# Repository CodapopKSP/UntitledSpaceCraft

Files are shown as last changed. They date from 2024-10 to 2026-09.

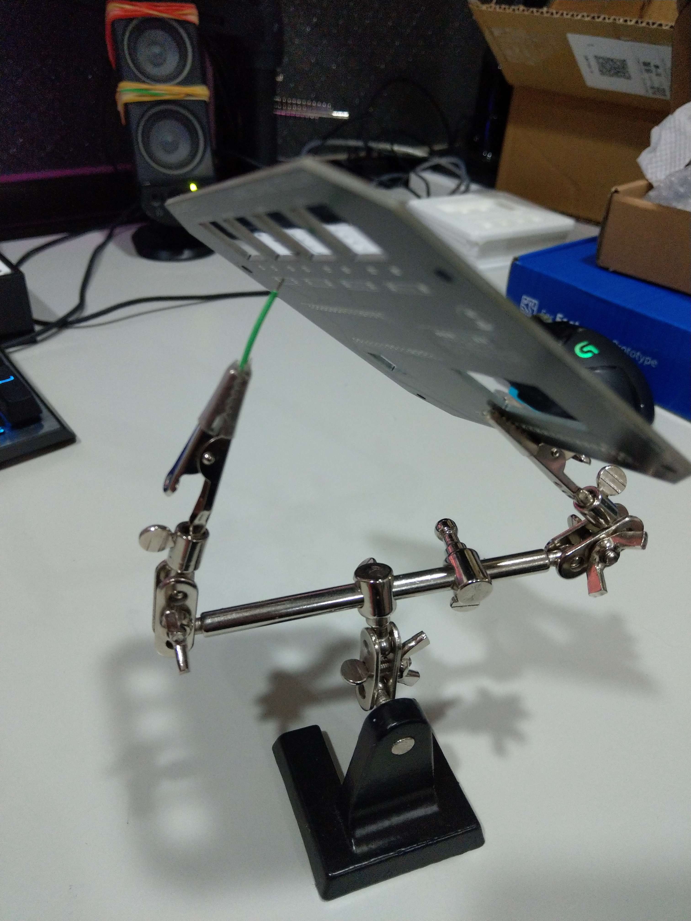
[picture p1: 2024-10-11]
Documents/Complete_Documentation_Source/Source Files/Images/solder_wire.jpg

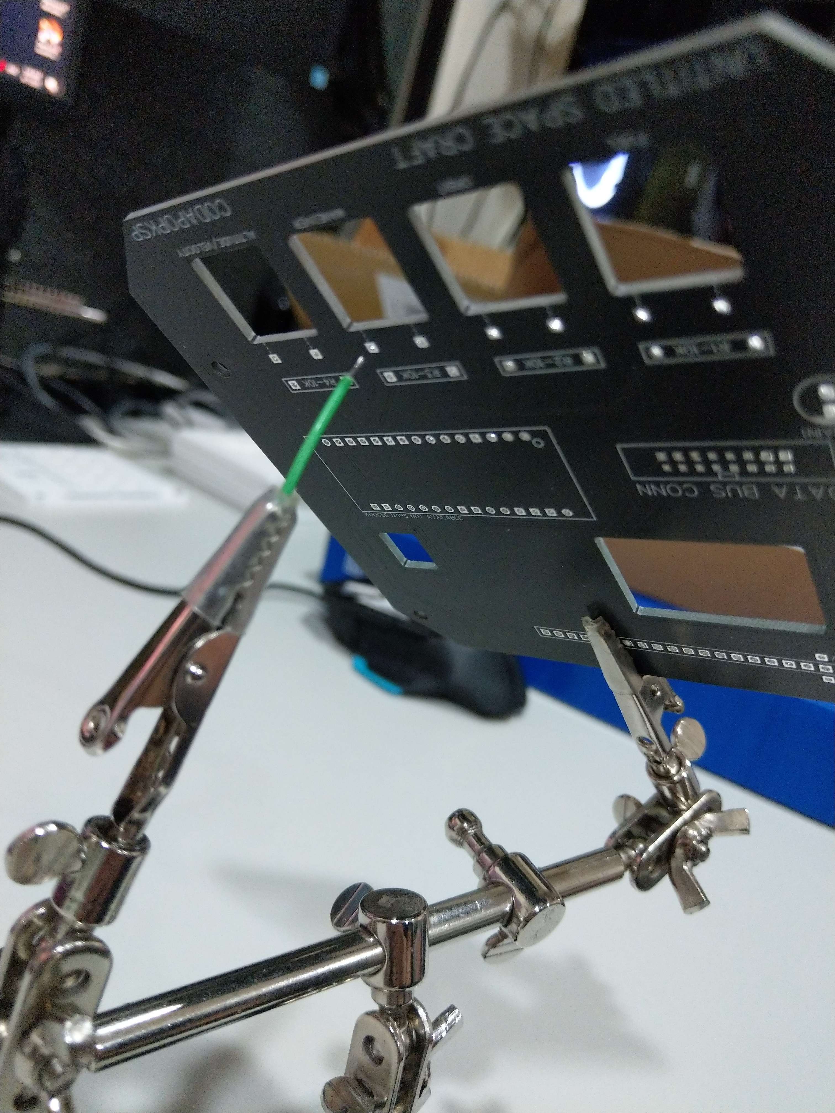
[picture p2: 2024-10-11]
Documents/Complete_Documentation_Source/Source Files/Images/solder_wire2.jpg

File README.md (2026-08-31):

# UntitledSpaceCraft

Animated Controller

Untitled Space Craft is a modular controller system originally developed by Codapop. For build instructions and information, check the releases for updated documentation.

## License

This project is licensed under the [GNU General Public License v3.0 (GPL-3.0)](https://www.gnu.org/licenses/gpl-3.0.html). 

### Important License Terms

While you are free to use, modify, and redistribute the files in this project under the terms of the GPL-3.0, please note the following restrictions regarding commercial use:

- **Commercial Use**: This project is open source for hobby builders and personal use. However, you **may not** sell the hardware or any products derived from this project without explicit permission from the original creator. 

- **Modification**: You are allowed to modify the files for personal or hobby projects.

- **Attribution**: If you use or adapt this project, please give appropriate credit by mentioning the original creator.

## Contributing

Contributions are welcome! If you'd like to contribute to this project, please fork the repository and submit a pull request.

## Contact

If you have any questions or need further clarification about the license or the project, feel free to contact me at untitledspacecraft.controllers@gmail.com.

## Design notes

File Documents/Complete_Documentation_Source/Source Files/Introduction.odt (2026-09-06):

Table of Contents | Page
Introduction | 1
Hardware | 2
System Diagram | 2
The Standard Module | 3
Containers | 4
Hubs | 5
Firmware | 6
Firmware Execution Flow | 6
Module Firmware | 7
CTRL | 7
DSPL | 7
Analog | 7
I²C Addresses | 8
Assembly | 9
Bill of Materials | 9
Required Tools | 13
Module Assembly | 14
Faceplate Fabrication | 14
Component Placement | 15
PCB Soldering | 17
Throttle Module | 19
Telemetry Module | 21
Joysticks | 22
EVA Module | 22
Adding the IC Chips | 22
Container Assembly | 23
Wiring | 23
Schematics | 24

Introduction

Untitled Space Craft is a brand of game controllers specialized for playing Kerbal Space Program and its derivatives, created by Codapop in 2021. This project is open source.

This document serves as a guide for those who choose to build their own USC controller.

The USC ecosystem is designed around a modular architecture. Individual control panels, referred to as modules, connect to a central Hub and communicate over a shared I²C bus. This allows builders to create anything from a small desktop controller with a single module to a full cockpit consisting of multiple containers and dozens of independent controls.

This manual covers the hardware, electronics, firmware, and assembly process required to build a USC controller. It includes mechanical drawings, schematics, bills of materials, firmware architecture, and assembly instructions. While basic soldering and electronics experience is recommended, every effort has been made to document the project thoroughly so that builders can understand not only how to assemble the controller, but also how it works and how to modify or extend it.

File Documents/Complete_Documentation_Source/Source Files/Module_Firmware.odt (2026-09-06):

Module Firmware

Each module has one or two microcontrollers with firmware that manages their module’s set of inputs and outputs. Typically, these are specialized based on Control (CTRL) or Display (DSPL), meaning buttons/switches or LED outputs respectively. The only alternative is the Telemetry module which runs an Arduino Nano that handles both as well as the screen drawing functionality.

Both types of firmware utilize the i2c protocol and use the TinyWire library.

CTRL

The CTRL firmware uses the ShiftIn library to collect inputs, as bits, which it stores in bytes. When requested by the master (Wire.requestFrom(ctrl_address, in_bytes);), it provides one or two bytes.

void onI2CRequest() {

TinyWire.send(bytes[0]);

TinyWire.send(bytes[1]); //Optional

}

DSPL

The DSPL firmware uses the ShiftRegister74HC595 library to drive LED arrays. When it receives data from the master in the form of bytes, it converts them into serial bits.

void onI2CReceive(int howMany){

bytes[0] = TinyWire.read();

bytes[1] = TinyWire.read(); //Optional

}

Analog

In the Analog firmware, digital inputs are collected and condensed into bytes in the same manner as CTRL firmware. Each joystick axis is read using the microcontroller's ADC, producing a 10-bit value. Because this value cannot fit into a single byte, each axis is transmitted as two bytes containing the high and low portions of the ADC value. It also sends a byte of other input data.

axis1 = analogRead(A1);

axis2 = analogRead(A2);

axis3 = analogRead(A3);

void onI2CRequest() {

TinyWire.send(bytes[0]); // Other inputs

TinyWire.send(highByte(axis1));

TinyWire.send(lowByte(axis1));

TinyWire.send(highByte(axis2));

TinyWire.send(lowByte(axis2));

TinyWire.send(highByte(axis3));

TinyWire.send(lowByte(axis3));

}

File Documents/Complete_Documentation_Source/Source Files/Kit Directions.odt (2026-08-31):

USC Kit Directions

Introduction

These directions will hopefully be all you need to build your own controller from the kit. As always, feel free to contact Codapop with any questions.

Materials

Some materials are necessary for all modules and others are specific to some modules. Specific modules will be noted.

• Soldering iron and all relevant materials (solder, flux, etc.)

• Wire (standard hobby gauge, ~22-24 AWG)

• Wire strippers/cutters

• Pliers

• Screwdriver, with different size tips

• Vise/vice or some reliable way to compress objects

• Tweezers (For SMT chips on all joystick modules)

• 8mm wrench (for all switches and 3mm LEDs)

• 9mm wrench (Analog Throttle and Rotation Throttle modules)

• 15mm wrench (Executive Actions, Stage, Abort modules)

• Ink (for lettering, black or your choice)

• A suitable way to clean the ink (I use acetone-based nail polish remover)

• Silicone caulk (clear or the color of your container)
• Multimeter

• A breadboard

• Arduino IDE software or similar

Pre-flight

Before you begin, it is recommended that you do a test fit of all the components by fitting them into the PCBs and acrylic. Keep in mind things such as the direction certain button pins might be facing relative to their corresponding holes in the PCB. If something doesn't fit, then it might not go there. When in doubt, just ask.

In general, the two most devastating failure modes are failing to properly solder the Data Bus Connection and putting a magnet in the wrong way, so it's a good idea to focus on these specifically. The magnets are also powerful enough to ruin the IC chips and arduino, so be careful.

Inking

With the kit should be a small piece of acrylic with different size font etched into it. You can use this for testing your ink and cleaning solution. I recommend using ink for a permanent marker, but you can use dry-erase markers for a very easy cleanup.

I personally just drip ink into the etchings with the paper still on. I dry the ink with a tissue and then peel off all the paper. I then clean up any extra ink using an acetone-based nail polish remover. Pure acetone will ruin the mirror finish.

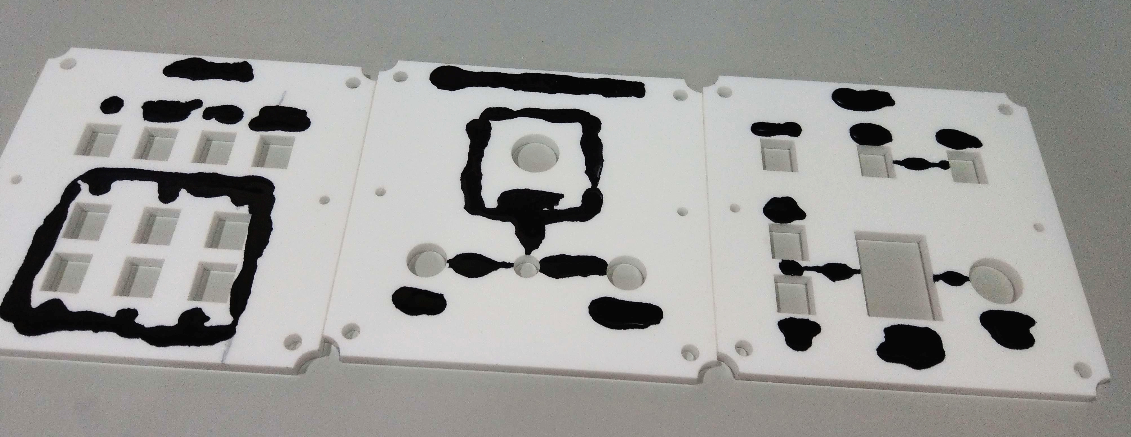
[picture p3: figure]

Container

The container houses the hub and wiring of the controller. It also needs to be fitted with magnets to hold the modules in place.

The placement of the hub should be pretty straightforward, but make sure the arduino's USB port and the 5V DC barrel jack are both pointing out of the holes in the back of the container. The arduino shouldn't be soldered directly to the board but instead should be inserted into two 15-pin sockets. The hub connects to the acrylic piece with one nut used as a spacer, so it is recommended to clip the bottoms of the wires for a clean fit.

The magnets should be pressed into place using a vise/vice. Ensure they are all going in the same way and that they are facing the correct orientation to accommodate the magnets in the modules. You should also try to keep the module side flush with the acrylic. Don't worry if the acrylic breaks around the magnet. As long as the magnet is in place, there is more than enough structural redundancy to maintain its integrity. If a larger piece snaps off, you may use super glue to reattach it, but be careful as the glue will ruin the finish. For the rest of the container, you may follow the container assembly guide.

Wiring

Constructing the wiring is a very crucial step with very little room for error. Your wiring should have a red line along it that you can use for orientation. First you should make sure that your ribbon cable is 16 wires rather than 20. If it's 20, then you will need to remove 4 from the non-red side.

After that you should cut the wire into segments to fit your container. This can be done by counting how many modules removed a particular module is away from the hub. The module that sits on top of the hub is 1. Every module that is adjacent to that module is 2. And every module that is adjacent to a 2 is a 3, and so on. Determining that, you should cut the wires as so:

1: 12cm

2: 24cm

3: 36cm

4: 48cm

If you hold the wire in front of you with the red line towards the left, then the connector should be facing away from you and with the notch facing up. Insert the cable into the connector and then press the connector together in the vise, causing it to combine with the cable. Every connector should be added in the same way, with the connectors always facing the same way in relation to the red line. This ensures that the wires can be used in either orientation and interchangeably. If any wires are crossed here, it can be disastrous for your ICs.

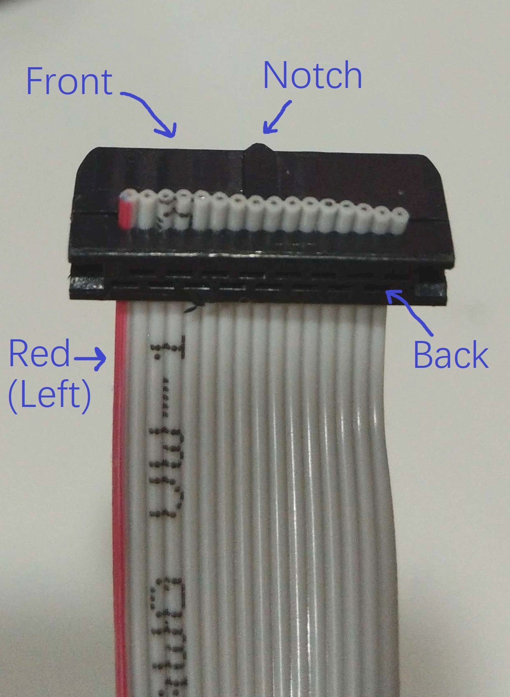
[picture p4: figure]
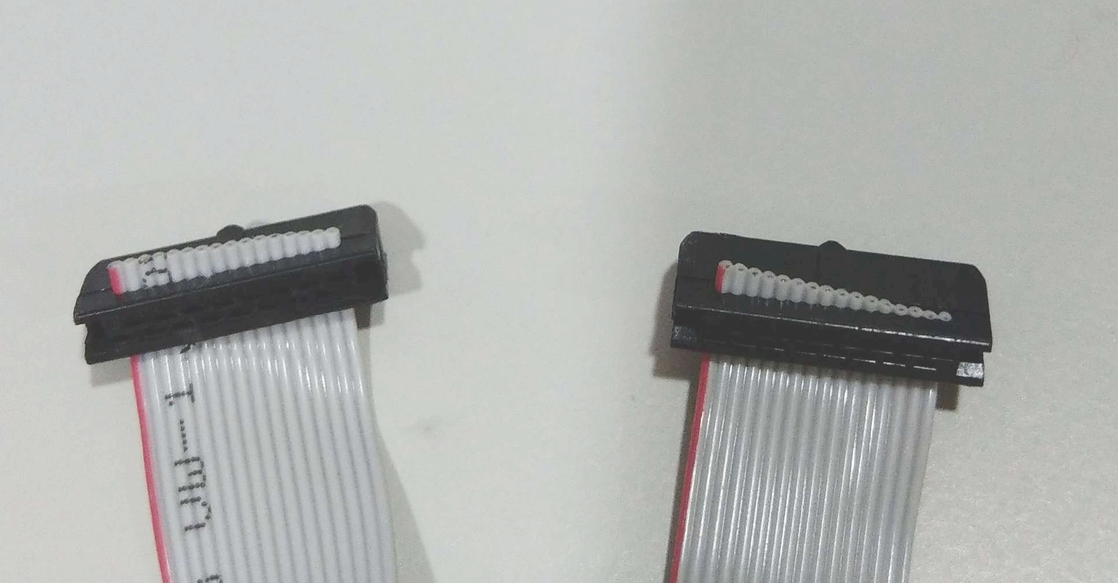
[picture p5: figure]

General PCB Standards

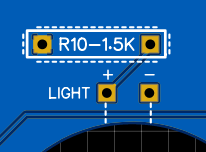
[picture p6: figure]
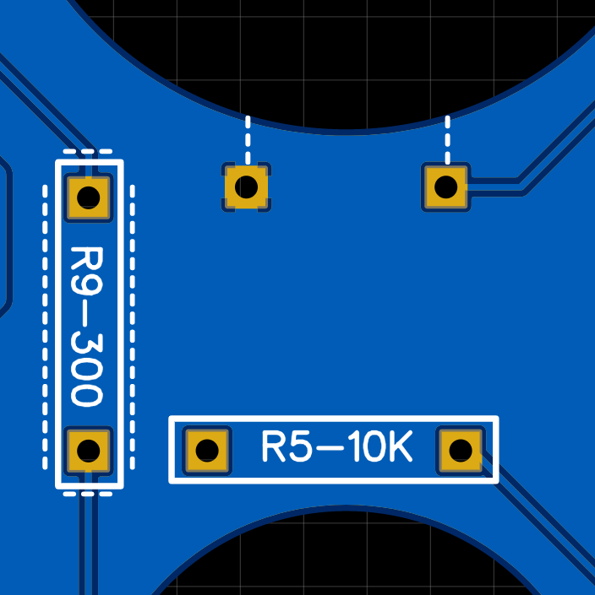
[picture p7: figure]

Most of the components are clearly marked on the silkscreen of the PCBs. Typically, resistors are considered 'special' if they aren't 10k Ohms. Resistors that are 10k Ohms are marked with a plain white rectangle (with 10k written in the middle). Special resistors, typically used for LEDs, are marked with a white rectangle with a dotted line outlining it. Parts that include an annode and cathode (LEDs, capacitors) are marked with a + for the annode and - for the cathode. The annode is sometimes marked on the component or sometimes indicated by a longer pin. Unmarked holes are usually for jumper wires, with their destination component indicated by dotted lines. You may need to refer to an online resistor color calculator to determine which resistors you have. All ICs should use sockets rather than being soldered to the board.

Building the Modules

This is the general workflow for most of the modules. This does not include the analog joystick modules, Throttle, Telemetry, or EVA.

After your fit check, it is recommended that you solder all of the PCB components first, all resistors, capacitors, chip sockets, Data Bus Conn, and diodes (but NOT the potentiometer for the Throttle module). They should be soldered to the side that has the writing. You can also attach all of the buttons, LEDs, and switches to the acrylic plates, leaving the joysticks for later. The switches with two pins should always have the two pins facing down (or away from the name of the module on the acrylic).

Please note: the square buttons have a tendency to prefer one side over the other. Now is a good time to look at them and pop them out and rotate them to make sure you are happy with everything.

At this point, you can cut/strip the jumper wires and solder them to the PCBs. They need to be soldered to the same side as all of the components. The result should be a PCB with many wires sticking out from the face with the writing. You will probably want to clip the ends on the bottom side and clean the excess flux with 99% isopropanol.

This is the point of no return for certain parts of the boards. You must ensure that the Data Bus Conn and ideally the chip sockets and electrolytic capacitors are all soldered correctly and securely, as they can be very difficult to fix later.

The PCBs attach to the acrylic using the screws, with one nut used as a spacer between the acrylic and the PCB. With everything secure, you can solder all of the jumper wires to their corresponding components.

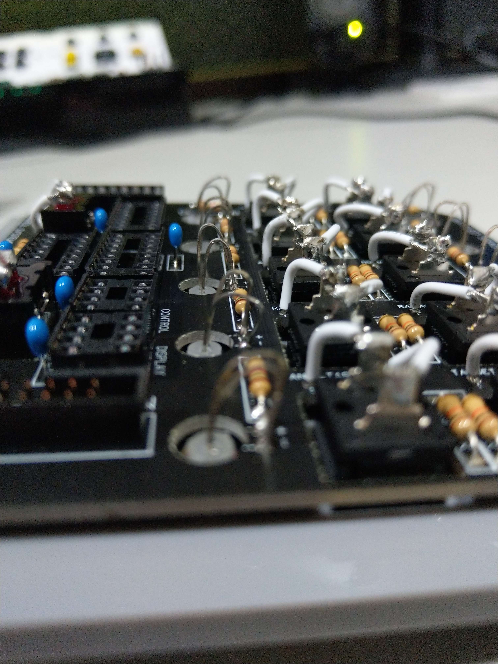
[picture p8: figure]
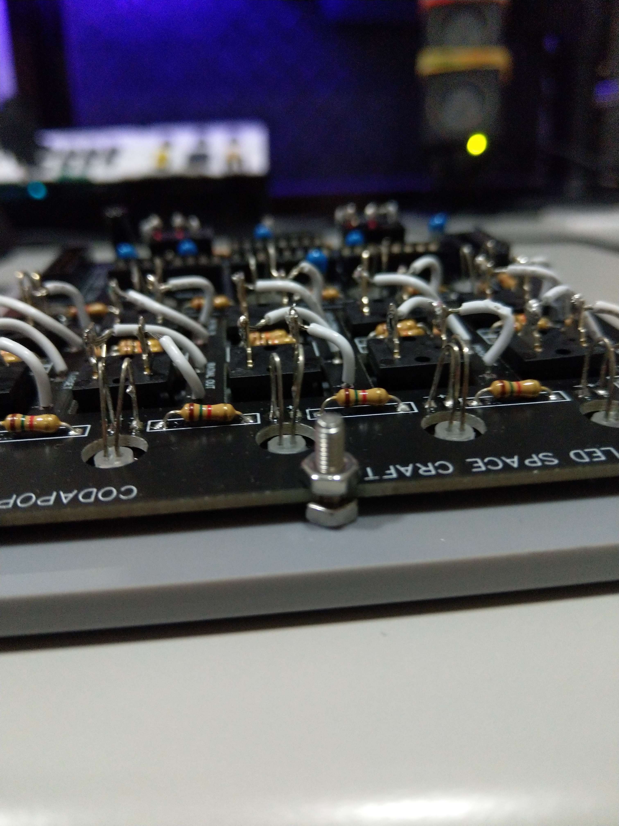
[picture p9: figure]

Of note: the 3mm LEDs with sockets (found on Control Systems, Action Groups, and Executive Actions) must be installed before securing the PCB to the acrylic, but the pins must remain straight until the PCB is secured. The pins can then be bent and inserted into the holes on the PCB that correspond with the annode and cathode and then soldered on the top side (opposite of the side that is typically soldered).

On the topic of these LEDs, there may be a few discrepancies in the resistor values, particularly with the blue LEDs which denote action groups. These might be labeled as 91k, but a recent change in the blue LED supplier has shifted these to requiring 62k resistors. Any and all 91k resistor markers on your PCBs should instead be 62k. The Executive Actions module that contains either 5 action groups or a mix of action groups with SAS/RCS controls might contain resistor markers that are labeled as both 91k and 10k. 91k (actually 62k) should be used if the LED it powers is a blue LED, and 10k should be used if the LED is orange.

Building the Analog Joystick Modules

The modules that contain joysticks are fairly similar to the standard modules, but the joysticks require special attention. Each joystick has 6 pins sticking out the sides (from the potentiometers) and should be fairly straightforward to wire up, as they just connect to the PCB with jumpers from Axis 1 and Axis 2. There are also 5 wires sticking out the side of the joystick: red, black, white, and two yellow. These go in the remaining empty holes next to the joystick labeled "Button" and "Axis 3". These holes are also labeled with letters that match the name of the color of the correct wire. R for red, B for black, and so on. I typically do this step after soldering the other wires to the PCB but before securing the PCB to the acrylic.

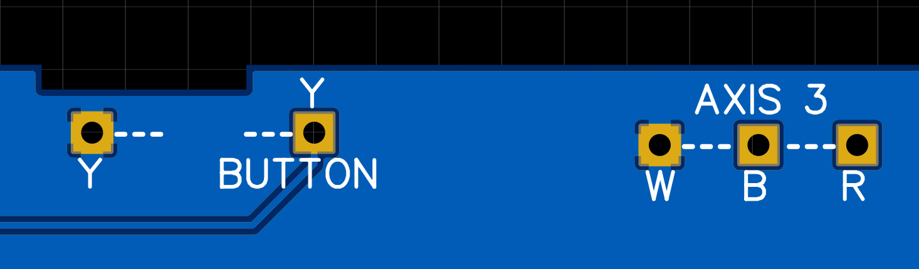
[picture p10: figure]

The rubber part of the joystick as well as the plastic ring cover must go on top of the acrylic, not underneath. These use screws that are easy to strip, so be careful. The two potentiometers on the sides of the joysticks can also be finetuned with a screwdriver and by checking that they are centered with a multimeter, but this shouldn't normally be necessary.

Building the Throttle Module

The Throttle module is perhaps the trickiest one and must be done with great care. Notably, this module requires a diode, which needs to be oriented with the dark line side of the diode on the same side as the white line printed on the PCB. Otherwise, you can solder all of the PCB components and wires like the standard modules, but skipping the potentiometer in particular.

The lever simply sticks onto the potentiometer, but this must be done after all other components are soldered and ready to be joined with the acrylic. Then you must stick the lever through both the acrylc and the PCB before attaching it to the potentiometer.

The lever must attach to the potentiometer with the lever in a particular orientation relative to the degree of rotation of the potentiometer dial. With the length of the lever providing an imaginary line, the cutout in the dial of the potentiometer must be perpendicular to this line, at least within a few degrees. The result should be, if the lever is oriented vertically, that the line in the potentiometer dial is horizontal. Be careful not to have it oriented upside down; the correct way should be obvious if you rotate the dial, with the bulk of the range of motion of the lever being on the side of the potentiometer with the pins. If you have already stuck the lever to the dial and aren't happy with the outcome, you can use pliers to wedge them apart and try again.

On production versions of this module, I like to add a piece of webbed material across the gap in the acrylic to prevent dust and debris from entering the hole as well as to break up the hole visually. It's not necessary, but it might be appealing to you; however, such material is not included with the kit.

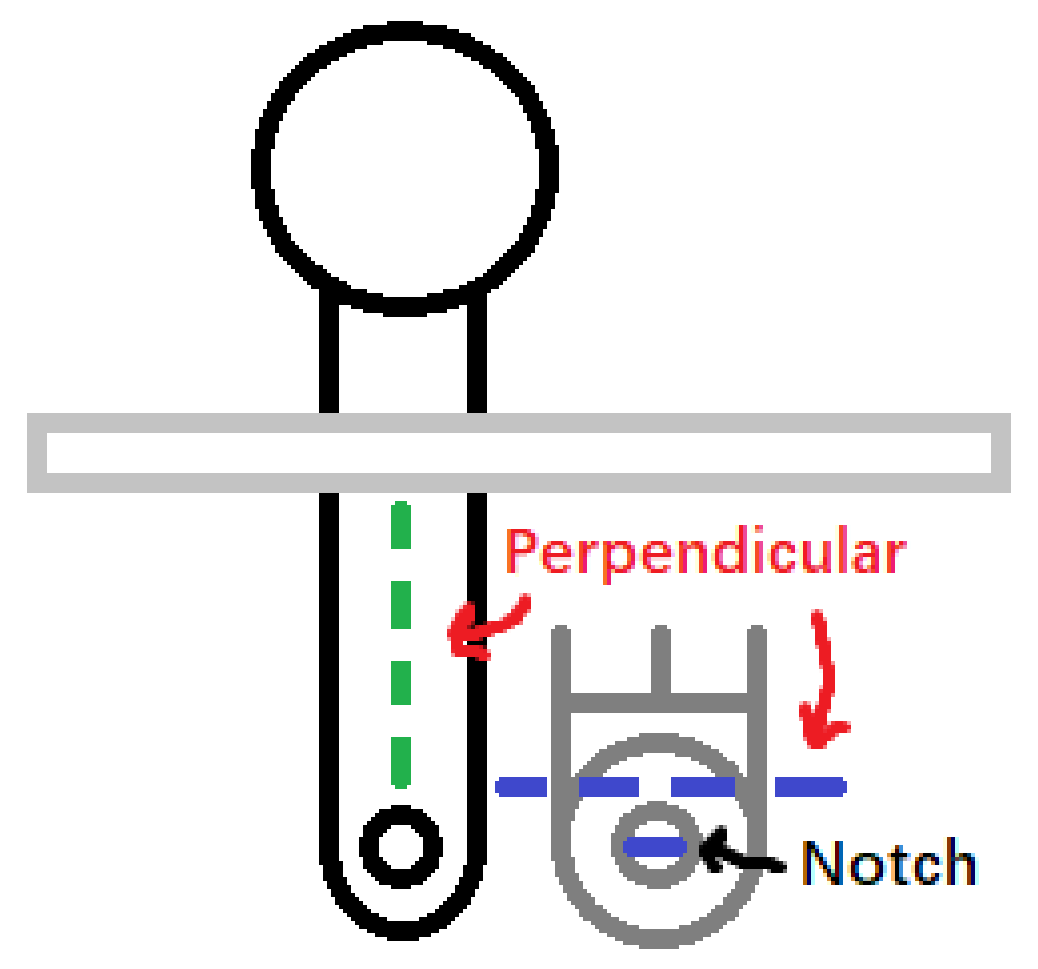
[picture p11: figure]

The Throttle module needs to be calibrated so that the game throttle reads full when the lever is all the way forward, and off when the lever is all the way back. This requires the arduino to be placed into the hub socket with the "Calibrate_Throttle" code loaded onto it.

Open the connection in the serial monitor. With the throttle switch in the 'enable' position, push the throttle all the way forward and note the value, then push it all the way back and note the value. Do the same with the switch in the 'precision' position.

These four values will need to be added to the main hub code in the definitions.h file. Open the file and locate the four variables named throttle_min, throttle_max, throttle_pmin, and throttle_pmax. Change the values corresponding to the values that you recorded. Add 5 to both of the min variables and subtract 5 from each of the max variables to ensure that the throttle can both successfully max out and reach zero.

Building the EVA Module

The EVA module is, for the most part, the same as the standard modules. The only difference is the 10 LED array for displaying EVA propellant. This array is organized with all of the annodes of the LEDs on one side (the side with the serial number sticker) and the cathodes on the other. The array should be soldered to the PCB after the PCB and acrylic have already been joined. Soldering it first might prevent it from fitting into the hole in the acrylic later. The resulting array should stick up out of the acrylic slightly. Notably, the resistors for this array might be shown as "??" rather than a value. That's because the LEDs from different suppliers display different brightness levels. If your kit contains 30k resistors, then those should be used here. If it contains several 1.2k resistors (more than a small number, as they're also used for a few other LEDs), then they should be used here.

Building the Telemetry Module

The Telemetry module includes a large LCD screen and requires an arduino nano to drive it. It is the only part of the controller that requires longer screws (M3 screws 25mm in length). After soldering the 20 pins to the back side of the screen, the screen can be secured to the acrylic, separated from the acrylic by two M3 washers and one M3 nut. Then the PCB must be separated from the screen by two more nuts. The final order should be: acrylic, washer, washer, nut, screen, nut, nut, PCB, nut. The arduino will need to be soldered directly to the board as it doesn't have enough clearance to use a socket. It is a good idea to test the arduino first before committing to soldering it. The USB port on the arduino should face away from center, towards the outside edge of the PCB.

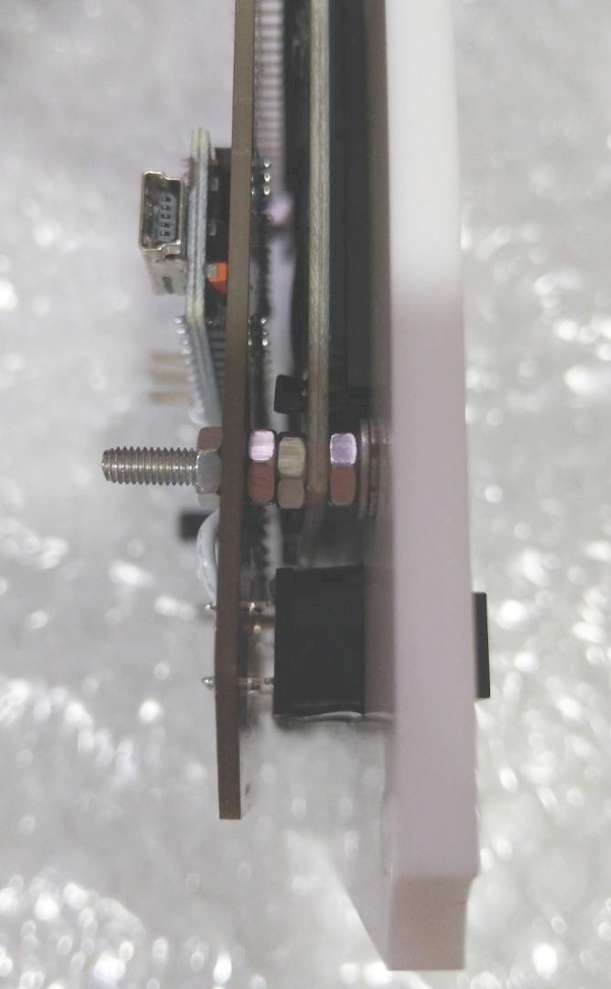
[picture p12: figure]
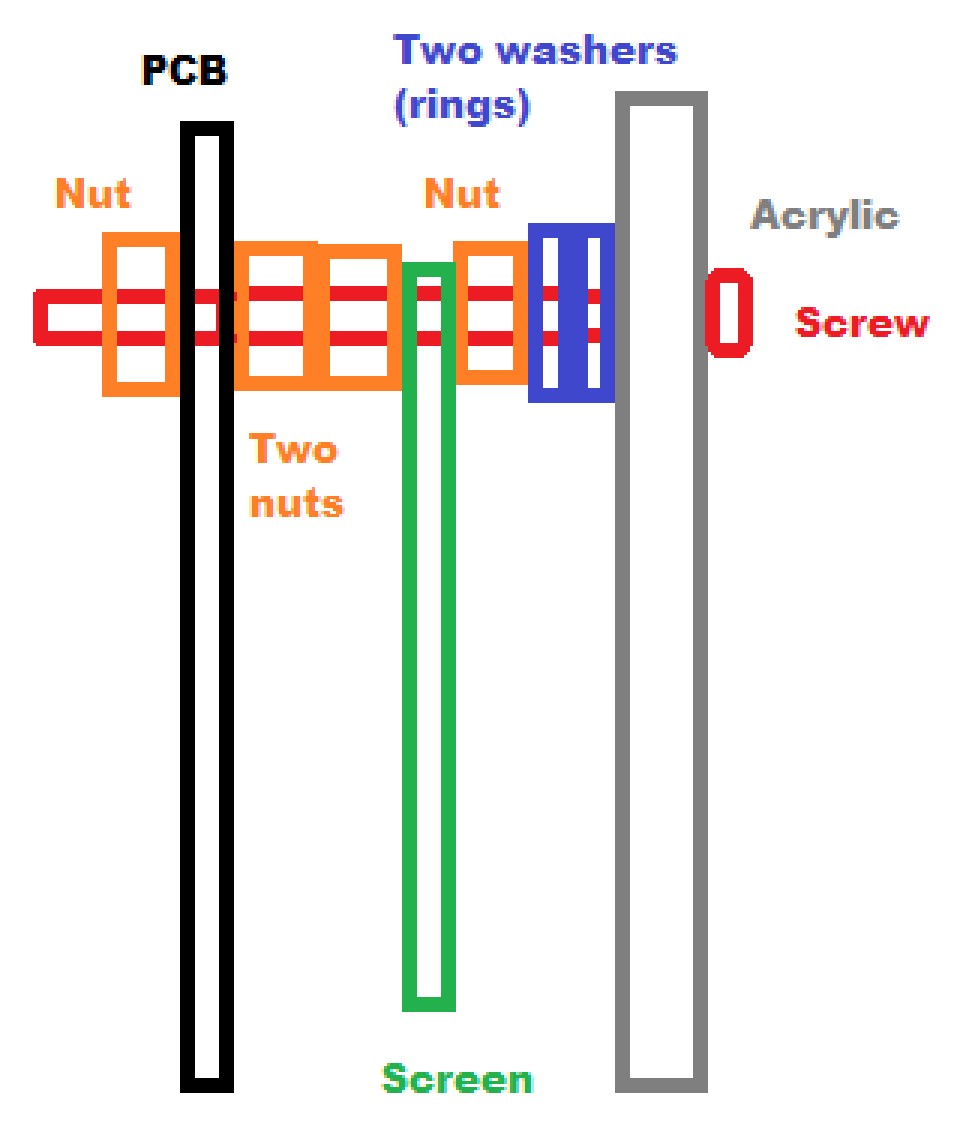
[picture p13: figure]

Adding the IC Chips

The ICs come in four different varieties. 74HC165, 74HC595, ATtinyX5, and ATtinyX4. The ATtiny chips might be listed on the PCB as, for instance, 'ATtiny25', but it is always fine to use a higher-number chip, in this case an ATtiny45. It is recommended to use sockets for all your ICs to greatly reduce the time cost of fixing a module in event of a failure, with the exception of the surface-mounted ATtinyX4.

The 74HC165 and 74HC595 chips require no preparation. Just bend the pins in slightly so they're nearly parallel and pop them into the sockets. Note the orientation of the chips: the half circle in the chip should match the half circle on the PCB. Mixing up the orientation could fry your chips. They also might make some unsatisfying clicks and pops while being pressed in, but in most cases this is normal.

The ATtinyX5 and ATtinyX4 chips are microcontrollers and need to be programmed. You can do this on a breadboard with directions for a simple ISP programmer circuit at the following link: https://www.circuits-diy.com/how-to-program-attiny85-with-arduino-uno/

The microcontroller (MC) chips are divided, if perhaps inefficiently, based on their function on each module. One ATtinyX5 controls the buttons (CTRL) while one drives the LED displays (DSPL). Analog joysticks are controlled with ATtinyX4. Open the included software in your arduino IDE and load it onto the ATtinyX5 chips, and then pop the chips into the sockets on the modules, being careful to note the orientation of the chips.

The ATtinyX4 chips on the Analog modules, being surface-mounted, typically need to be soldered onto the PCB before you can program them (unless you have an SMT chip socket of the right size). While soldering the chips to the PCBs, be sure to note the orientation; the small dot on the chip should match the small dot on the PCB. The programming holes on the PCB allow you to use the same circuit as you used for the ATtinyX5s, but you must plug the programming arduino into the Data Bus Conn to power the chip with a shared ground, or you can use alligator clips or similar to connect the 5V and GND. The connections on the arduino should go in the following order: Pin 10, 13, 12, 11, with pin 10 being the hole closest to the X.

Wrapping Up

After finishing a module, you may test it by loading the Hub code onto the arduino and connecting it to the module via the Data Bus Conn. To get it to connect in-game, you will need to make sure the 5V PSU is plugged in and that you have followed the Installation Guide to find the right COM port and update the .cgf file. It is a good idea to plug in the USB before plugging in the PSU and to unplug the PSU before unplugging the USB.

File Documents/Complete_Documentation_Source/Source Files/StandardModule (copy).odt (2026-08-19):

The Standard Module

The standard module is the form factor that governs the design of USC. Each module follows this same basic body plan.

It is 115mm square, with holes that are 4.875mm in diameter and 99mm apart from their centers, and 5mm thick. The hole diameter is a function of the diameter of the neodymium magnets, the flexibility of the medium (typically acrylic), and the thickness and settings of the laser. It is advised to do a test cut first to guarantee a proper friction fit.

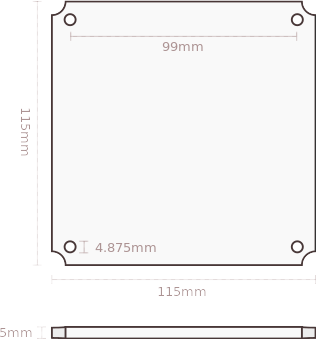
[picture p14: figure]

The module fits into the Module Slot. They have the same holes for magnets, 16mm apart where the modules touch. The slots are 105mm square, with a 5mm edge (or 10mm between them).

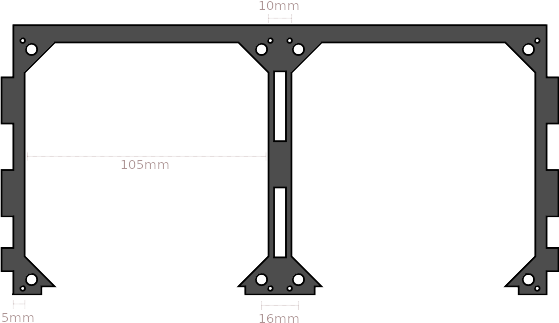
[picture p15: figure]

Containers

A container houses one or more standard modules and provides power and communication through the internal data bus.

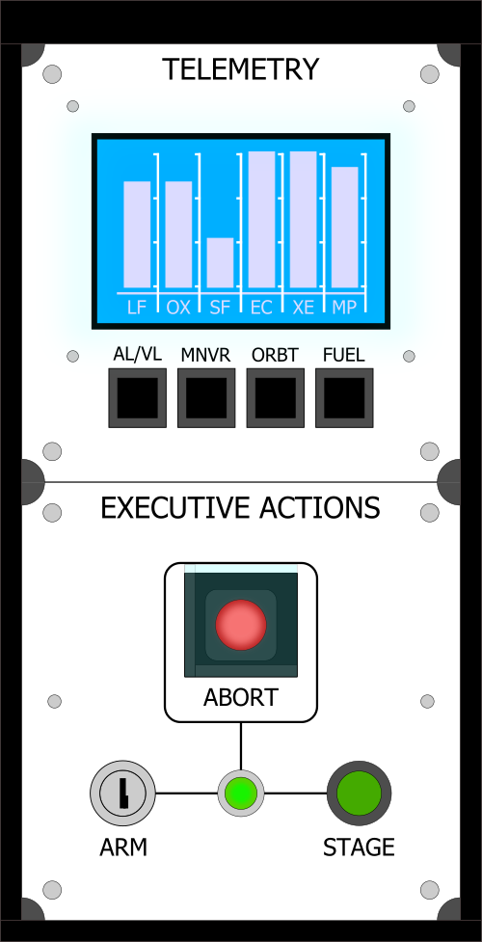
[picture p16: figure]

Containers have several measurements in common. Their pieces should all be 5mm thick. They are all 95.8mm tall on the back end. Containers that are two modules deep are 240mm long and 47.5mm tall on the short end. The measurements throughout the containers may not be exact; typically they are a few fractions of a millimeter shorter in order to account for the space needed for the caulk adhesive.

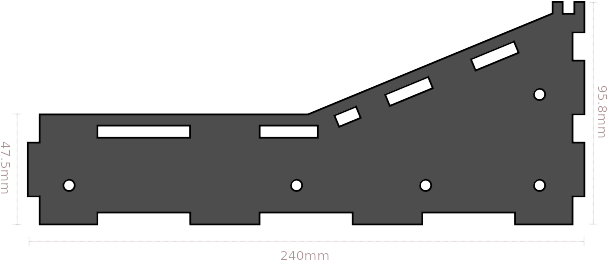
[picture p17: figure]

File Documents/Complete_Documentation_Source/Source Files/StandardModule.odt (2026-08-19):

The Standard Module

The standard module is the form factor that governs the design of USC. Each module follows this same basic body plan.

It is 115mm square, with holes that are 4.875mm in diameter and 99mm apart from their centers, and 5mm thick. The hole diameter is a function of the diameter of the neodymium magnets, the flexibility of the medium (typically acrylic), and the thickness and settings of the laser. It is advised to do a test cut first to guarantee a proper friction fit.

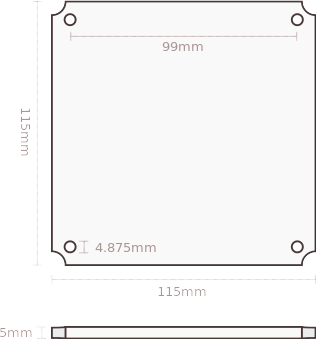
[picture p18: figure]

The module fits into the Module Slot. They have the same holes for magnets, 16mm apart where the modules touch. The slots are 105mm square, with a 5mm edge (or 10mm between them).

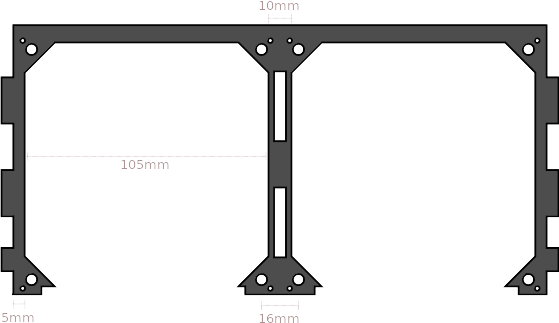
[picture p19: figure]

Containers

A container houses one or more standard modules and provides power and communication through the internal data bus.


Containers have several measurements in common. Their pieces should all be 5mm thick. They are all 95.8mm tall on the back end. Containers that are two modules deep are 240mm long and 47.5mm tall on the short end. The measurements throughout the containers may not be exact; typically they are a few fractions of a millimeter shorter in order to account for the space needed for the caulk adhesive.

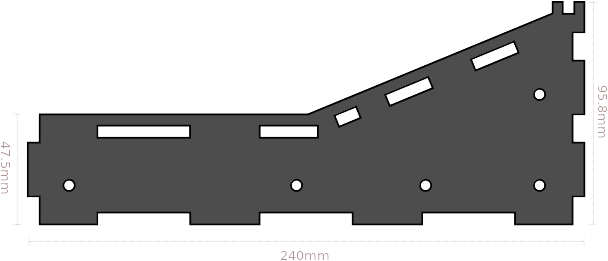
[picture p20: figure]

Hubs

Every container has exactly one Hub. A Hub is the core of the controller and supplies the serial connection to the computer and contains KSP-specific firmware.

A single hub consists of a consumer-grade microcontroller, typically Arduino Micro (or Arduino Nano on older USC models) as well as either four or eight connections to the i2c Data Bus to connect modules.

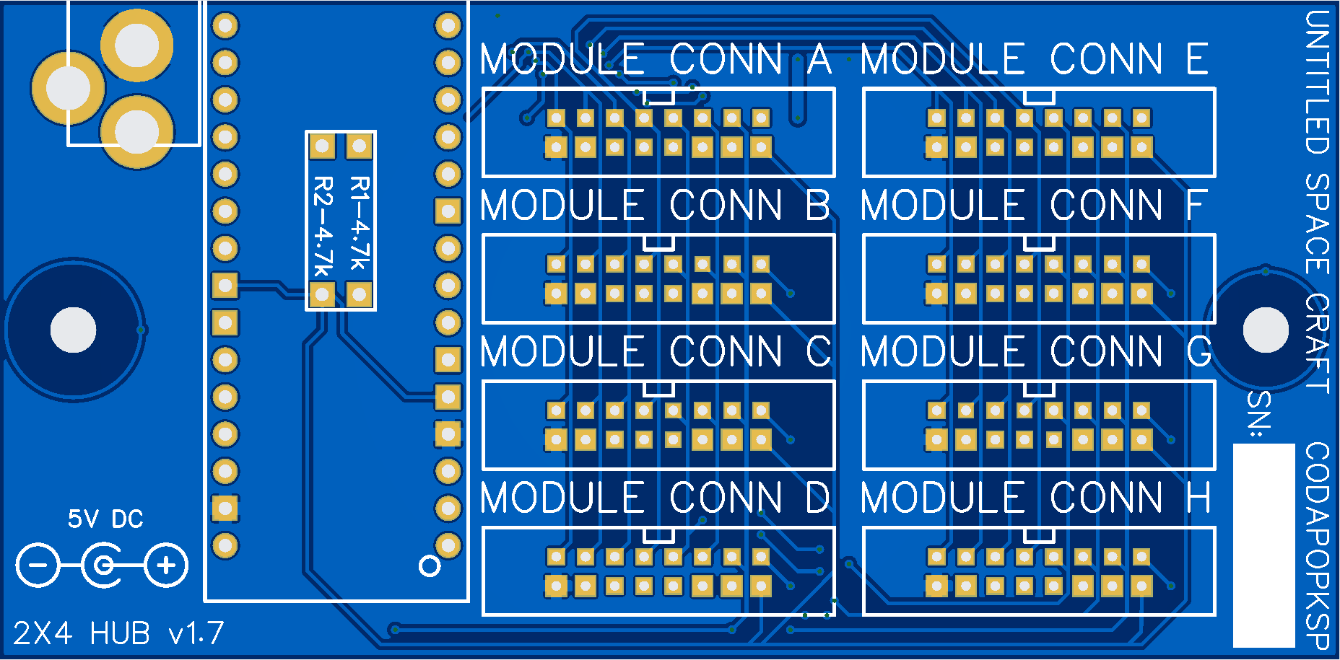
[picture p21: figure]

There are two sizes of hubs, Quad (aka: 1x4) and Octo (aka: 2x4). The two hub sizes are identical in every way other than the number of sockets that connect to the i2c bus. The 2.1mm barrel jack is center-positive polarity. The hub PCB is set up to support both Arduino Micro and Arduino Nano interchangeably, but the firmware expects Arduino Micro in order to make use of the HID capability for keyboard emulation (both in KSP Mode and in Emulation Mode).

The microcontroller is powered by the USB connection while the modules are powered by an external 5V PSU that connects via the 2.1mm barrel jack.

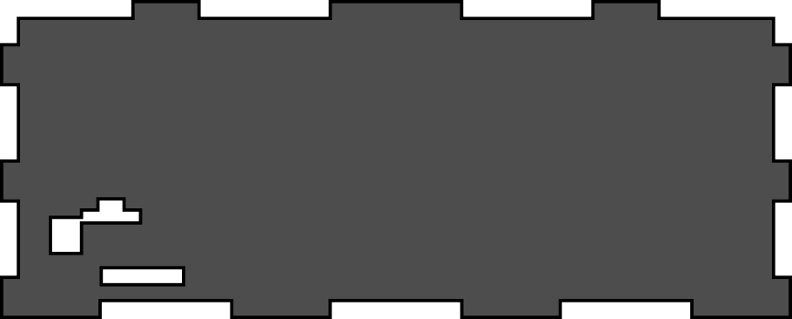
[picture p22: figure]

The microcontroller should not be soldered directly to the PCB; it should be socketed with two 1x15 pin header sockets, increasing the height by approximately 8.5mm in order to match the holes in the back of the container.

The PCB itself should have a gap of one standard 3M nut between it and the acrylic below it.

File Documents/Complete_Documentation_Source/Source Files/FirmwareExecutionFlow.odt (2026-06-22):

Firmware Execution Flow

Untitled Space Craft firmware is written in C/C++ and targets the Arduino platform. On power-up, the Hub initializes the hardware, discovers connected modules, and attempts to establish communication with Kerbal Simpit.

Once it is ready, it will repeatedly attempt to connect to Simpit for either KSP1 or KSP2. During this time, if 3 repeated inputs are detected, it will enter Keyboard Emulation mode. If the connection to Simpit is successful, it will enter KSP mode.

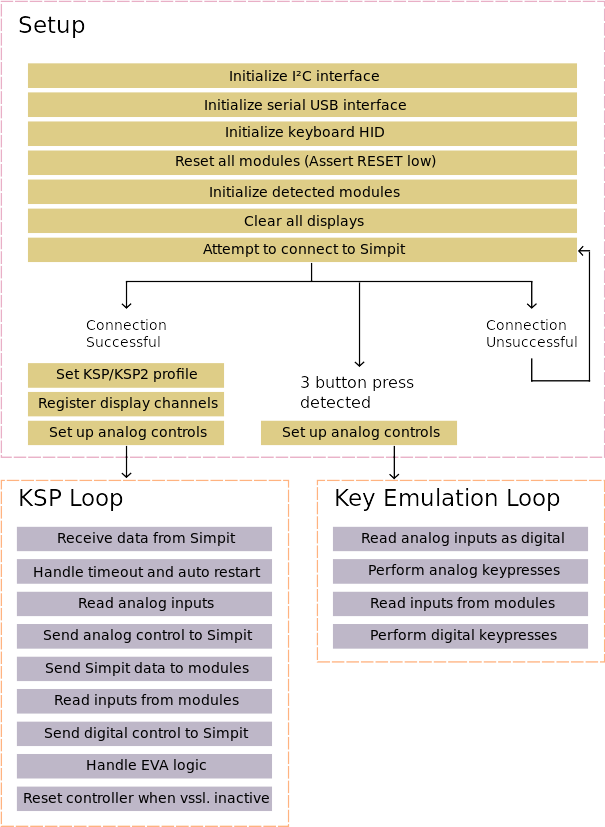
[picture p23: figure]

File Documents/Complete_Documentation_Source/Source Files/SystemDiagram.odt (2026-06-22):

System Diagram

Untitled Space Craft utilizes the Kerbal Simpit Revamped (https://github.com/Simpit-team/KerbalSimpitRevamped) mod for KSP in order to communicate with the game. The mod talks to controllers over the serial bus. Multiple containers can be connected to Simpit by editing the settings.cfg file in the GameData/KerbalSimpit folder.

Each container has a Hub, powered by Arduino Micro, with up to 8 modules driven by ATtiny microcontrollers. They communicate via the i2C protocol. Each module has one (for just control) or two (for control and display) addresses, designated with CTRL and DSPL.

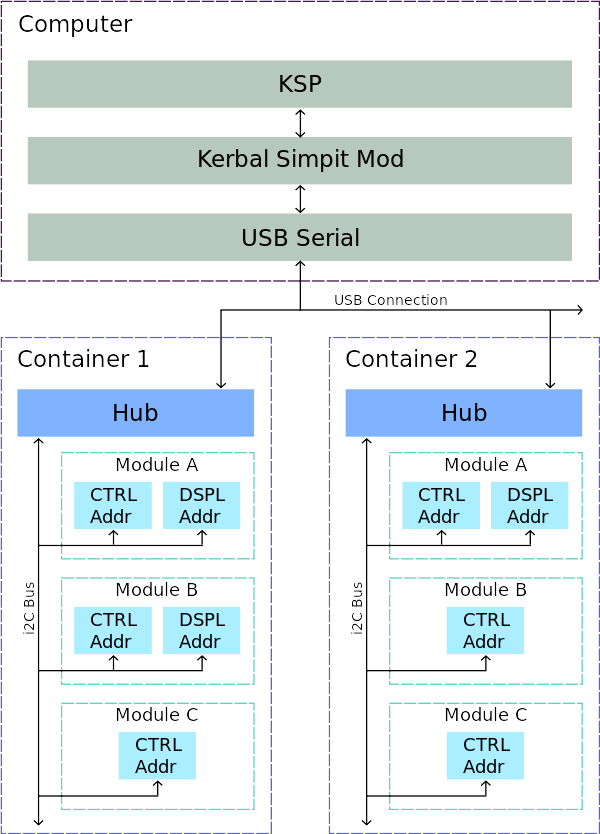
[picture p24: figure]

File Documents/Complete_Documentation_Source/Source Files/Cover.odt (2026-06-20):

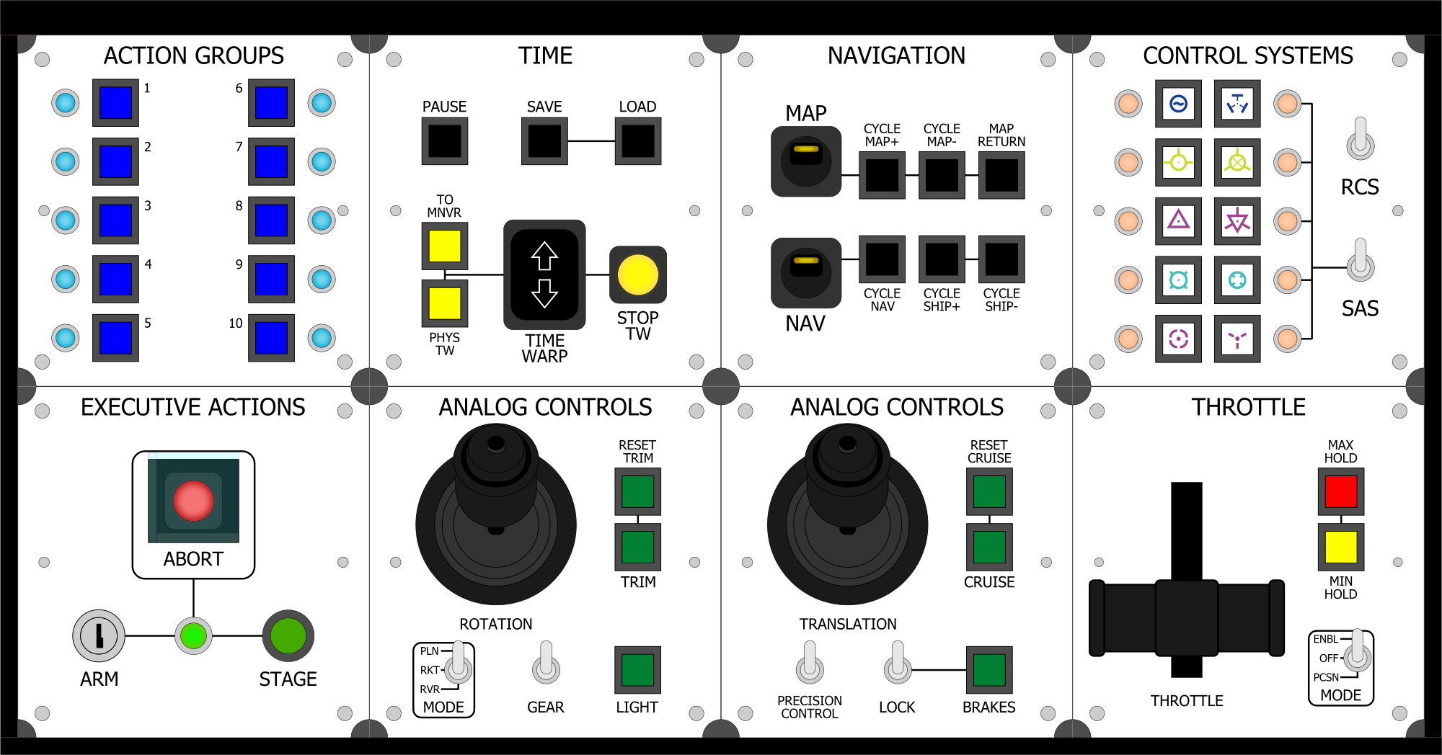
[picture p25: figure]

Untitled Space Craft

Complete Documentation

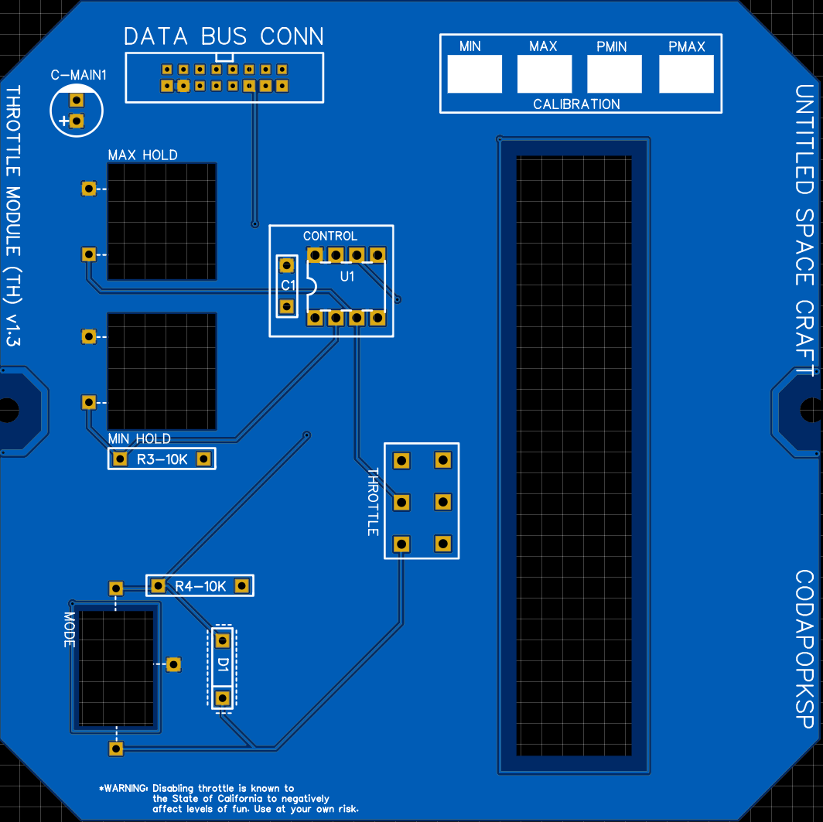
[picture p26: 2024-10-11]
Documents/Complete_Documentation_Source/Source Files/Images/throttle_pcb.png

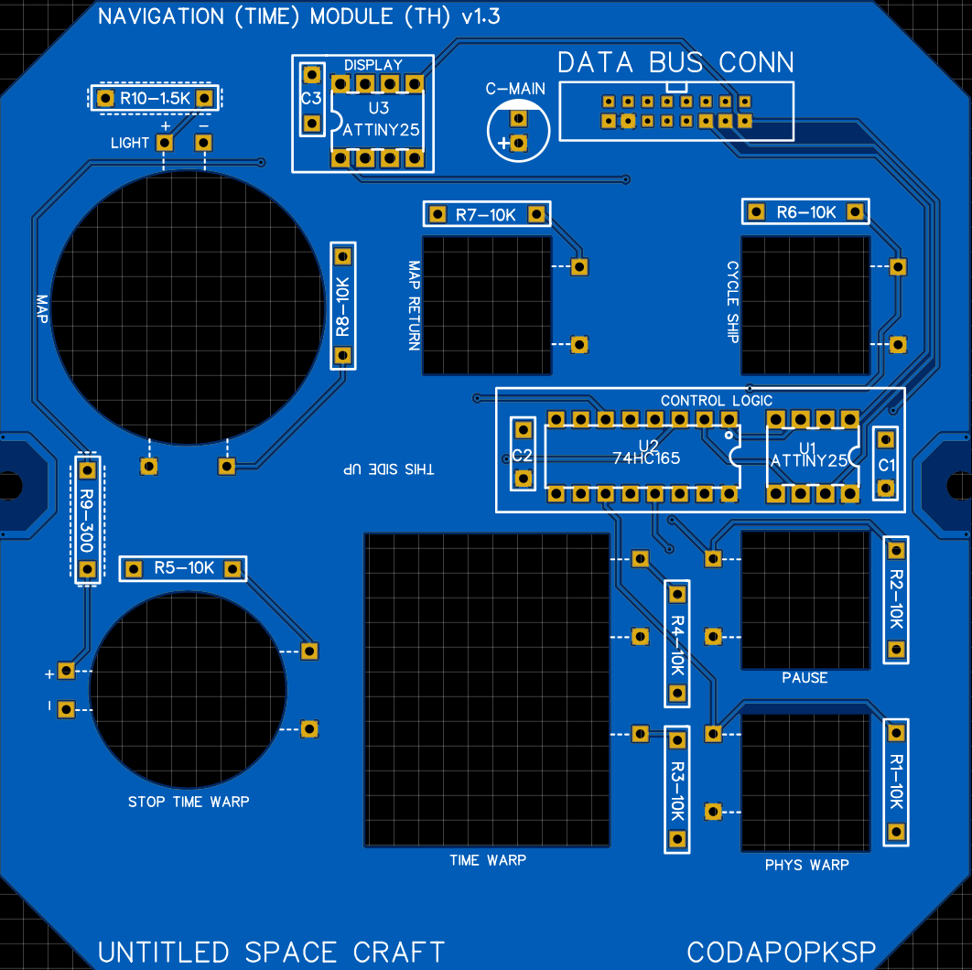
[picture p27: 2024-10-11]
Documents/Complete_Documentation_Source/Source Files/Images/pcb_full.png

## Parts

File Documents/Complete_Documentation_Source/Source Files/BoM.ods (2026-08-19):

Bill of Materials
All parts are through-hole, 2.54mm pitch unless otherwise stated.
Links are provided for convenience and may not correspond exactly to the recommended part. Always verify dimensions and specifications against the datasheet before ordering.
Module | Part | Qty | Value | Note
All Modules | 2.0mm Pitch 16pin Connector (https://www.ribbon-cable.com/product/16-pin-idc-flat-ribbon-cable-2mm-pitch/) | 1 | Socket | Standard module connector
 | Electrolytic Cap (https://en.wikipedia.org/wiki/Electrolytic_capacitor) | 1 | 10uf 16v | Main power decoupling
 | Round Neodymium Magnets | 4 | 5mm/5mm | Requires high precision
 | PCB | 1
 | Acrylic Face Plate | 1
 | Screw | 2 | 3M, 15mm | Telemetry needs 4
 | Nut | 4 | 3M | Telemetry needs 16
Abort | Circle Button (https://www.canal.com.tw/product/switches/push-switches/pbs-series-push-switch-up-to-1a-125vac) | 1 | Red, 12mm | OFF-(ON)
 | Safety Switch (https://business.walmart.com/ip/Safety-Toggle-Switch-SPDT-20-Amp-Transparent-Green/821345913) | 1 | Red
 | LED (https://protosupplies.com/wp-content/uploads/2019/10/LED-10mm-Green-5-Pack.jpg) | 1 | Red, 10mm
 | Chip Socket | 1 | 8 Pin
 | Resistor | 1 | 1.2K, 1/4W
 | Resistor | 1 | 10k, 1/4W
 | Ceramic Capacitor (https://i.sstatic.net/04Nrr.jpg) | 1 | 100nf | Type 104
 | Attiny25 | 1
Action Groups | Square Button (https://www.canal.com.tw/product/switches/push-switches/ps17-6-push-switch-3a-125vac) | 10 | Blue
 | LED (https://www.make-it.ca/wp-content/uploads/2021/09/3mm-leds-featured.jpg) | 10 | Blue, 3mm
 | LED Socket (https://www.aliexpress.com/item/1005007392371820.html?curPageLogUid=CcsVxI7aI7BB) | 10 | 3mm
 | Chip Socket | 2 | 8 Pin
 | Chip Socket | 4 | 16 Pin
 | Resistor | 10 | 10k, 1/4W
 | Resistor | 10 | 62k, 1/4W
 | Ceramic Capacitor | 6 | 100nf | Type 104
 | Attiny45 | 2
 | 74HC165 | 2
 | 74HC595 | 2
Analog | Square Button | 2 | Blue
 | Switch (https://media.cablematic.com/__sized__/images_1000/tg12700-03-thumbnail-1080x1080-70.jpg) | 2 | SPST
 | Switch | 1 | SPDT 3-Pos | ON-OFF-ON
 | JH-D400X Joystick (https://shop.pimoroni.com/products/3-axis-joystick-with-button?variant=40408724570195) | 1
 | Chip Socket | 1 | 14 Pin
 | Chip Socket | 1 | 16 Pin
 | Resistor | 7 | 10k, 1/4W
 | Ceramic Capacitor | 2 | 100nf | Type 104
 | Attiny24 | 1
 | 74HC165 | 1
Analog Throttle | Square Button | 2 | Blue
 | Switch | 1 | SPST
 | Switch | 1 | SPDT 3-Pos | ON-OFF-ON
 | JH-D400X Joystick | 1
 | Chip Socket | 1 | 14 Pin
 | Chip Socket | 1 | 16 Pin
 | Resistor | 6 | 10k, 1/4W
 | Ceramic Capacitor | 2 | 100nf | Type 104
 | Attiny24 | 1
 | 74HC165 | 1
 | Potentiometer | 1 | B20K
 | Potentiometer Cover Dial | 1
Camera | Square Button | 4 | Black
 | Square Button | 6 | White
 | Chip Socket | 1 | 8 Pin
 | Chip Socket | 2 | 16 Pin
 | Resistor | 10 | 10k, 1/4W
 | Ceramic Capacitor | 3 | 100nf | Type 104
 | Attiny45 | 1
 | 74HC165 | 2
Module | Part | Qty | Value | Note
Control Systems | Square Button | 10 | White
 | Switch | 2 | SPST
 | LED | 10 | Orange, 3mm
 | LED Socket | 10 | 3mm
 | Chip Socket | 2 | 8 Pin
 | Chip Socket | 4 | 16 Pin
 | Resistor | 22 | 10k, 1/4W
 | Ceramic Capacitor | 6 | 100nf | Type 104
 | Attiny45 | 2
 | 74HC165 | 2
 | 74HC165 | 2
Executive Actions (Control) | Square Button | 1 | White
 | Square Button | 2 | Blue
 | Circle Button | 1 | Green, 12mm | OFF-(ON)
 | LED Button (https://www.adafruit.com/product/1439) | 1 | Red, 16mm
 | Button Safety Cover (https://i.ebayimg.com/images/g/6vMAAOSwi8NlVT3R/s-l400.jpg) | 1 | 22x24mm
 | Switch | 2 | SPST
 | Key Switch (https://www.canal.com.tw/product/switches/keylock-switches/s1091b-Ø12) | 1 | 12mm
 | LED | 3 | Orange, 3mm
 | LED | 2 | Blue, 3mm
 | LED Socket | 5 | 3mm
 | Chip Socket | 2 | 8 Pin
 | Chip Socket | 2 | 16 Pin
 | Resistor | 1 | 1.2K, 1/4W
 | Resistor | 10 | 10k, 1/4W
 | Resistor | 2 | 62k, 1/4W
 | Ceramic Capacitor | 4 | 100nf | Type 104
 | Attiny45 | 2
 | 74HC595 | 1
 | 74HC165 | 1
Executive Actions (Groups) | Square Button | 5 | Blue
 | Circle Button | 1 | Green, 12mm | OFF-(ON)
 | LED Button | 1 | Red, 16mm
 | Button Safety Cover | 1 | 22x24mm
 | Key Switch | 1 | 12mm
 | LED | 5 | Blue, 3mm
 | LED Socket | 5 | 3mm
 | Chip Socket | 2 | 8 Pin
 | Chip Socket | 2 | 16 Pin
 | Resistor | 1 | 1.2K, 1/4W
 | Resistor | 7 | 10k, 1/4W
 | Resistor | 5 | 62k, 1/4W
 | Ceramic Capacitor | 4 | 100nf | Type 104
 | Attiny45 | 2
 | 74HC595 | 1
 | 74HC165 | 1
Executive Actions | Circle Button | 1 | Green, 12mm | OFF-(ON)
 | LED Button | 1 | Red, 16mm
 | Button Safety Cover | 1 | 24x26mm
 | Key Switch | 1 | 12mm
 | LED (https://www.pcboard.ca/image/cache/catalog/products/leds/5mm-led-assortment-02-800x800.jpg) | 1 | Green, 5mm
 | LED Socket | 1 | 5mm
 | Chip Socket | 1 | 8 Pin
 | Resistor | 1 | 300, 1/4W
 | Resistor | 1 | 1.2K, 1/4W
 | Resistor | 2 | 10k, 1/4W
 | Ceramic Capacitor | 1 | 100nf | Type 104
 | Attiny25 | 1
Module | Part | Qty | Value | Note
EVA | Square Button | 6 | White
 | Square Button | 5 | Green
 | LED Array (https://cdn.shpy.in/224437/1663567579971_SKU-4824_0.jpg?width=1200) | 1 | Green, 10 LED
 | Chip Socket | 2 | 8 Pin
 | Chip Socket | 4 | 16 Pin
 | Resistor | 10 | 1.2K, 1/4W
 | Resistor | 11 | 10k, 1/4W
 | Ceramic Capacitor | 6 | 100nf | Type 104
 | Attiny45 | 2
 | 74HC595 | 2
 | 74HC165 | 2
Navigation | Square Button | 6 | Black
 | LED Switch (https://cdn.shopify.com/s/files/1/0080/6617/0943/products/TB-SK0964_1000x1000.jpg?v=1571712072) | 2 | Yellow
 | Chip Socket | 1 | 8 Pin
 | Chip Socket | 1 | 16 Pin
 | Resistor | 2 | 1.5k, 1/4W
 | Resistor | 8 | 10k, 1/4W
 | Ceramic Capacitor | 2 | 100nf | Type 104
 | Attiny45 | 1
 | 74HC165 | 1
Natigation (Time) | Square Button | 2 | Black
 | Square Button | 2 | Yellow
 | LED Button | 1 | Yellow, 16mm
 | D36 LED Switch | 1 | Yellow
 | 6P Rocker Switch (https://twcn.rs-online.com/web/p/rocker-switches/0119704) | 1
 | Chip Socket | 2 | 8 Pin
 | Chip Socket | 1 | 16 Pin
 | Resistor | 1 | 300, 1/4W
 | Resistor | 1 | 1.5k, 1/4W
 | Resistor | 8 | 10k, 1/4W
 | Ceramic Capacitor | 3 | 100nf | Type 104
 | Attiny45 | 2
 | 74HC165 | 1
Rotation | Square Button | 3 | Green,
 | Switch | 1 | SPST
 | Switch | 1 | SPDT 3-Pos | ON-OFF-ON
 | JH-D400X Joystick | 1
 | Chip Socket | 1 | 14 Pin
 | Chip Socket | 1 | 16 Pin
 | Resistor | 6 | 10k, 1/4W
 | Ceramic Capacitor | 2 | 100nf | Type 104
 | Attiny24 | 1
 | 74HC165 | 1
Rotation (Throttle) | Square Button | 2 | Green,
 | Switch | 1 | SPST
 | Switch | 1 | SPDT 3-Pos | ON-OFF-ON
 | JH-D400X Joystick | 1
 | Chip Socket | 1 | 14 Pin
 | Chip Socket | 1 | 16 Pin
 | Resistor | 4 | 10k, 1/4W
 | Ceramic Capacitor | 2 | 100nf | Type 104
 | Attiny24 | 1
 | Potentiometer (https://cdn1.botland.store/98376-pdt_540/rotary-potentiometer-20kohm-linear-1-5w-b20k-5szt.jpg) | 1 | B20K
 | Potentiometer Cover Dial | 1
Module | Part | Qty | Value | Note
Stage | Circle Button | 1 | Green, 12mm | OFF-(ON)
 | Safety Switch | 1 | Green,
 | LED | 1 | Green, 10mm
 | Chip Socket | 1 | 8 Pin
 | Resistor | 1 | 150, 1/4W
 | Resistor | 1 | 10k, 1/4W
 | Ceramic Capacitor | 1 | 100nf | Type 104
 | Attiny25 | 1
Telemetry | Square Button | 4 | Black
 | LCD Screen (https://infodatasheet.com/st7920-lcd-128x64-datasheet.html) | 1 | 128x64 | ST7920 driven
 | Header Pins | 1 | 1x20 Pin | Not socket
 | Resistor | 4 | 10k, 1/4W
 | Washer | 8 | 3M | Depends on thickness
 | Arduino Nano | 1
Throttle | Square Button | 1 | Yellow
 | Square Button | 1 | Red
 | Switch | 1 | SPDT 3-Pos | ON-OFF-ON
 | Potentiometer (https://c1.neweggimages.com/ProductImageCompressAll1280/A27C_1_201711291304733131.jpg) | 1 | B20k, 6 Pin | Two parallel channels
 | Throttle Lever | 1 |  | 3D printed
 | Throttle Friction Mechanism | 1 |  | 3D printed
 | Chip Socket | 1 | 8 Pin
 | Resistor | 2 | 10k, 1/4W
 | Diode (https://images.tcdn.com.br/img/img_prod/557243/diodo_retificador_1n4148_1379_2_84405ccb67faa74bc7f9ee7afd4bd90a.png) | 1 | 1N4148
 | Ceramic Capacitor | 1 | 100nf | Type 104
 | Attiny25 | 1
Time | Square Button | 3 | Black
 | Square Button | 2 | Yellow
 | LED Button | 1 | Yellow, 16mm
 | 6P Rocker Switch | 1
 | Chip Socket | 2 | 8 Pin
 | Chip Socket | 1 | 16 Pin
 | Resistor | 1 | 300, 1/4W
 | Resistor | 8 | 10k, 1/4W
 | Ceramic Capacitor | 3 | 100nf | Type 104
 | Attiny45 | 2
 | 74HC165 | 1
Translation | Square Button | 3 | Green,
 | Switch | 2 | SPST
 | JH-D400X Joystick | 1
 | Chip Socket | 1 | 14 Pin
 | Resistor | 5 | 10k, 1/4W
 | Ceramic Capacitor | 1 | 100nf | Type 104
 | Attiny24 | 1
Utility (Navigation) | Square Button | 2 | Black
 | Square Button | 5 | Green
 | D36 LED Switch | 1 | Yellow
 | LED Array | 1 | Green, 10 LED
 | Chip Socket | 2 | 8 Pin
 | Chip Socket | 3 | 16 Pin
 | Resistor | 10 | 1.2K, 1/4W
 | Resistor | 1 | 1.5k, 1/4W
 | Resistor | 8 | 10k, 1/4W
 | Ceramic Capacitor | 5 | 100nf | Type 104
 | Attiny45 | 2
 | 74HC595 | 2
 | 74HC165 | 1
Module | Part | Qty | Value | Note
Utility (Time) | Square Button | 3 | Black
 | Square Button | 5 | Green
 | LED Array | 1 | Green, 10 LED
 | Chip Socket | 2 | 8 Pin
 | Chip Socket | 3 | 16 Pin
 | Resistor | 10 | 1.2K, 1/4W
 | Resistor | 8 | 10k, 1/4W
 | Ceramic Capacitor | 5 | 100nf | Type 104
 | Attiny45 | 2
 | 74HC595 | 2
 | 74HC165 | 1
Quad Hub | 2.0mm Pitch 16pin Connector | 4 | Socket | Standard module connector
 | Resistor | 2 | 4.7k, 1/4W
 | Nut | 6 | 3M
 | Arduino Micro | 1 |  | Can be substituted with a Nano
 | Header Sockets | 2 | 15 Pin, Socket | For the arduino to slot into
 | Barrel Jack | 1 | 2.1mm
Octo Hub | 2.0mm Pitch 16pin Connector | 8 | Socket | Standard module connector
 | Resistor | 2 | 4.7k, 1/4W
 | Nut | 6 | 3M
 | Arduino Micro | 1 |  | Can be substituted with a Nano
 | Header Sockets | 2 | 15 Pin, Socket | For the arduino to slot into
 | Barrel Jack | 1 | 2.1mm
Miscellaneous | Power Supply | 1 | 5V | Center 5V, Sleeve ground
 | Micro USB cable | 1
 | Neodymium Magnets | 10 | 5mm/5mm
 | Ribbon Cable | 2-3m | 16 wire, 1mm | Depending on size
 | Ink | 1 | Black | Alcohol or acetone based
 | Acrylic Container | 1 |  | Depending on size
 | 2.0mm Pitch 16pin Connector (https://www.ribbon-cable.com/product/16-pin-idc-flat-ribbon-cable-2mm-pitch/) | 2-16 | Pin | Two per module
Required Tools
• Soldering iron and all relevant materials (solder, flux, etc.)
• Wire (standard hobby gauge, ~22-24 AWG)
• Wire strippers/cutters
• Pliers
• Screwdriver, with different size tips
• Vise/vice or some reliable way to compress objects
• 8mm wrench (for all switches and 3mm LEDs)
• 9mm wrench (Analog Throttle and Rotation Throttle modules)
• 15mm wrench (Executive Actions, Stage, Abort modules)
• Ink (for lettering, black or your choice)
• A suitable way to clean the ink (such as acetone-based nail polish remover)
• Silicone caulk (clear or the color of your container)
• A breadboard
• Arduino IDE software or similar
• Multimeter

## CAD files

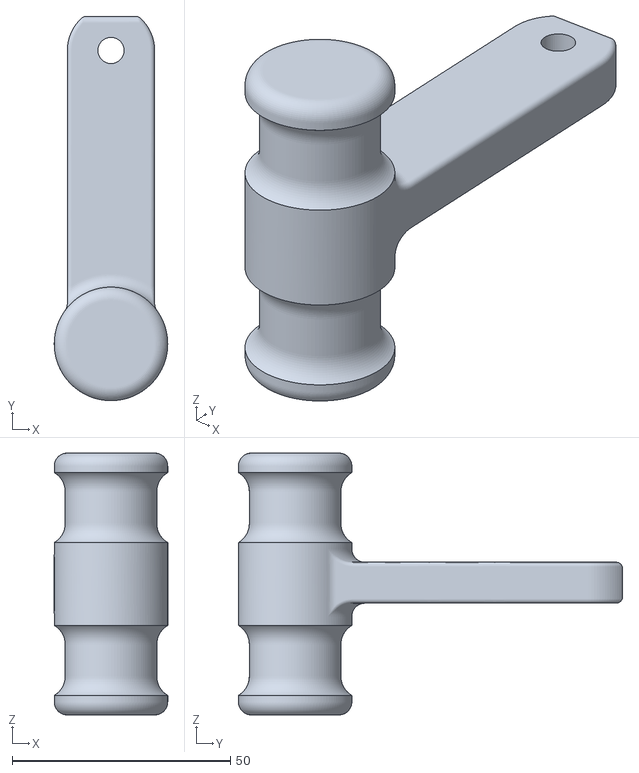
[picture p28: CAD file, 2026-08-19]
STLs/Throttle Lever.stl
26.0 x 88.0 x 60.0

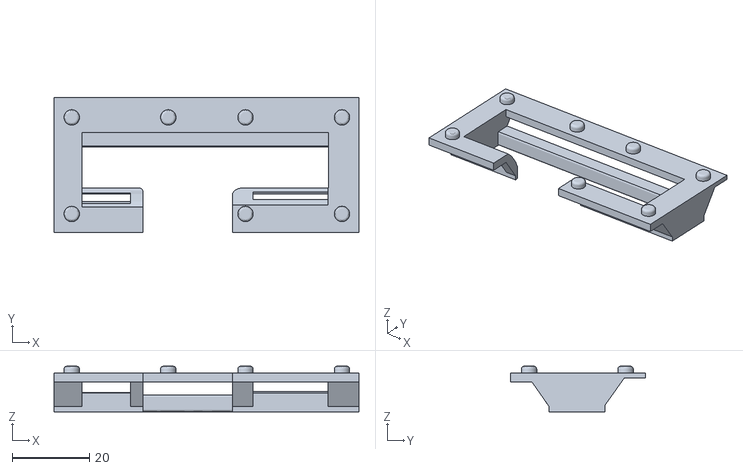
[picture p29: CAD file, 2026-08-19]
STLs/Throttle Guard.stl
79.0 x 35.0 x 11.8

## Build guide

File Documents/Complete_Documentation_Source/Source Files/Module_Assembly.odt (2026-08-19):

Module Assembly

Untitled Space Craft modules follow a consistent manufacturing design language, the process of which can be separated into three parts: Faceplate fabrication, component placement, and PCB soldering.

Faceplate Fabrication

These instructions are for if you are using acrylic for the faceplates. If you are using another material, then you will have to modify these instructions to fit your use case.

Faceplates should be laser cut from 5mm acrylic. A suitably powerful laser should be used to prevent the resulting cuts from becoming a pyramid shape. The faster the cut the less the surrounding material gets burned by an unfocused laser.

Inking the faceplates involves liberally applying ink to the etched lines so that the ink fills all the gaps. It is recommended to clean the burnt acrylic dust out of the gaps first.

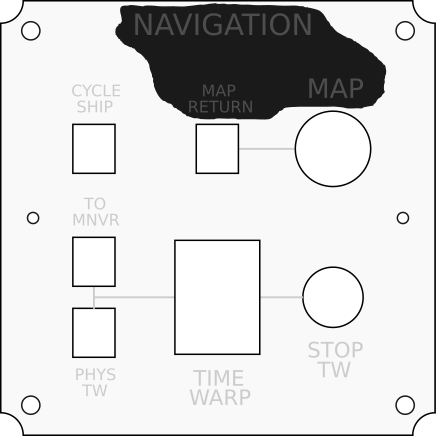
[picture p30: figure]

Any solvent-based ink can be used, such as alcohol-based or acetone-based, typically used in dry-erase markers or permanent markers. Inking can be performed with or without the paper covering. After applying the ink, wipe the excess off with a tissue and wait for the rest to dry. Once it has dried, you can remove any remaining excess using the same solvent as your ink.


Magnets can be added to the acrylic by pressing them in with a vise or similar compression tool. Magnets should be inserted with the NORTH side UP and pushed in from the top side to ensure the side that contacts the container is flush. Each magnet is 5mm in diameter and 5mm thick.

Component Placement

Most modules use just a handful of components, with a few specialty parts that are module- or function-specific.

Common buttons include the Square Button (https://www.canal.com.tw/product/switches/push-switches/ps17-6-push-switch-3a-125vac), Circle Button (https://www.canal.com.tw/product/switches/push-switches/pbs-series-push-switch-up-to-1a-125vac), LED Button (https://www.adafruit.com/product/1439), and the JH-D400X Joystick (https://shop.pimoroni.com/products/3-axis-joystick-with-button?variant=40408724570195). In general, components have an orientation in which they should be inserted into the acrylic, which depends both on the function of the component as well as its pin/wire placement. These orientations are best determined by checking the PCBs which have dotted lines indicating where wires should connect, which should be matched by the location of the pins on the component.

Square Buttons are about 14mm square on the surface, but underneath they are 11.85mm by 11mm. They fit into a hole 13mm x 11.2mm, with the extra space being taken up by the wings on either side. These wings compress to provide a stronger friction fit. However, they will typically only compress on one side, so it is worth making sure that compression happens on the same side uniform across your controller. The bottom side is preferred so the hole is better covered towards the user.

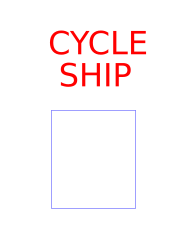
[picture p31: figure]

Circle Buttons are 15mm in diameter on the top and 11.5mm in diamater on the bottom. They fit into a hole 12mm in diameter.

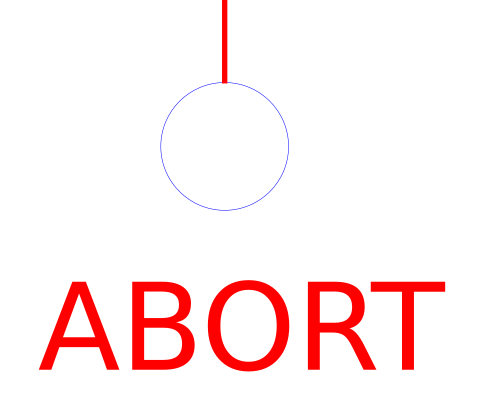
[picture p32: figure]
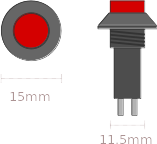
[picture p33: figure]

LED Buttons are 18mm in diameter on top and 15mm in diameter on the bottom. They have two sets of pins, one for the button and one for the LED. The pins for the LED are designated with + and – which should line up with the + and – on the PCB.

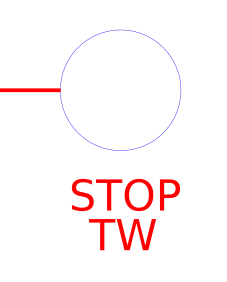
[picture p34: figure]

LED Switches are harder to source, but the ones used in production builds fit into a hole 20mm in diameter and have a similar 4-pin layout as the LED Buttons.

Switches come in a few varieties but they all share the same basic body plan, 13.2mm by 8mm at the base, with a threaded spire that is 5.9mm in diameter. They fit into a hole that is 6mm in diameter.

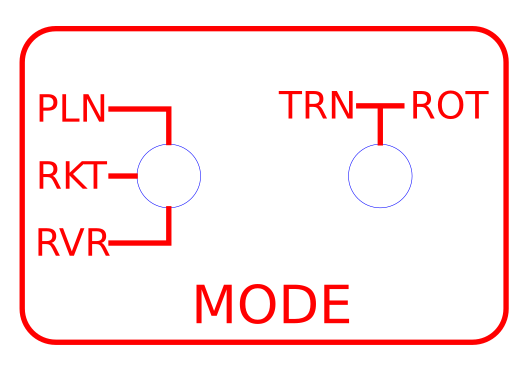
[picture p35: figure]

The JH-D400X Joystick is a complex part with 3 potentiometers and a pushbutton. Its dimensions are well-documented.

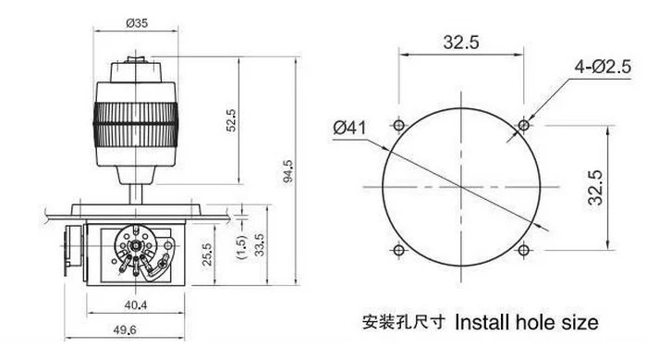
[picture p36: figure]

It has a rubber gasket that should go on top of the acrylic, with a ring to secure it. It’s orientation can be determined by the shape of the hole in the PCBs. These joysticks often arrive from the manufacturer with poor calibration, so it is recommended to test the resistance of the stick at rest and its min/max in each axis before soldering.

The Throttle Lever is an STL file included in the USC repository. It includes a friction mechanism that snaps onto the bottom of the PCB. Both parts require more consideration than other components and will be covered in a later section. Their assembly occurs during or after soldering.

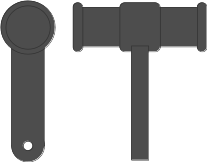
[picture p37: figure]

PCB Soldering

The PCBs for each module are filled with documentation which should be carefully read and considered before working. Every PCB in the project is single-sided, with the components and wires both being mounted on the side with documentation.


There are many resistors on each board, and over half of them are 10k Ohms. Resistors that aren’t 10k Ohms are denoted with a dotted border. Some holes, particularly those near buttons or switches, have dotted lines pointing toward a component. These are to indicate the component they are a part of as well as where the component’s pins should be for it to be in the proper orientation. The wire should go from its hole to the pin nearest to the dotted line.


Some holes are marked with a + or – symbol. These are used for LEDs or electrolytic capacitors that have a strict polarity. Some components also have + and – symbols on them. These should match the symbols on the PCB (+ to +). LEDs and electrolytic capacitors. have longer or shorter legs to indicate + or – respectively.

Typically all PCB components such as resistors, capacitors, and chip sockets should be soldered and cleaned first, with the user interface components like buttons, switches, and LEDs added later.

The wires need to be cut and added to the PCB before they are connected to the user interface components. One way is to use a helping hands device to hold both the PCB and a wire and to solder it in through the bottom.


For LEDs to connect to the PCB, they often need to be bent in a U shape so their legs curve into the holes. Be sure not to let the legs touch each other. Below is an example.


This is the typical flow for most modules. Special cases will be discussed below.

Throttle Module

Soldering the Throttle Module is more complex than most other modules and requires a very careful review of the sequence. At each point, think about how you are going to do the next several steps to ensure your plan makes sense.

Since the throttle lever needs to stick onto the end of the potentiometer, and the lever needs to fit through the holes of both the PCB and the acrylic, then this potentiometer cannot be soldered until later. Typically the sequence goes:

1. Solder all regular PCB components.

2. Solder all wires onto the PCB.

3. Stick all the buttons and switch onto the acrylic.

4. Feed the lever through the acrylic and PCB.

5. Fasten the lever onto the potentiometer.

6. Solder the potentiometer to the PCB.

7. Secure the PCB to the acrylic and solder the remaining wires to the components.

Extra care must also be taken to ensure the notch in the potentiometer is perpendicular to the shaft of the lever. This should be matched as closely as possible, though minor errors will be handled via calibration.

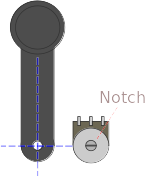
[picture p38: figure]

If printing with the unmodified STL files in the repository, the side facing the print bed should be the side that faces the potentiometer. This is because the opposite side is recessed a bit in order to fit the Throttle Guard.

The Throttle Guard is the name of the friction device that keeps the lever stationary when not actively being moved by the user. It fits into holes in the PCB and touches the lever underneath the module.

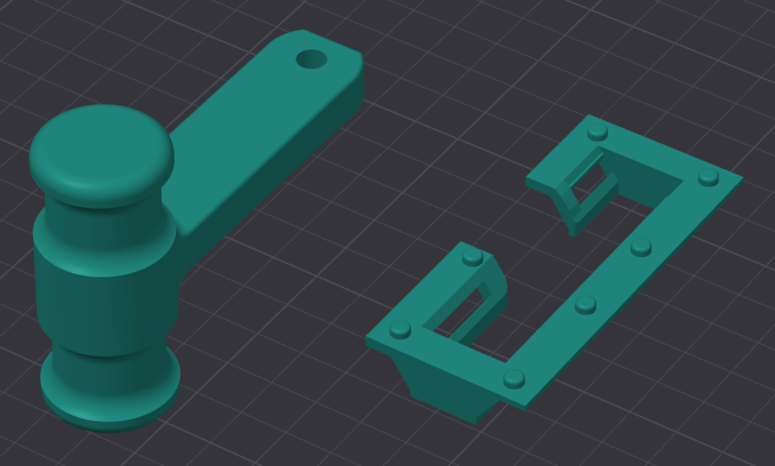
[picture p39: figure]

It is recommended to print several Throttle Guards and to treat each of them with different thickness of some other material wound around the contact bar (such as a thick tape like gaff tape). The number of winds of tape will alter the friction and compression of the lever. Too little, and the lever may move under gravity or inertia; too much and the Throttle Guard may plastically deform over time.

Once the fit is determined, the Throttle Guard should fit firmly into the PCB, but super glue can be used for added strength.


Calibration involves running the Throttle test script and reading the values in the Arduino Serial Monitor. First check the values of the throttle lever all the way down and all the way up, with the Mode switch in the ENBL (Enable) position. These values are the MIN and MAX. Then do the same with the Mode switch in PCSN (Precision). These are PMIN and PMAX.

It is recommended to write these values on the PCB in the designated areas. Then these calues can be patched into the Settings.h file in the firmware prior to upload.

Telemetry Module

The Telemetry Module is the only module that uses an Arduino Nano rather than an ATTiny chip. This Arduino should be soldered directly to the PCB with the USB port aiming away from the center towards the edge.

The screen itself needs to be carefully added, with washers and nuts used for spacing. The sequence goes:

1. Solder all regular PCB components.

2. Solder all wires onto the PCB.

3. Stick all the buttons onto the acrylic.

4. Feed the 4 long 3M screws through the PCB.

5. Add two thin 3M washers and a 3M nut to each screw for spacing.

6. Add the screen onto the screws.

7. Use two more 3M nuts onto each screw.

8. Push the PCB onto the screws and all the way down onto the pins for the screen.

9. Add the final nut to each screw and secure it tightly.

8. Solder the screen pins and button wires.

The final sequence should go:

[Nut] [PCB] [Nut] [Nut] [Screen PCB] [Nut] [Washer] [Washer] [Acrylic] [Screw Head]

If your washers are thicker, then you may only need one.


Joysticks

Each joystick has 6 pins sticking out the sides (from the potentiometers) and should be fairly straightforward to wire up, as they just connect to the PCB with jumpers from Axis 1 and Axis 2.

There are also 5 wires sticking out the side of the joystick: red, black, white, and two yellow. These go in the remaining empty holes next to the joystick labeled "Button" and "Axis 3". These holes are also labeled with letters that match the name of the color of the correct wire. R for red, B for black, and so on. I typically do this step after soldering the other wires to the PCB but before securing the PCB to the acrylic.


EVA Module

The EVA module is, for the most part, the same as the standard modules. The only difference is the 10 LED array for displaying EVA propellant. This array is organized with all of the anodes of the LEDs on one side (the side with the serial number sticker) and the cathodes on the other.

The array should be soldered to the PCB after the PCB and acrylic have already been joined, and it is nearly the final step of building the module. Soldering it first might prevent it from fitting into the hole in the acrylic later. The resulting array should stick up out of the acrylic slightly.

Adding the IC Chips

The ICs come in four different varieties. 74HC165, 74HC595, ATtinyX5, and ATtinyX4. It is recommended to use sockets for all your ICs to greatly reduce the time cost of fixing a module in event of a failure

The ATtinyX5 and ATtinyX4 chips are microcontrollers and need to be programmed. You can do this on a breadboard with directions for a simple ISP programmer circuit with this guide (https://www.circuits-diy.com/how-to-program-attiny85-with-arduino-uno/).

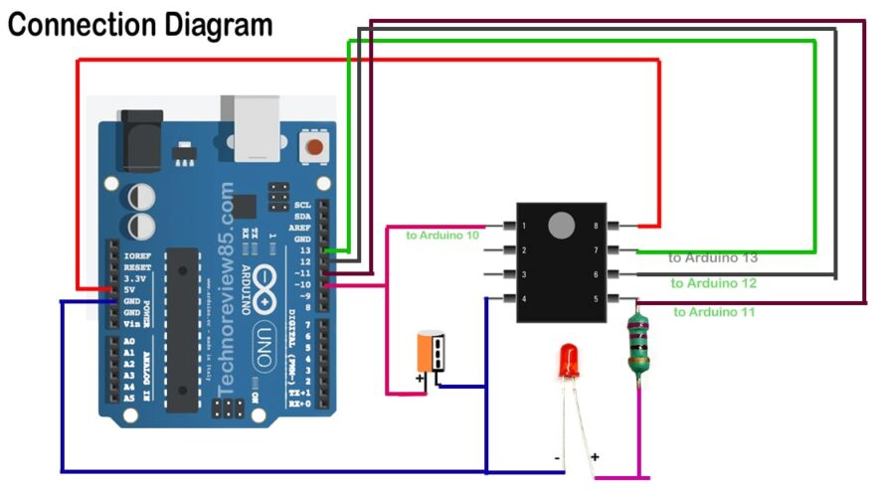
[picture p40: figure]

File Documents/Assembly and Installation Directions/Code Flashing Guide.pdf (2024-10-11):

# Untitled Space Craft

## Code Flashing Guide

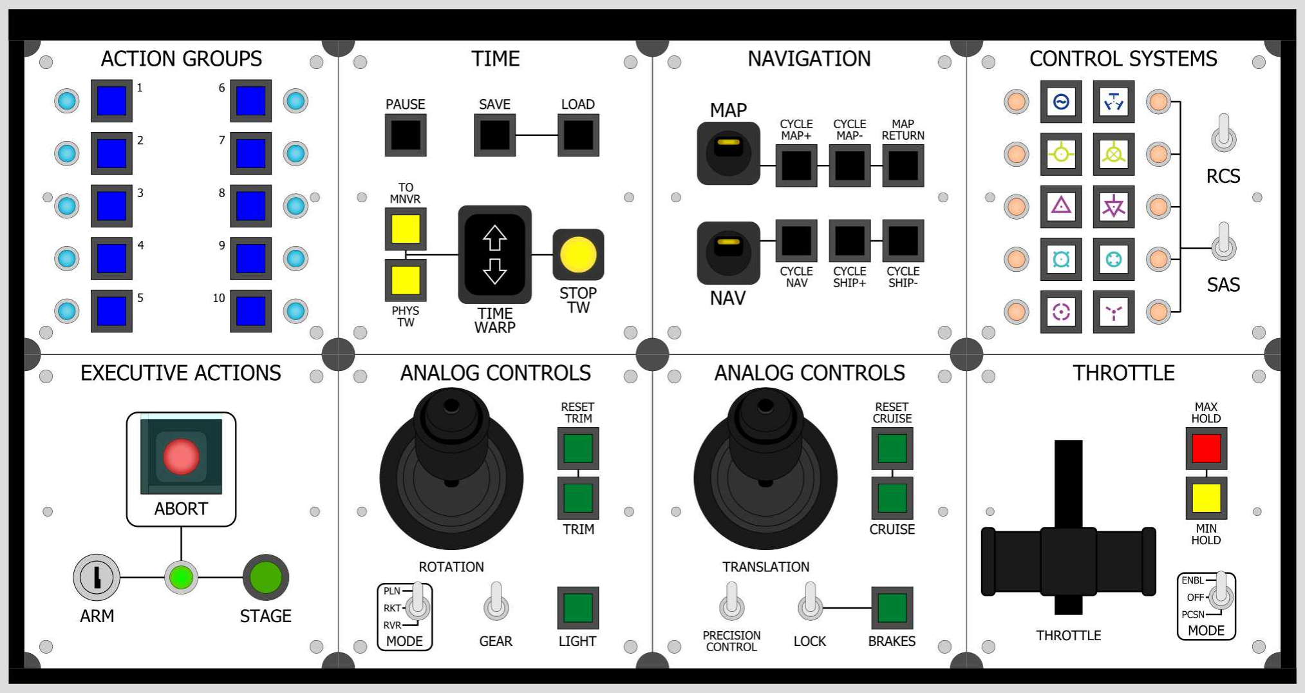
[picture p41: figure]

1. Download and install the Arduino IDE. https://www.arduino.cc/en/software

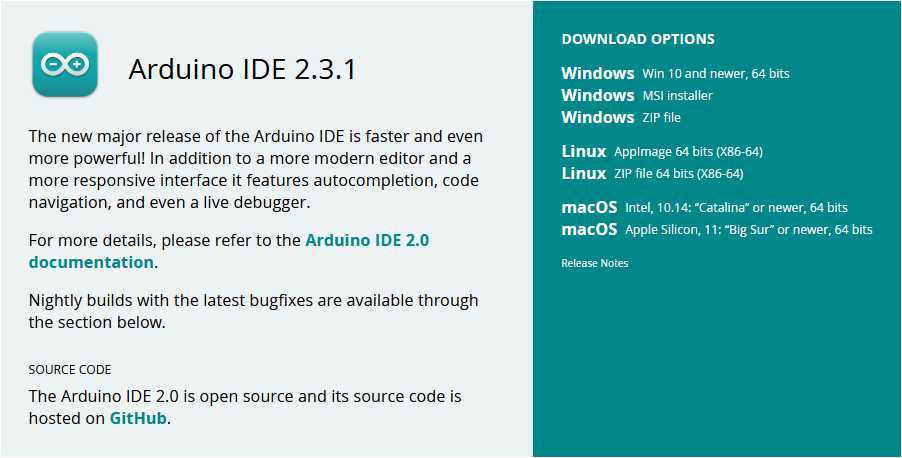
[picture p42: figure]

2. Download the latest version of the USC hub software. https://drive.google.com/drive/folders/1We1jZiN67R4KNCPk3y_iGojDVWFFW5ga?usp=sharing (https://drive.google.com/drive/folders/1We1jZiN67R4KNCPk3y_iGojDVWFFW5ga?usp=sharing)
3. Extract the folder and then open the file inside that has the same name as the folder. It should open into the Arduino IDE. Yours may look slightly different due to theme or version differences.

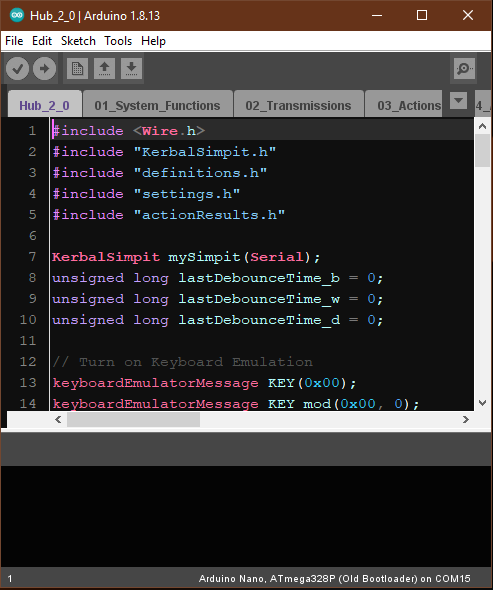
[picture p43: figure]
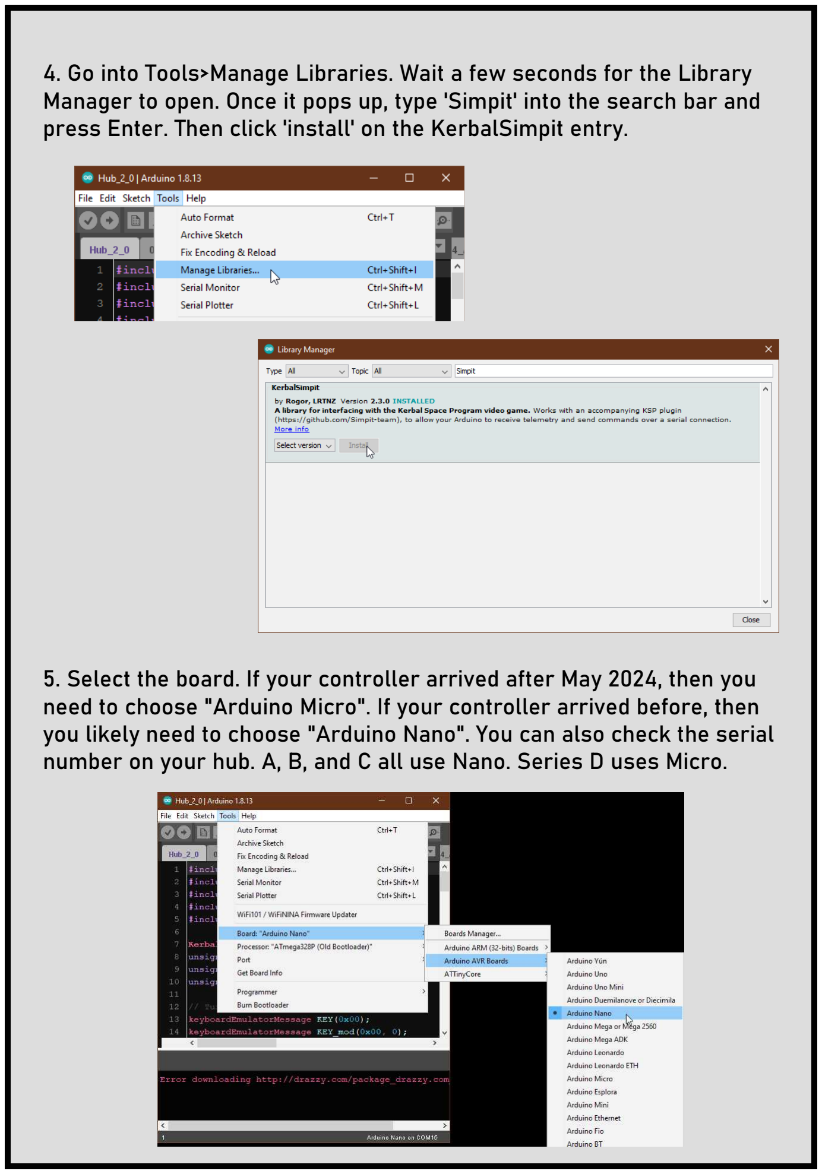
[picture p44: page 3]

4. Go into Tools>Manage Libraries. Wait a few seconds for the Library Manager to open. Once it pops up, type 'Simpit' into the search bar and press Enter. Then click 'install' on the KerbalSimpit entry.
5. Select the board. If your controller arrived after May 2024, then you need to choose "Arduino Micro". If your controller arrived before, then you likely need to choose "Arduino Nano". You can also check the serial number on your hub. A, B, and C all use Nano. Series D uses Micro.

6. Select the Port. This should be the same COM port that you chose for the installation guide, though please keep in mind that it may have changed.

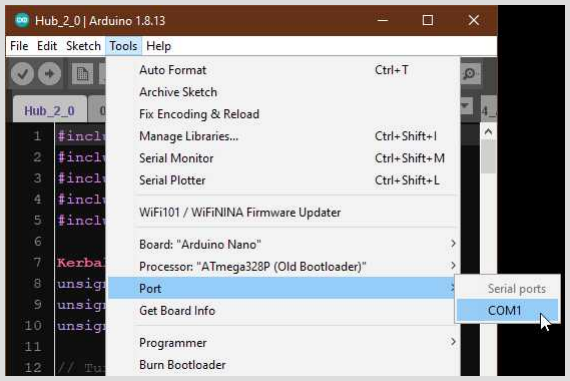
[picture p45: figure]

7. Plug the controller in to USB (power is unnecessary). Click the 'Upload' arrow to flash the code. Make sure you click the arrow and not the check mark.

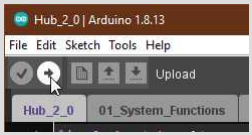
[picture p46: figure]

8. On some nanos, Step 7 will fail due to the bootloader. You can change the bootloader to the other option. The only two options you should use are "ATmega328P" and "ATmega328P (Old Bootloader)". Then click the arrow again.

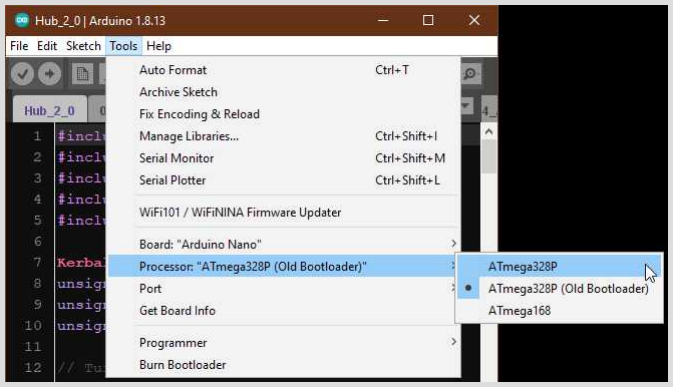
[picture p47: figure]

9. If the IDE says "Done" near the bottom or otherwise confirms that the code has loaded, then you should be all set!

There are some further settings options that you can change to suit your needs by editing the settings.h file. This is especially useful if your controller has a Throttle module.

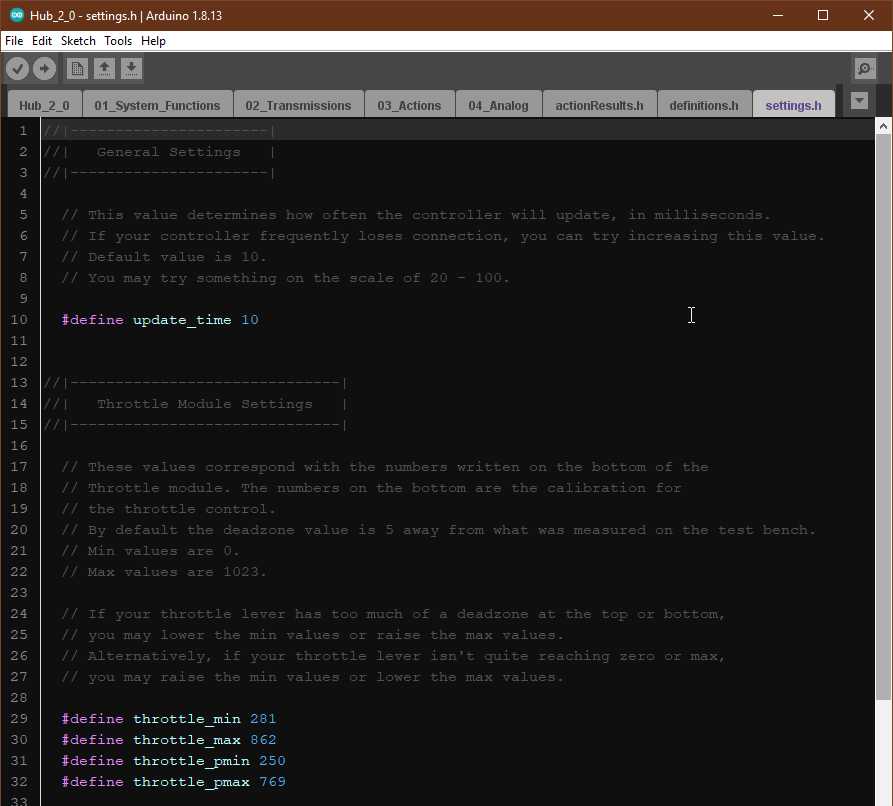
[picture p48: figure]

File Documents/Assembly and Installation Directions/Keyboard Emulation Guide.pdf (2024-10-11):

# Untitled Space Craft

## Keyboard Emulation Guide


Keyboard Emulation Mode is a new Beta feature of USC controllers. It allows for the use of the controllers in other games via keyboard emulation. Using this mode means that the LEDs and displays in your controller will not work. It merely turns the controller into a mappable keyboard.

By contrast, KSP Mode interfaces directly with the game. You may return to KSP mode at any time to return functionality of the displays. Tip: in KSP mode, you can unmap the keybinds for many of the keys in KSP to prevent accidentally hitting them on your keyboard.

Keyboard Emulation Mode is only available for controllers that contain an Arduino Micro. If your controller arrived after May 2024, then your controller is likely powered with a Micro. You can check the serial number on your container hub to confirm. Series A and B cannot use Arduino Micro. Series C originally shipped with a Nano but can be upgraded with a Micro. Series D shipped with a Micro installed.

1. The bulk of this process involves flashing new firmware to the controller. You can find the Code Flashing Guide here: https://drive.google.com/file/d/15OfTt_4WFQkeoATV0mpcZLOvZM7TydNE/view?usp=sharing (https://drive.google.com/file/d/15OfTt_4WFQkeoATV0mpcZLOvZM7TydNE/view?usp=sharing)

The mode of your controller is dependent on which firmware is currently flashed to the board. Firmware titled "Hub_KSP_X_X" are for KSP Mode, while "Hub_Emulation_X_X" is for Emulation mode.

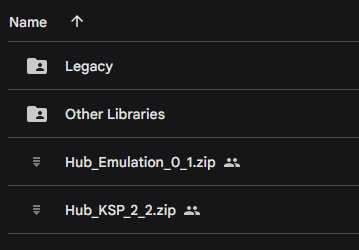
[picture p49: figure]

2. For KSP Mode, it should be ready to play after flashing. For Emulation Mode, you will need to map the buttons to your game or playstyle. This can be done in the file located in the Emulation code titled settings.h. Scroll down to find the section titled "Emulation Settings".

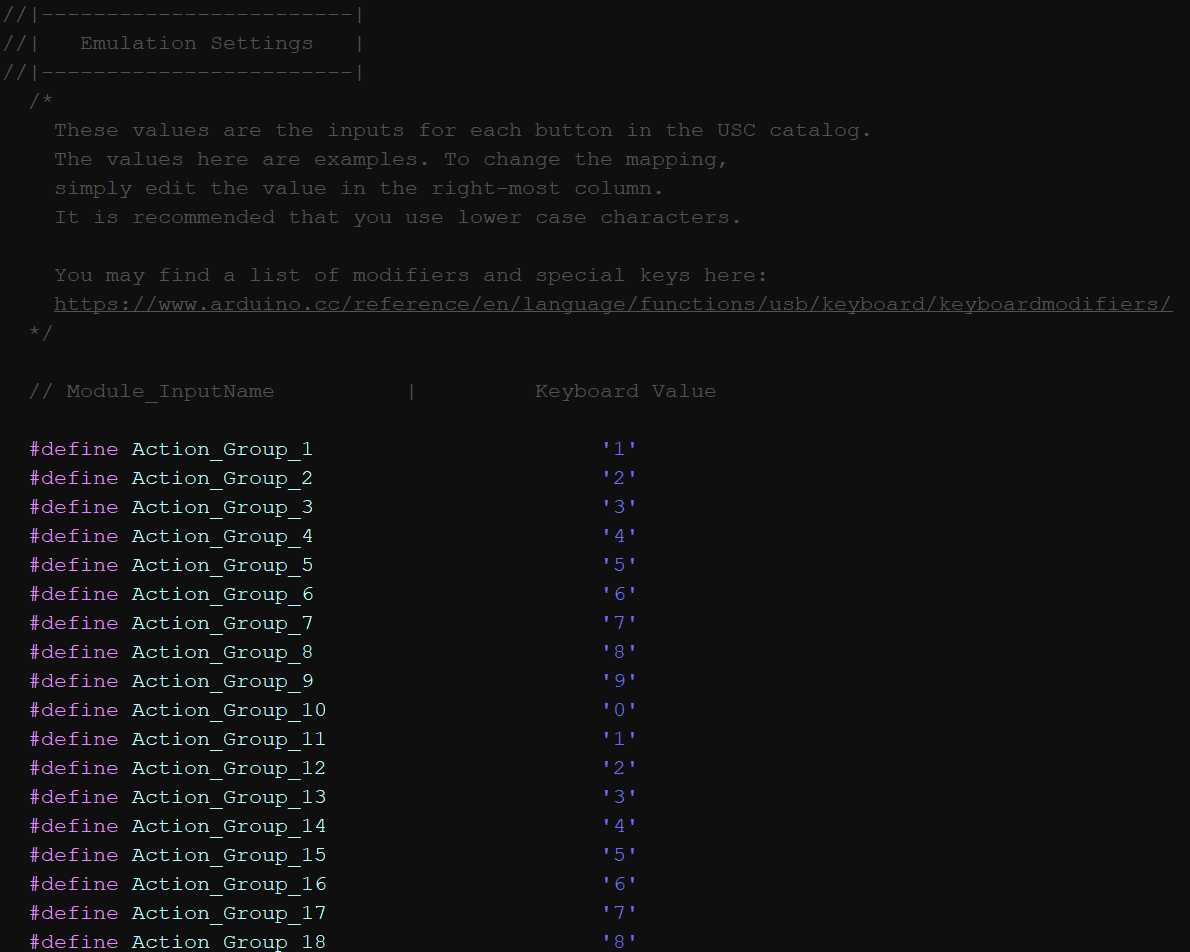
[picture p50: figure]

In this section, you can locate all of the inputs available on the controllers. This includes modules that you might not have, which can be ignored.

Locate the section of a module that you wish to edit, and change the Keyboard Value to the desired input. You can accomplish this by putting the value in single quotes. For example, if you want the 1 button on the Action Groups module to input the letter x, you can change the '1' next to "#define Action_Group_1" into a 'x'. It is recommended that you use lower case letters. Other keys, such as Shift and Ctrl can be found at https://www.arduino.cc/reference/en/language/functions/usb/keyboard/keyboardmodifiers/ (https://www.arduino.cc/reference/en/language/functions/usb/keyboard/keyboardmodifiers/)

When you are done you may upload the code!

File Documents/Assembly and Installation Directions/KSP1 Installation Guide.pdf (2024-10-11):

# Untitled Space Craft

## KSP1 Installation Guide


1. Download the latest version of Simpit. https://github.com/Simpit-team/KerbalSimpitRevamped/releases

Click the zip file and extract it. Add the contents to your KSP GameData folder.

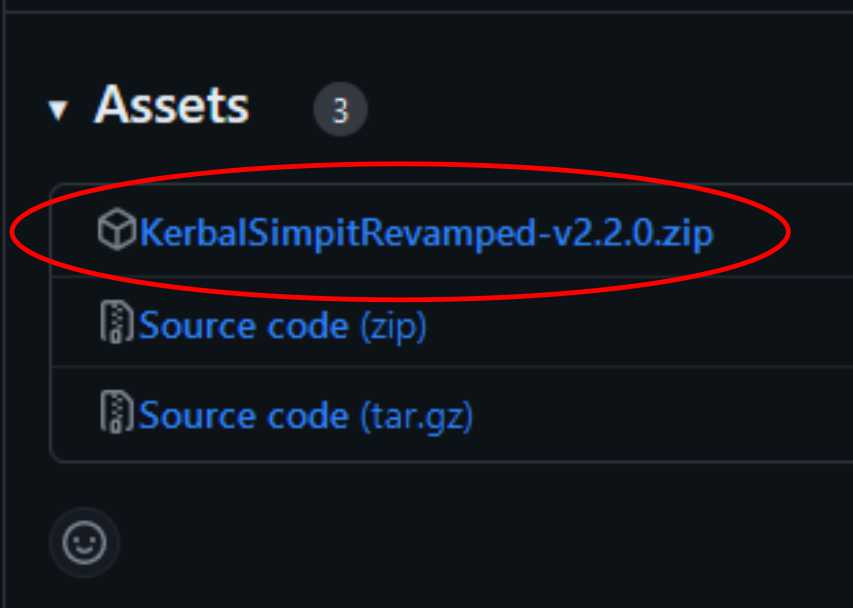
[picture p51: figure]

2. Locate the COM port that the controller connects to. For Windows 10 and 11, you may use the Start menu to search for "Device Manager". In the Device Manager, click "View" and select "Show Hidden Devices." Then locate "Ports (COM & LPT)" and make note of the listed ports. Plug in the controller to USB and note the new port that appears in the list.

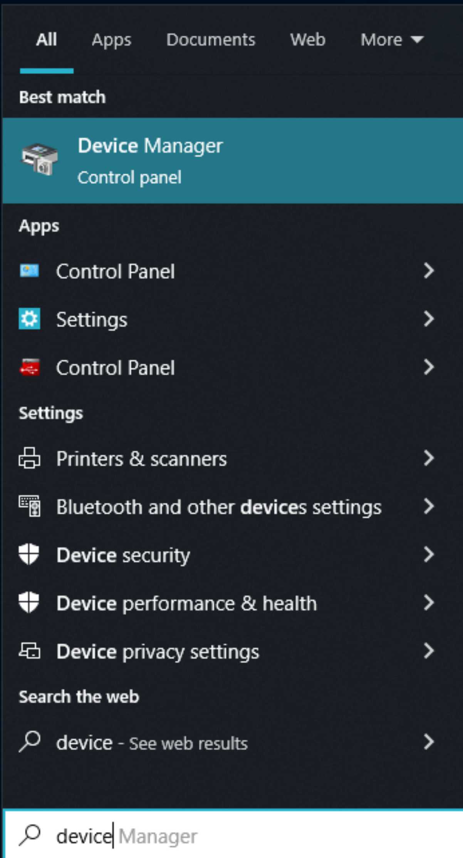
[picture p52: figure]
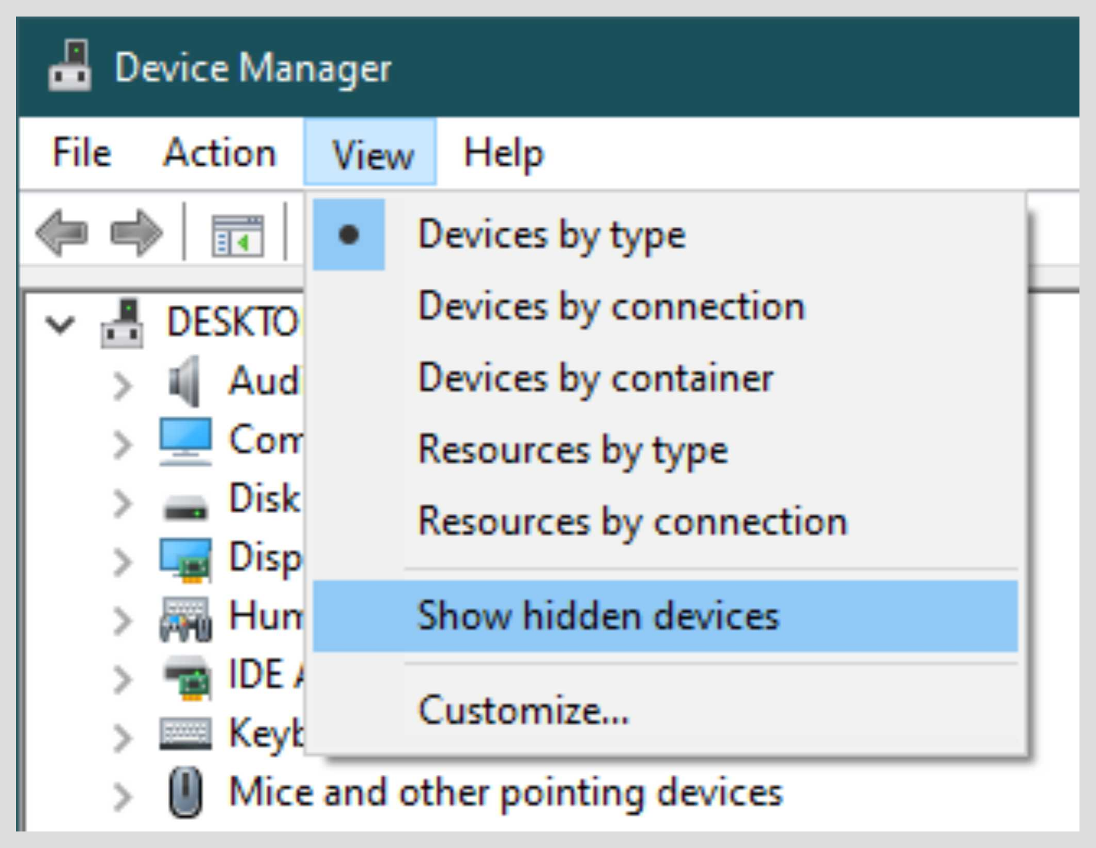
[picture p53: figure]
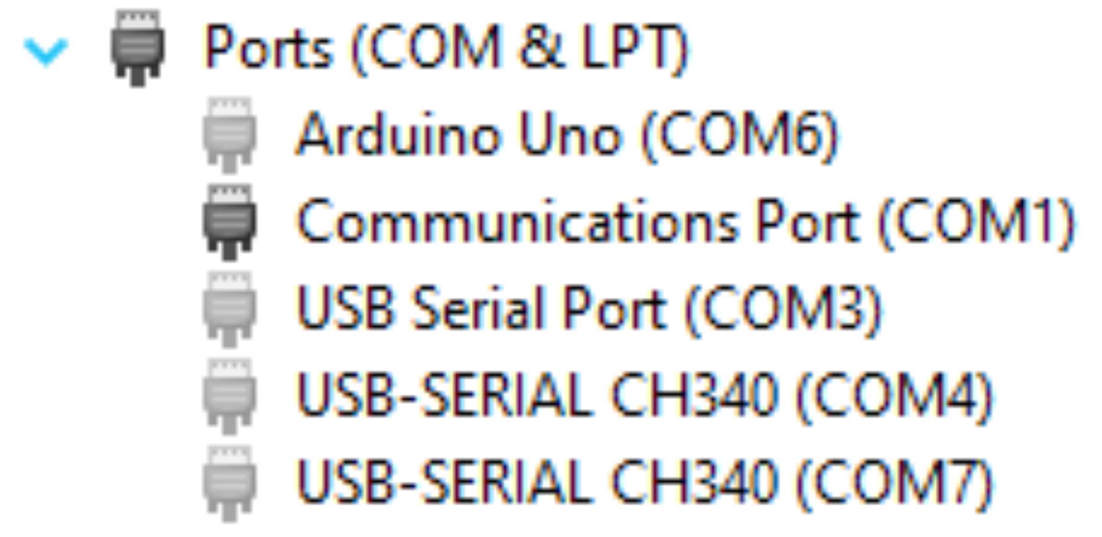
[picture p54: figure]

3. Add the COM port to the settings.cfg file in the Simpit mod folder. Make sure you are editing settings.cfg and not settings.cfg.sample. Add the controller's port name to "PortName = " as shown. You can leave the other settings as-is. Verbose is for logging and should be False for gameplay. Save the file and exit.

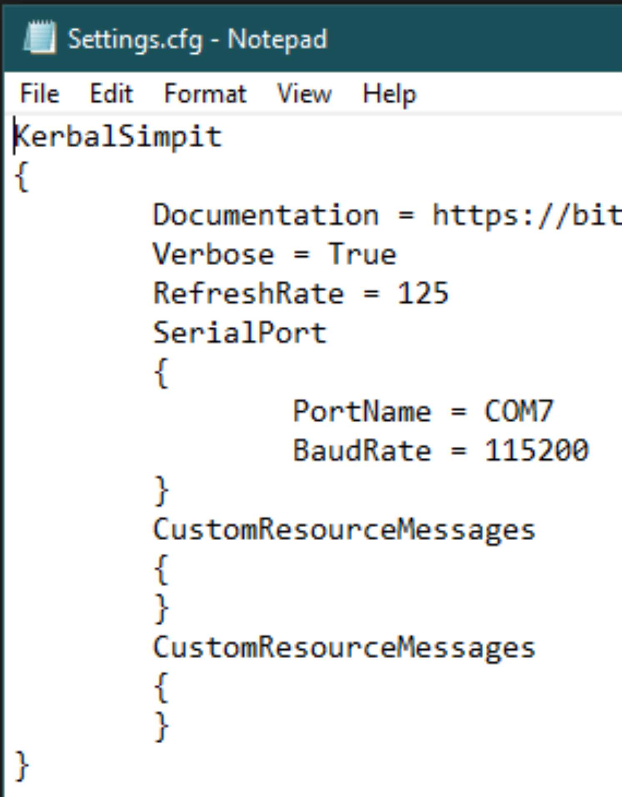
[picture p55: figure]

4. Boot up KSP and connect the controller. When you connect the controller, it is a good idea to always connect the USB first and the power second. Navigate to the mod sidebar and locate the Simpit icon, shown here in green. If yours is not green, then you may click "Close" and "Start". If everything was done properly it should be ready to play!

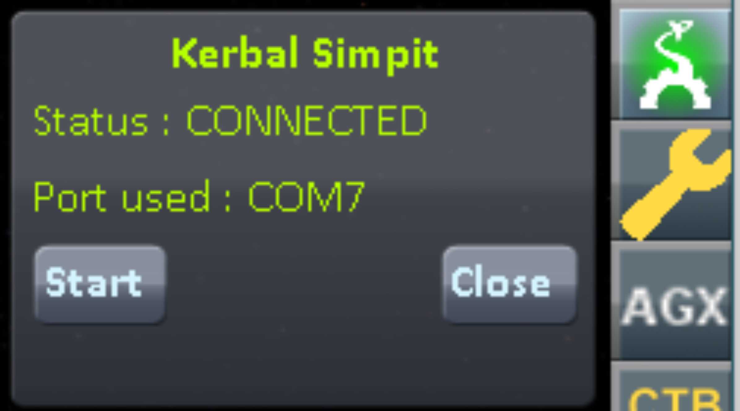
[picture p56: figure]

5. If you have multiple containers or hubs, you may add them into your settings.cfg by copying SerialPort and the following 4 lines, as shown in the image.

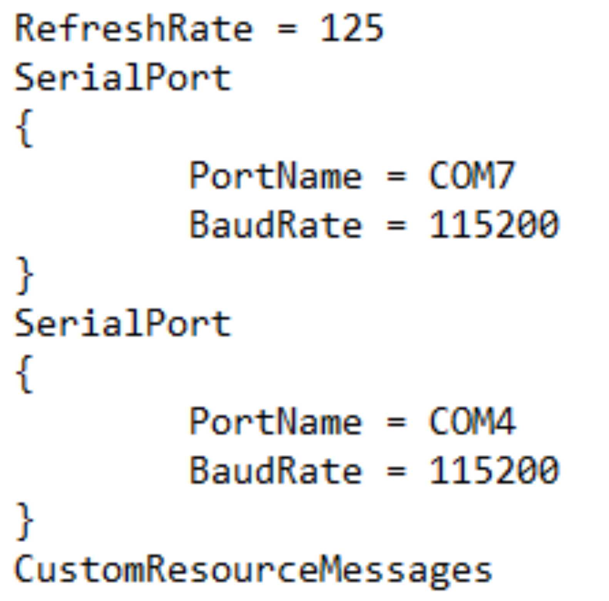
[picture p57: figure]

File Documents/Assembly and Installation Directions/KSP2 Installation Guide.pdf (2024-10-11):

# Untitled Space Craft

## KSP2 Installation Guide

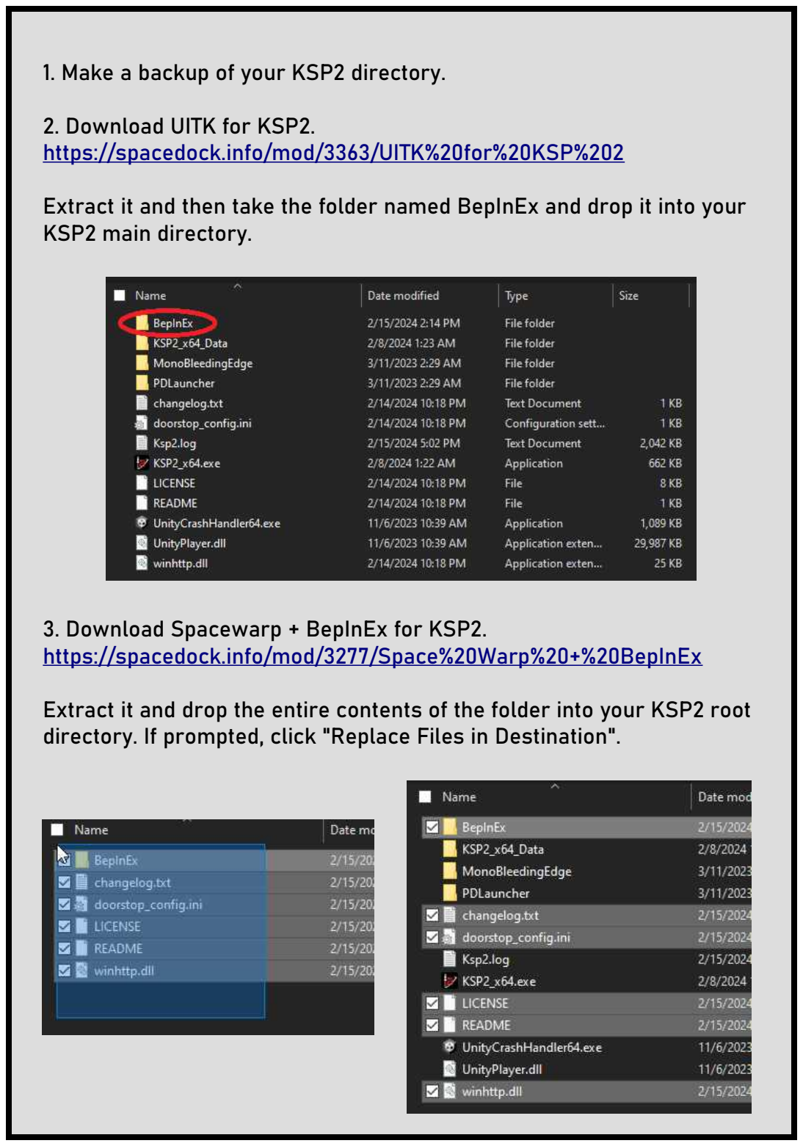
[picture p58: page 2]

1. Make a backup of your KSP2 directory.
2. Download UITK for KSP2. https://spacedock.info/mod/3363/UITK%20for%20KSP%202

Extract it and then take the folder named BepInEx and drop it into your KSP2 main directory.

3. Download Spacewarp + BepInEx for KSP2. https://spacedock.info/mod/3277/Space%20Warp%20+%20BepInEx

Extract it and drop the entire contents of the folder into your KSP2 root directory. If prompted, click "Replace Files in Destination".

4. Download the latest version of Kerbal Simpit for KSP2. https://github.com/Simpit-team/KerbalSimpit-KSP2/tree/develop/release Download the most recent .zip file and extract it. Take the Simpit folder from inside that extracted folder and drop it into ./BepInEx/plugins.

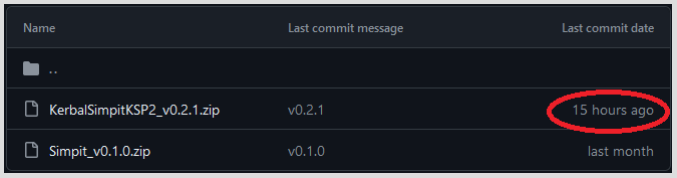
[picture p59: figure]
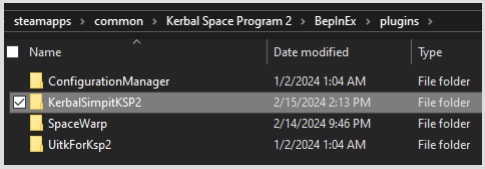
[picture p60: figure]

5. Locate the COM port that the controller connects to. For Windows 10 and 11, you may use the Start menu to search for "Device Manager". In the Device Manager, click "View" and select "Show Hidden Devices." Then locate "Ports (COM & LPT)" and make note of the listed ports. Plug in the controller to USB and note the new port that appears in the list.

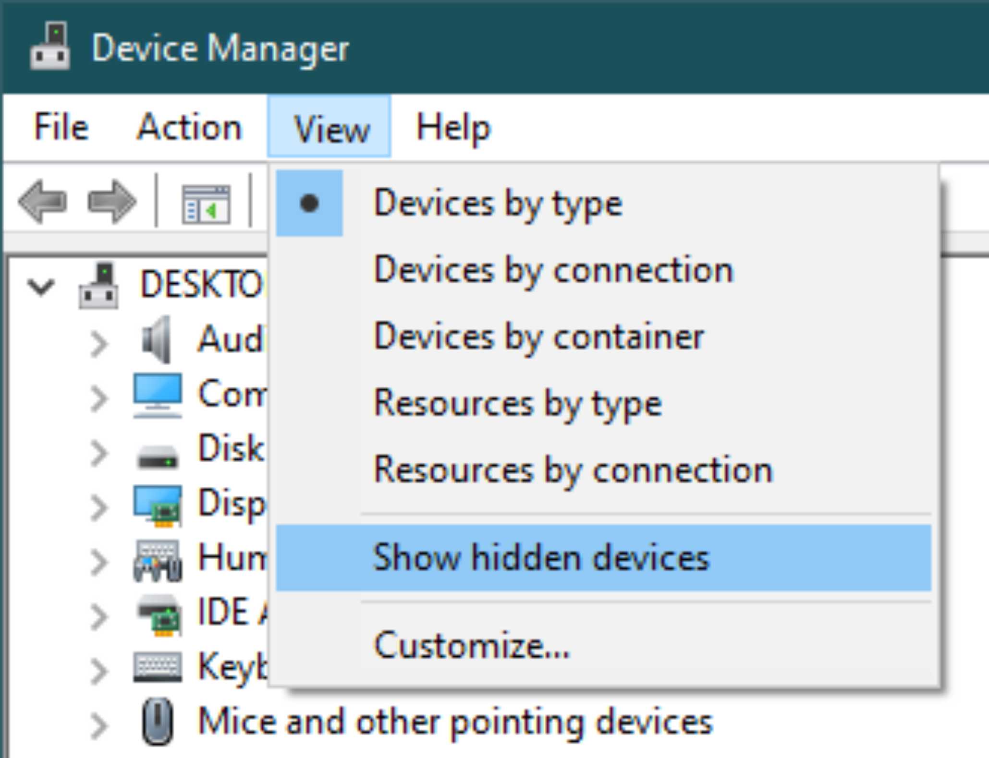
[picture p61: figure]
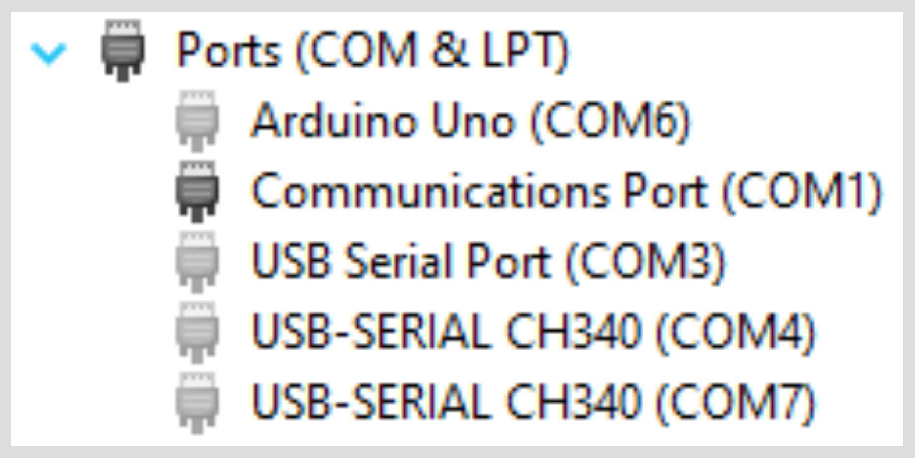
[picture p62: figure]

6. Boot up KSP2 and go into the settings menu. Click "Mods" on the left and scroll down to Simpit. In this menu you can input your COM port, such as COM15 in the image. You can also specify the number of serial ports here if you are running more than one container/hub.

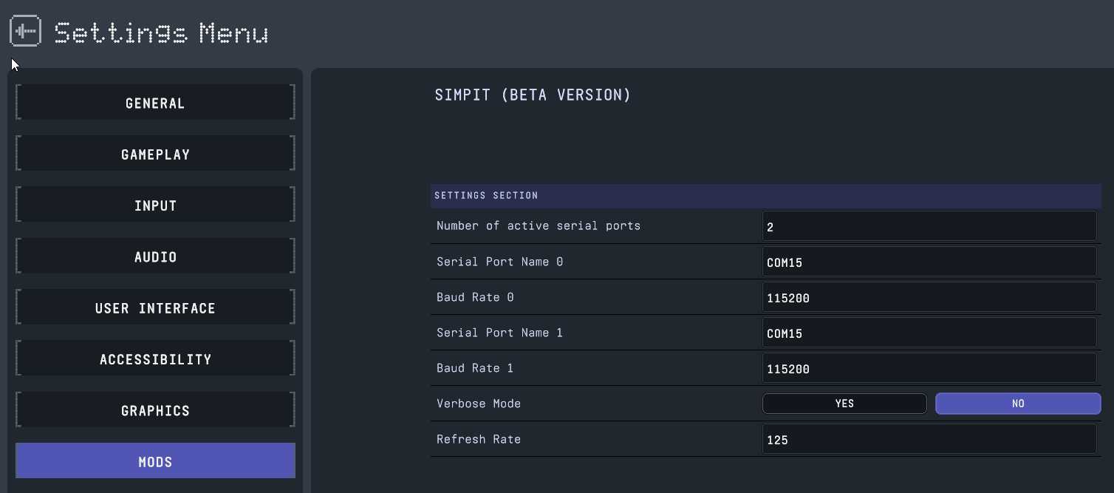
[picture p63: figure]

7. Plug in your controller (USB first, then power) and enter a saved game. Click the 3x3 dot grid button near the bottom right and select Simpit. After clicking "Open Ports" your controller should connect and you should be all set to play! If you have connection issues, you may just need to close it, unplug the power cable, plug it in again, and open the port once more.

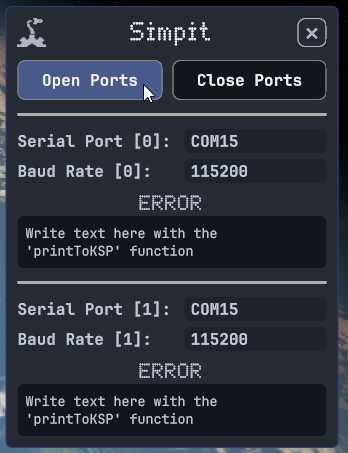
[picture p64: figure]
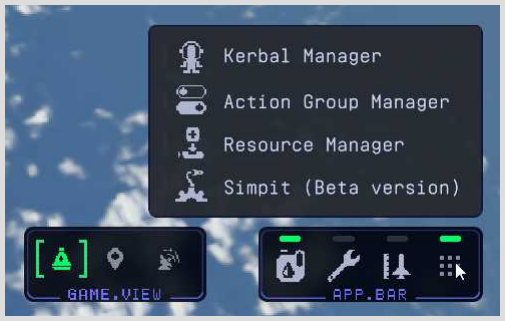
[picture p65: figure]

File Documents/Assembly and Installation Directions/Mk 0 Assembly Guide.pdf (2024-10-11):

# Untitled Space Craft

## Mk 0 Container Assembly Guide

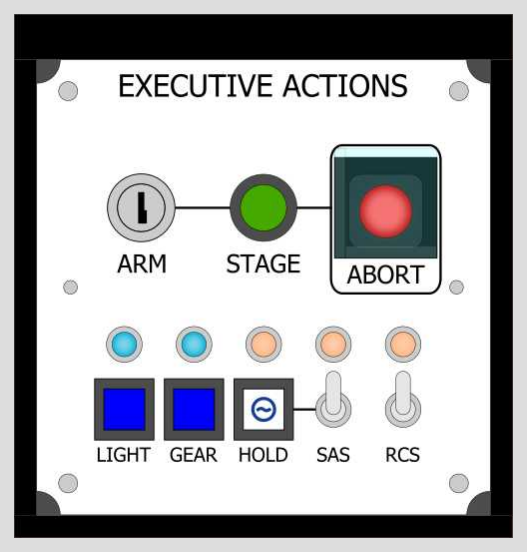
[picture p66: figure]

1. Make sure you have all the pieces. The hub piece may already have the hub PCB and arduino attached. Take extra care with the two module support pieces, as they are somewhat fragile. In most cases, broken pieces can be repaired with super glue without sacrificing any structural integrity. However, super glue will damage the mirror finish. For assembly, it is recommended that you use silicone caulk, like the kind for sealing cracks in walls, in clear or the same color of your container. It is also recommended that you first construct the container once without adhesive. With caulk, you have about 30 minutes before it starts to dry.

2. Place the biggest piece on the build surface. This is the base of the container. Make sure it is oriented in the correct direction so that the holes, circled in red, are towards the back.

3. Place the tiny hub support piece, yellow, into the slot in the base. Add the hub, blue, on top of it, with the PCB and arduino attached.

4. Add the left and right side pieces, blue.
5. Fit the U-shaped module support piece, yellow, into the holes. Make sure the magnets are oriented silver side up.

6. Add the back piece, blue, to the rear of the container. Take care to orient the holes as shown in the picture. Fit the hub piece, rear power connector, and USB port into these holes.
7. Fit the top bar, yellow, into the top of the back piece.
8. Fit the small module support piece, blue, into the front piece, yellow, and fit it to the front of the container.

9. Routinely compress everything together until dry. After a few hours, you may scrape off the excess adhesive.
10. Plug the module in using the standard Data Bus Connection cable. You may plug any module in to any port, including new modules purchased later.
11. To remove a module later, you may use a screw driver or, ideally, a plastic piece to wedge the module up from the corner. Then you can fit a finger underneath. Be careful not to scratch the surface or bend any wires underneath.

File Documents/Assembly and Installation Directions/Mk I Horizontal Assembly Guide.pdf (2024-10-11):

# Untitled Space Craft

## Mk I Horizontal Container Assembly Guide

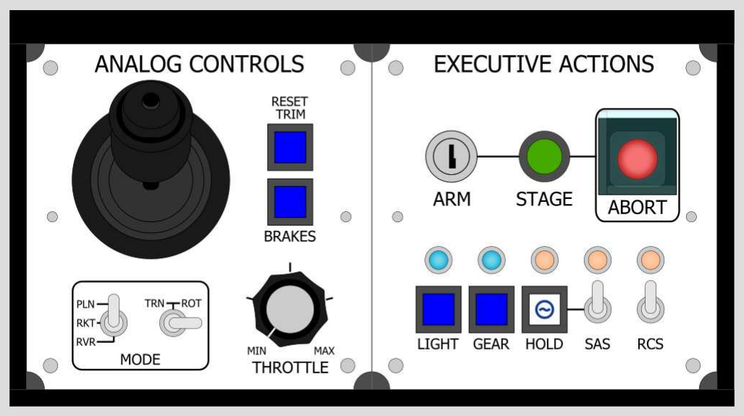
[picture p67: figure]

1. Make sure you have all the pieces. The hub piece may already have the hub PCB and arduino attached. Take extra care with the two module support pieces, as they are somewhat fragile. In most cases, broken pieces can be repaired with super glue without sacrificing any structural integrity. However, super glue will damage the mirror finish. For assembly, it is recommended that you use silicone caulk, like the kind for sealing cracks in walls, in clear or the same color of your container. It is also recommended that you first construct the container once without adhesive. With caulk, you have about 30 minutes before it starts to dry.

2. Place the biggest piece on the build surface. This is the base of the container. Make sure it is oriented in the correct direction so that the holes, circled in red, are towards the back left.
3. Insert the angled center support, pictured in blue, into the base, with the taller side near the back.

4. Place the tiny hub support piece, yellow, into the slot in the base.
5. Add the larger module support piece, blue, onto the center support. The magnets must be oriented with the silver side up.

6. Add the hub piece, yellow, to the hub support piece, with the PCB and arduino attached.
7. Add the left and right side pieces, blue, and take care to fit the module support pieces into the holes.
8. Fit the smaller module support piece, yellow, to the front piece. Add the front piece to the front of the container.

9. Add the back piece, blue, to the rear of the container. Take care to orient the holes towards the left. Fit the hub piece, rear power connector, and USB port into these holes.
10. Fit the top bar, yellow, into the top of the back piece.
11. Routinely compress everything together until dry. After a few hours, you may scrape off the excess adhesive.

12. Plug all of the modules in using the standard Data Bus Connection cables. You may plug any module in to any port, including new modules purchased later. The cables come in various lengths which should be used according to how far away the module is from the hub.
13. To remove a module later, you may use a screw driver or, ideally, a plastic piece to wedge the module up from the corner. Then you can fit a finger underneath. Be careful not to scratch the surface or bend any wires underneath.

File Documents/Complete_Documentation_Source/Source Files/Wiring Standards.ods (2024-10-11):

 |  |  |  | ATtiny85 |  |  |  | 74HC165
 |  |  |  | I/O 5/Reset | 1 | 8 | 5V | AT I/O 4 | 1 | 16 | 5V
 |  |  |  | I/O 3 | 2 | 7 | I/O 2 / SCL | AT I/O 1 | 2 | 15 | GND
 |  |  |  | I/O 4 | 3 | 6 | I/O 1 | Q 4 | 3 | 14 | Q 3
 |  |  |  | GND | 4 | 5 | I/O 0 / SDA | Q 5 | 4 | 13 | Q 2
 |  |  |  |  |  |  |  | Q 6 | 5 | 12 | Q 1
 |  |  |  |  |  |  |  | Q 7 | 6 | 11 | Q 0
 |  |  |  | ATtiny85 – 74HC165 |  |  |  |  | 7 | 10 | From IC2
 |  |  |  | Reset | 1 | 8 | 5V | GND | 8 | 9 | AT I/O 3
 |  |  |  | SR Pin 9 | 2 | 7 | SCL
 |  |  |  | SR Pin 1 | 3 | 6 | SR Pin 2
Hub Connector – Notch on Pin 4/5 |  |  |  | GND | 4 | 5 | SDA | 74HC595
Analog 5 | 1 | 16 | SDA | shift.begin(4, 5, 3, 1); (load, enable, data, clock) |  |  |  | Q 1 | 1 | 16 | 5V
Analog 4 | 2 | 15 | SCL |  |  |  |  | Q 2 | 2 | 15 | Q 0
Analog 3 | 3 | 14 | Reset |  |  |  |  | Q 3 | 3 | 14 | AT I/O 3
Analog 2 | 4 | 13 | Digital 4 | ATtiny85 – 74HC595 |  |  |  | Q 4 | 4 | 13 | GND
Analog 1 | 5 | 12 | Digital 3 | Reset | 1 | 8 | 5V | Q 5 | 5 | 12 | AT I/O 4
Analog 0 | 6 | 11 | Digital 2 | SR Pin 14 | 2 | 7 | SCL | Q 6 | 6 | 11 | AT I/O 1
Digital 1 | 7 | 10 | 5V | SR Pin 12 | 3 | 6 | SR Pin 11 | Q 7 | 7 | 10 | 5V
Digital 0 | 8 | 9 | GND | GND | 4 | 5 | SDA | GND | 8 | 9 | From IC2
 |  |  |  | ShiftRegister74HC595<2> sr(3, 1, 4); (data, clock, latch)
Programmer Connector
I/O 0 | 1 | 4 |  | ATtiny84
I/O 1 | 2 | 5 | Reset | 5V | 1 | 14 | GND
I/O 2 | 3 |  |  | I/O 10 | 2 | 13 | AREF
 |  |  |  | I/O 9 | 3 | 12 | A1
 |  |  |  | Reset | 4 | 11 | A2
 |  |  |  | I/O 8 | 5 | 10 | A3
 |  |  |  | I/O 7 – A7 | 6 | 9 | SCL
 |  |  |  | SDA | 7 | 8 | I/O 5
 | Arduino | Attiny24 | Attiny85
 | Pin 10 | Reset (4) | 1
 | Pin 11 | MOSI (7) | 5
 | Pin 12 | MISO (8) | 6
 | Pin 13 | SCK (9) | 7

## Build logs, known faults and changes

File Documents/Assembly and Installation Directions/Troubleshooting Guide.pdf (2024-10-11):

# Untitled Space Craft

## Troubleshooting Guide


Hopefully problems never happen, and when they do they can be frustrating. I'm happy to help fix any issues you may have with your USC controller. However, before contacting me, please make sure you've read this guide and have followed the steps where applicable. If you are still having issues after that, you may contact me directly.

A. The controller won't connect to KSP.

This is a common issue that could have many causes. Please check each of the following, no matter how obvious. Please note that the COM port might change throughout the tests.

- Check that the COM port is correct.
- Ensure that the power is plugged in.
- Make sure the controller is plugged directly into a USB port.
- Try a different USB port, perhaps swapping between USB3 or USB2.
- Make sure the LED is lighting up on the controller hub.
- Restart KSP.
- Unplug and replug both the power and USB on the controller.

If all those checks have passed and the controller still isn't connecting, then the next step is to try loading code onto it.

Please refer to the Code Flashing Guide and follow the instructions through the end.
https://drive.google.com/file/d/15OfTt_4WFQkeoATV0mpcZLOvZM7TydNE/view?usp=sharing (https://drive.google.com/file/d/15OfTt_4WFQkeoATV0mpcZLOvZM7TydNE/view?usp=sharing)

If that doesn't work, then please refer to part B.

B. Replacing the Arduino Nano/Micro
1. If the code failed to load, then it's a good bet that your arduino is fried. As a last resort you may try installing the CH341SER drivers and trying again.

https://drive.google.com/file/d/1L65JlEDR6Qxue4uuhsguE-bgvJnPHBzL/view?usp=sharing (https://drive.google.com/file/d/1L65JlEDR6Qxue4uuhsguE-bgvJnPHBzL/view?usp=sharing)

2. Failing that, you will most likely require a new Arduino. Fortunately this is neither difficult nor expensive. You can acquire one from several online retailers such as Amazon or Alibaba for as low as a few dollars.

You should have already determined if you have a Nano or Micro when flashing the code, but if you aren't sure then you should confirm. The Serial Number on your hub should have a letter in it, series A, B, C, or
D. Series B can only have Nano. Series C originally came with a Nano but can use Micro if you'd like to upgrade. Series D originally came with a Micro but can use Nano if you want to save some money. Arduino Micro is able to connect as a keyboard emulator. Sadly, this functionality isn't available on the Nano.

There are many different suppliers, but as long as you choose 'Arduino Nano' or 'Arduino Micro' then it should work. Just make sure that the USB port is the type that you want or are already using and that the board comes pre-soldered, like this picture.

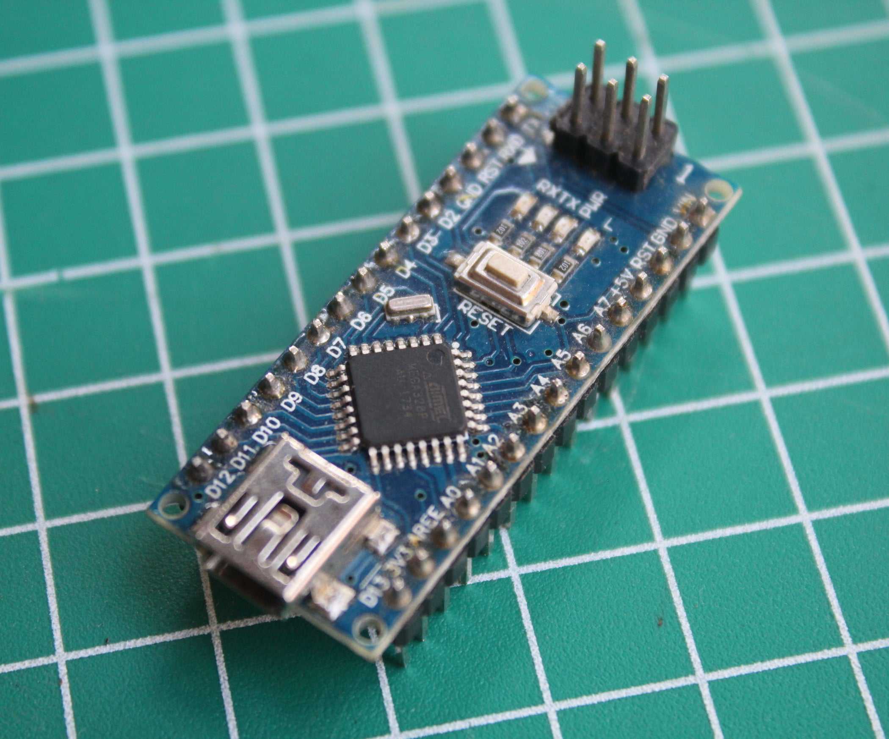
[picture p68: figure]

3. Once you have a fresh Arduino, you may follow the previous steps to load the hub code onto it. Once that is complete, you will need to extract your old Arduino from your hub.
4. If your hub is already glued into your container, you will need to remove it, which might require breaking the glue seal. You may also be able to unscrew it.
5. Once you have the hub in hand, very gently wedge the old Arduino up by sticking a pen under it. Wedge up one side a tiny bit and then move to the other side. Alternate sides and lift it up little by little until it is free.

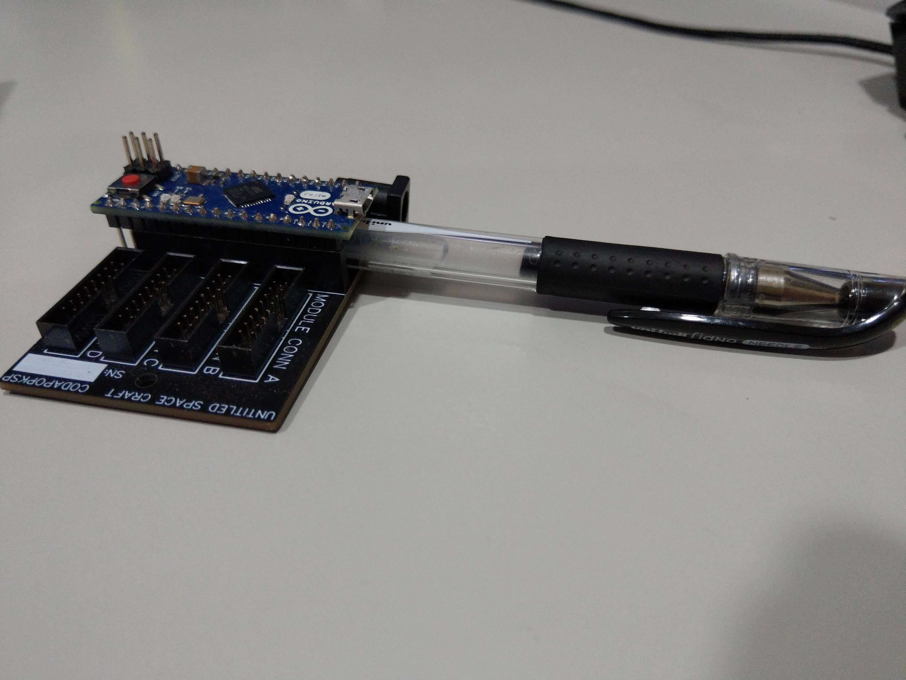
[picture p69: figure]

6. Once the old Arduino is out, you simply need to insert the new Arduino into the socket and press it down firmly. Make sure it is facing the right way! The USB port should be on the same side as the power jack.

At this point it is recommended that you try plugging in the modules and running the controller in the game to confirm it has been repaired before you glue it back together.

C. My analog sticks or throttle lever aren't working properly.

Analog sticks and the throttle lever are the only moving parts of the controller. They aren't descrete like computer code and thus need to be calibrated. This is typically already done for you, but sometimes they can shift over time or be pushed out of alignment during shipping.

Poorly-calibrated analog controls can manifest in a few different ways.

- The craft still has input in the direction of an analog stick even when you are not touching it, also called a center deadzone issue. (Be careful not to be fooled by SAS/Trim or other auto pilot mods.)
- The analog stick never reaches all the way in a given direction.
- The throttle still activates a little bit if even if the throttle is all the way down.
- The throttle never reaches 100% even when pushed all the way forward.

A lot of these problems can be solved by editing the deadzone calibration code in the settings.h file by following the Code Flashing Guide.
https://drive.google.com/file/d/15OfTt_4WFQkeoATV0mpcZLOvZM7TydNE/view?usp=sharing (https://drive.google.com/file/d/15OfTt_4WFQkeoATV0mpcZLOvZM7TydNE/view?usp=sharing)

The calibration values for the Throttle module are written on the PCB on the bottom of the module.

The analog sticks also have a physical calibration for two of the three axes which you can access underneath by loosening the screw next to the potentiometer and moving it around. It is not recommended that you try this without a multimeter and without at least a basic understanding of electronics.

If your analog stick or throttle is behaving erratically, then it's possible there is a deeper issue at play.

D. My controller connects but it disconnects frequently.

The controllers should be stable if set up properly, and I (Coda) can get many hours of play time out of mine without any issues. However, every system is different, and I can't claim to have tested them on every configuration. Currently, there are no known mods that conflict with the controllers, but it is something to keep in mind. It might be worth it to spin up a second build of KSP with only Simpit and its dependency mods to check for conflicts.

Controllers that consist of multiple containers (multiple USB cables) are known to have stability issues if connected using a USB hub. Thus, a solution here is to connect each container directly to a USB port.

An owner of a USC controller, Rettoph, has kindly created a more stable version of Simpit, which might allow for using USB hubs. At the moment it doesn't support Action Groups greater than 10. If you are having stability issues, then you can try downloading his build here: https://github.com/rettoph/KerbalSimpitRevamped/releases

However, you will need to use his Arduino library and reload the code to your hubs. You can find the arduino library packaged in the zip file, and you will need to install it manually. For Windows, typically it will need to be placed in Documents/Arduino/libraries. You will need to delete the KerbalSimpit folder there or else it may take priority. Then you will need to load the code by following the Code Flashing Guide: https://drive.google.com/file/d/15OfTt_4WFQkeoATV0mpcZLOvZM7TydNE/view?usp=sharing (https://drive.google.com/file/d/15OfTt_4WFQkeoATV0mpcZLOvZM7TydNE/view?usp=sharing)

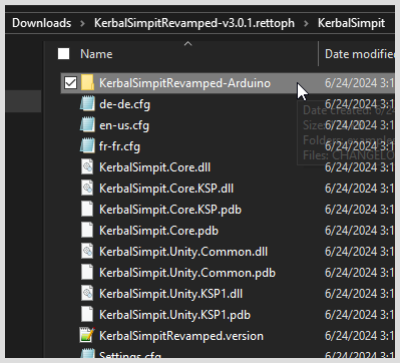
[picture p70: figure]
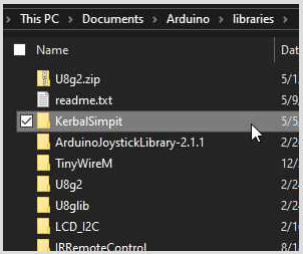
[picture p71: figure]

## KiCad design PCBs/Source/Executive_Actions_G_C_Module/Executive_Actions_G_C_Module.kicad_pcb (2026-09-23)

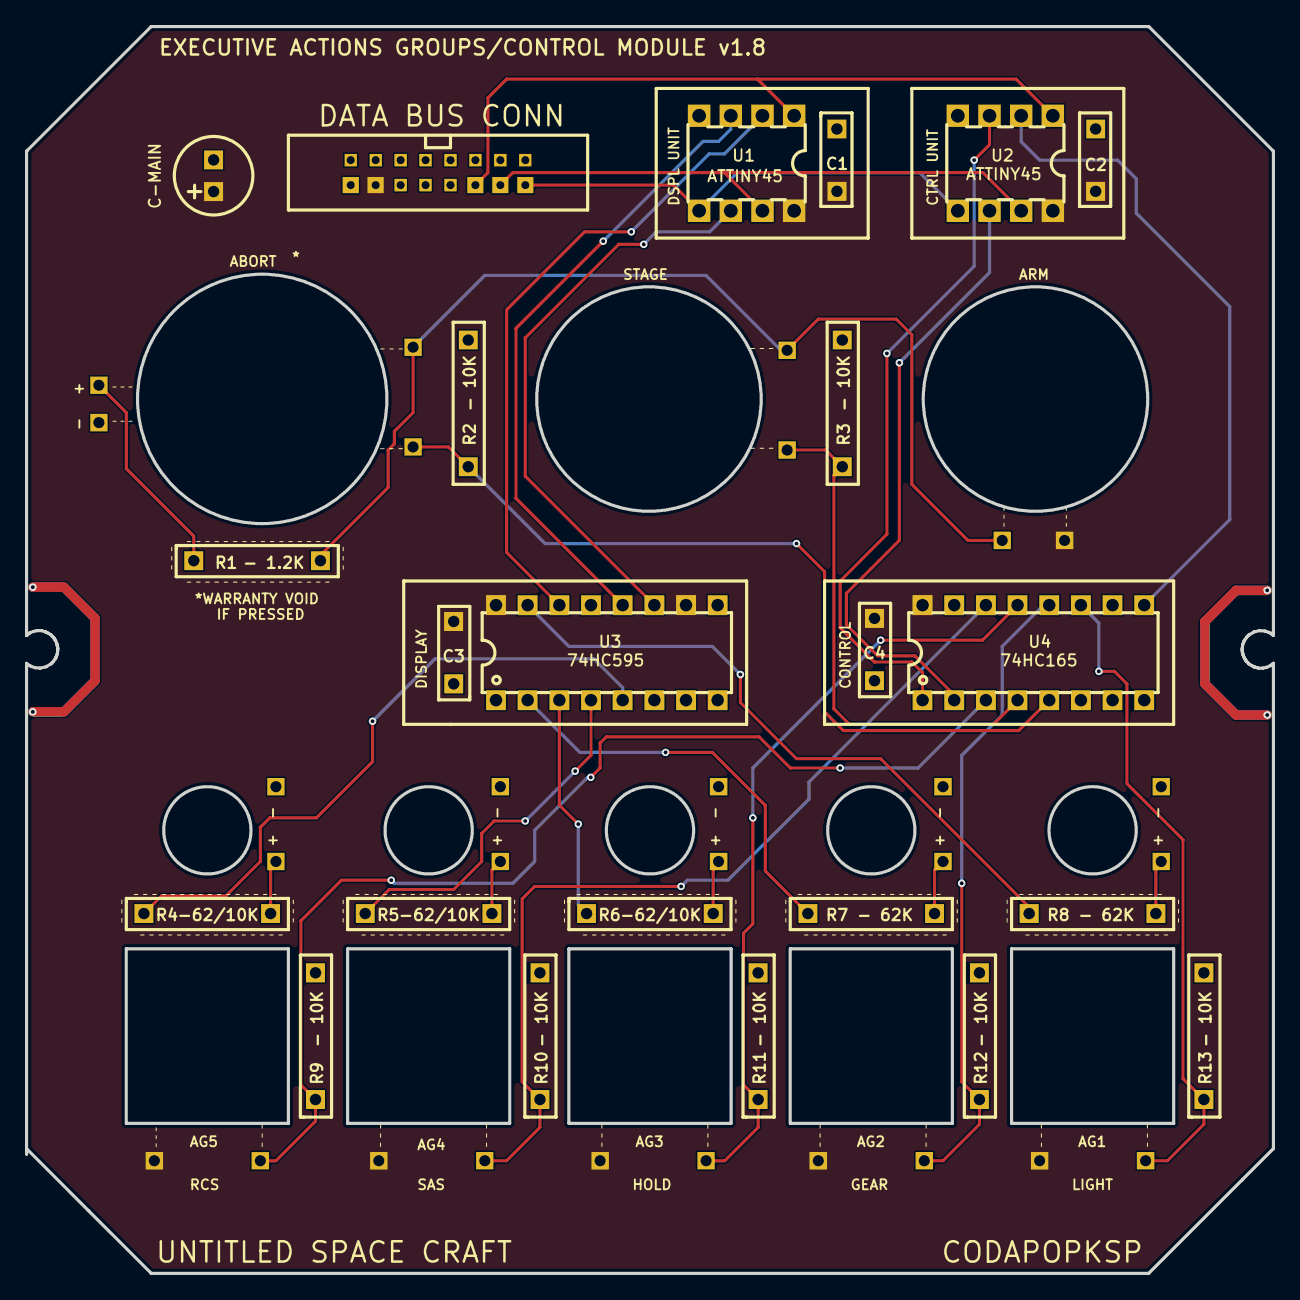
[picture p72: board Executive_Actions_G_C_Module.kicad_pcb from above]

Board: 2 copper layers, 100.0 x 100.0 mm, 66 parts (0 on the bottom side), 30 nets.

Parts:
C1, C2, C3, C4: C104; TH_CAP_5mm
C-MAIN: 10uf; CAP-D6.3×F2.5
R1: - 1.2K; TH_RES_10mm
R2, R3, R5, R9, R10, R11, R12, R13: - 10K; TH_RES_10mm
R4: -62/10K; TH_RES_10mm
R6: - 62/10K; TH_RES_10mm
R7, R8: - 62K; TH_RES_10mm
TP_+5V: WirePad
TP_ABORT: WirePad
TP_ABORTL: WirePad
TP_ARMED: WirePad
TP_GND: WirePad
TP_STAGE: WirePad
U1, U2: ATtiny45; PDIP-8_L9.3-W6.4-P2.54-LS7.6-BL
U3: 74HC595; DIP-16_L20.0-W6.4-P2.54-LS7.6-BL
U4: 74HC165; DIP-16_L20.0-W6.4-P2.54-LS7.6-BL
WP1, WP2, WP3, WP4, WP5, WP6, WP7, WP8, WP9, WP10, WP11, WP12, WP13, WP14, WP15, WP16, WP47, WP55, WP65, WP75, WP82, WP83, WP84, WP85, WP86, WP87, WP88, WP89, WP90, WP91, WP92, WP93, WP94, WP95, WP96, WP97, WP98, WP99: WPAD-1-30AWG; WPAD-1-PTH-30AWG

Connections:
+5V: C1.2, C2.2, C3.2, C4.2, C-MAIN.1, TP_+5V.1, U1.8, U2.8, U3.10, U3.16, U4.16, WP7.1, WP75.1, WP92.1, WP94.1, WP96.1, WP98.1
ABORT: R2.1, TP_ABORT.1, U4.5
ABORTL: R1.1, TP_ABORTL.1
ARMED: R1.2, TP_ARMED.1, WP82.1, WP83.1
BUTTON1: R13.1, U4.11, WP99.1
BUTTON2: R12.1, U4.12, WP97.1
BUTTON3: R11.1, U4.13, WP95.1
BUTTON4: R10.1, U4.14, WP93.1
BUTTON5: R9.1, U4.3, WP65.1
CLOCK(Y): U2.6, U4.2
CLOCK(Y)2: U1.6, U3.11
DATA(P): U2.2, U4.9
DATA(P)2: U1.2, U3.14
GND: C1.1, C2.1, C3.1, C4.1, C-MAIN.2, R2.2, R3.2, R9.2, R10.2, R11.2, R12.2, R13.2, TP_GND.1, U1.4, U2.4, U3.8, U3.13, U4.6, U4.8, U4.15, WP8.1, WP55.1, WP84.1, WP86.1, WP89.1, WP91.1
LATCH(G): U2.3, U4.1
LATCH(G)2: U1.3, U3.12
LIGHT1: R8.1, U3.15
LIGHT2: R7.1, U3.2
LIGHT3: R6.1, U3.3
LIGHT4: R5.1, U3.4
LIGHT5: R4.1, U3.5
RESET: U1.1, U2.1, WP3.1
SCL: U1.7, U2.7, WP2.1
SDA: U1.5, U2.5, WP1.1
STAGE: R3.1, TP_STAGE.1, U4.4
WP47_1: R8.2, WP87.1
WP47_2: R7.2, WP88.1
WP47_3: R6.2, WP90.1
WP47_4: R5.2, WP85.1
WP47_5: R4.2, WP47.1

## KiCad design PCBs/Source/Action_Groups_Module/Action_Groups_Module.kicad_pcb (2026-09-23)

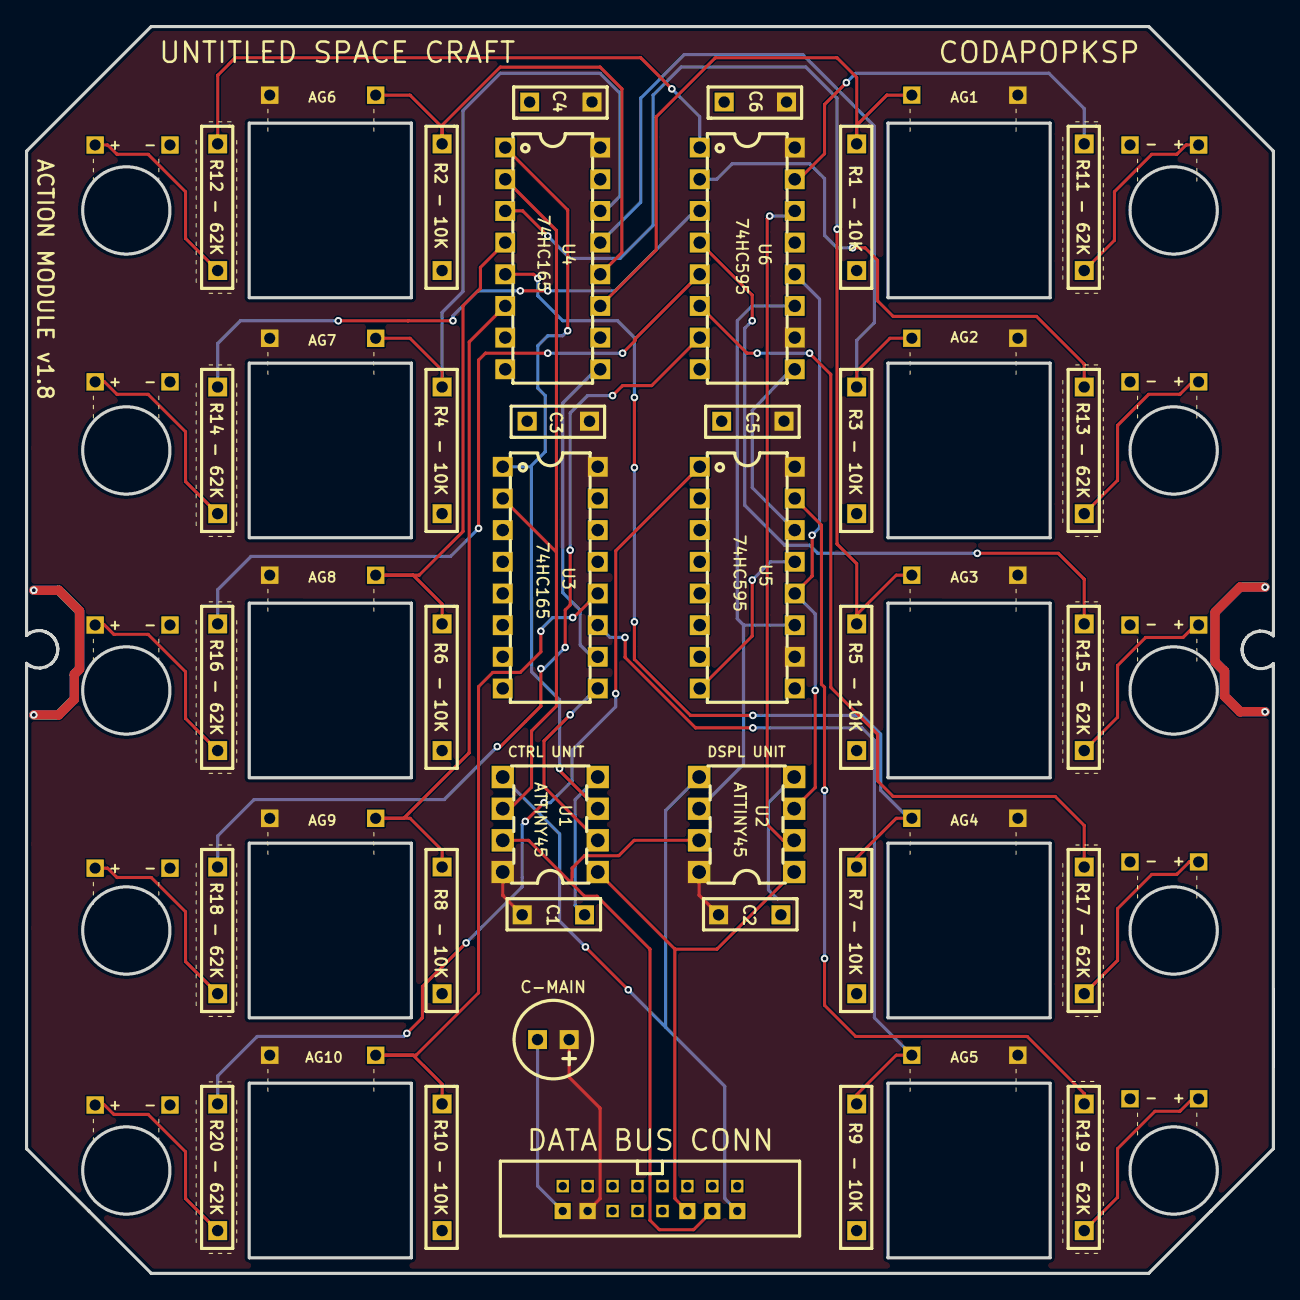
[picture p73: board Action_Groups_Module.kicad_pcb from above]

Board: 2 copper layers, 100.0 x 100.0 mm, 89 parts (0 on the bottom side), 43 nets.

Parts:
C1, C2, C3, C4, C5, C6: C104; TH_CAP_5mm
C-MAIN: 10uf; CAP-D6.3×F2.5
R1, R2, R3, R4, R5, R6, R7, R8, R9, R10: - 10K; TH_RES_10mm
R11, R12, R13, R14, R15, R16, R17, R18, R19, R20: - 62K; TH_RES_10mm
U1, U2: ATtiny45; PDIP-8_L9.3-W6.4-P2.54-LS7.6-BL
U3, U4: 74HC165; DIP-16_L20.0-W6.4-P2.54-LS7.6-BL
U5, U6: 74HC595; DIP-16_L20.0-W6.4-P2.54-LS7.6-BL
WP41, WP42, WP43, WP44, WP45, WP46, WP47, WP48, WP49, WP50, WP51, WP52, WP53, WP54, WP55, WP56, WP57, WP58, WP59, WP60, WP61, WP62, WP63, WP64, WP65, WP66, WP67, WP68, WP69, WP70, WP71, WP72, WP73, WP74, WP75, WP76, WP77, WP78, WP83, WP84, WP85, WP86, WP87, WP88, WP89, WP90, WP91, WP92, WP93, WP94, WP95, WP96, WP97, WP98, WP99, WP100: WPAD-1-30AWG; WPAD-1-PTH-30AWG

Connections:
+5V: C1.2, C2.2, C3.2, C4.2, C5.2, C6.2, C-MAIN.1, U1.8, U2.8, U3.16, U4.16, U5.10, U5.16, U6.10, U6.16, WP71.1, WP72.1, WP73.1, WP74.1, WP75.1, WP76.1, WP77.1, WP78.1, WP83.1, WP84.1, WP92.1
CLOCK(Y): U1.6, U3.2, U4.2
CLOCK(Y)2: U2.6, U5.11, U6.11
DATA(B): U3.10, U4.9
DATA(B)2: U5.14, U6.9
DATA(P): U1.2, U3.9
DATA(P)2: U2.2, U6.14
GND: C1.1, C2.1, C3.1, C4.1, C5.1, C6.1, C-MAIN.2, R1.2, R2.2, R3.2, R4.2, R5.2, R6.2, R7.2, R8.2, R9.2, R10.2, U1.4, U2.4, U3.3, U3.4, U3.5, U3.6, U3.8, U3.13, U3.14, U3.15, U4.8, U4.15, U5.8, U5.13, U6.8, U6.13, WP49.1, WP50.1, WP51.1, WP52.1, WP53.1, WP54.1, WP55.1, WP56.1, WP57.1, WP59.1, WP91.1
LATCH(G): U1.3, U3.1, U4.1
LATCH(G)2: U2.3, U5.12, U6.12
LIGHT1: R11.1, U6.15
LIGHT2: R12.1, U6.1
LIGHT3: R13.1, U6.2
LIGHT4: R14.1, U6.3
LIGHT5: R15.1, U6.4
LIGHT6: R16.1, U6.5
LIGHT7: R17.1, U6.6
LIGHT8: R18.1, U6.7
LIGHT9: R19.1, U5.15
LIGHT10: R20.1, U5.1
RESET: U1.1, U2.1, WP96.1
SAS1: R1.1, U4.11, WP61.1
SAS2: R2.1, U4.12, WP62.1
SAS3: R3.1, U4.13, WP63.1
SAS4: R4.1, U4.14, WP64.1
SAS5: R5.1, U4.3, WP65.1
SAS6: R6.1, U4.4, WP66.1
SAS7: R7.1, U4.5, WP67.1
SAS8: R8.1, U4.6, WP68.1
SAS9: R9.1, U3.11, WP69.1
SAS10: R10.1, U3.12, WP70.1
SCL: U1.7, U2.7, WP97.1
SDA: U1.5, U2.5, WP98.1
WP41_1: R18.2, WP41.1
WP42_1: R17.2, WP42.1
WP43_1: R16.2, WP43.1
WP44_1: R15.2, WP44.1
WP45_1: R14.2, WP45.1
WP46_1: R13.2, WP46.1
WP47_1: R12.2, WP47.1
WP48_1: R11.2, WP48.1
WP58_1: R19.2, WP58.1
WP60_1: R20.2, WP60.1

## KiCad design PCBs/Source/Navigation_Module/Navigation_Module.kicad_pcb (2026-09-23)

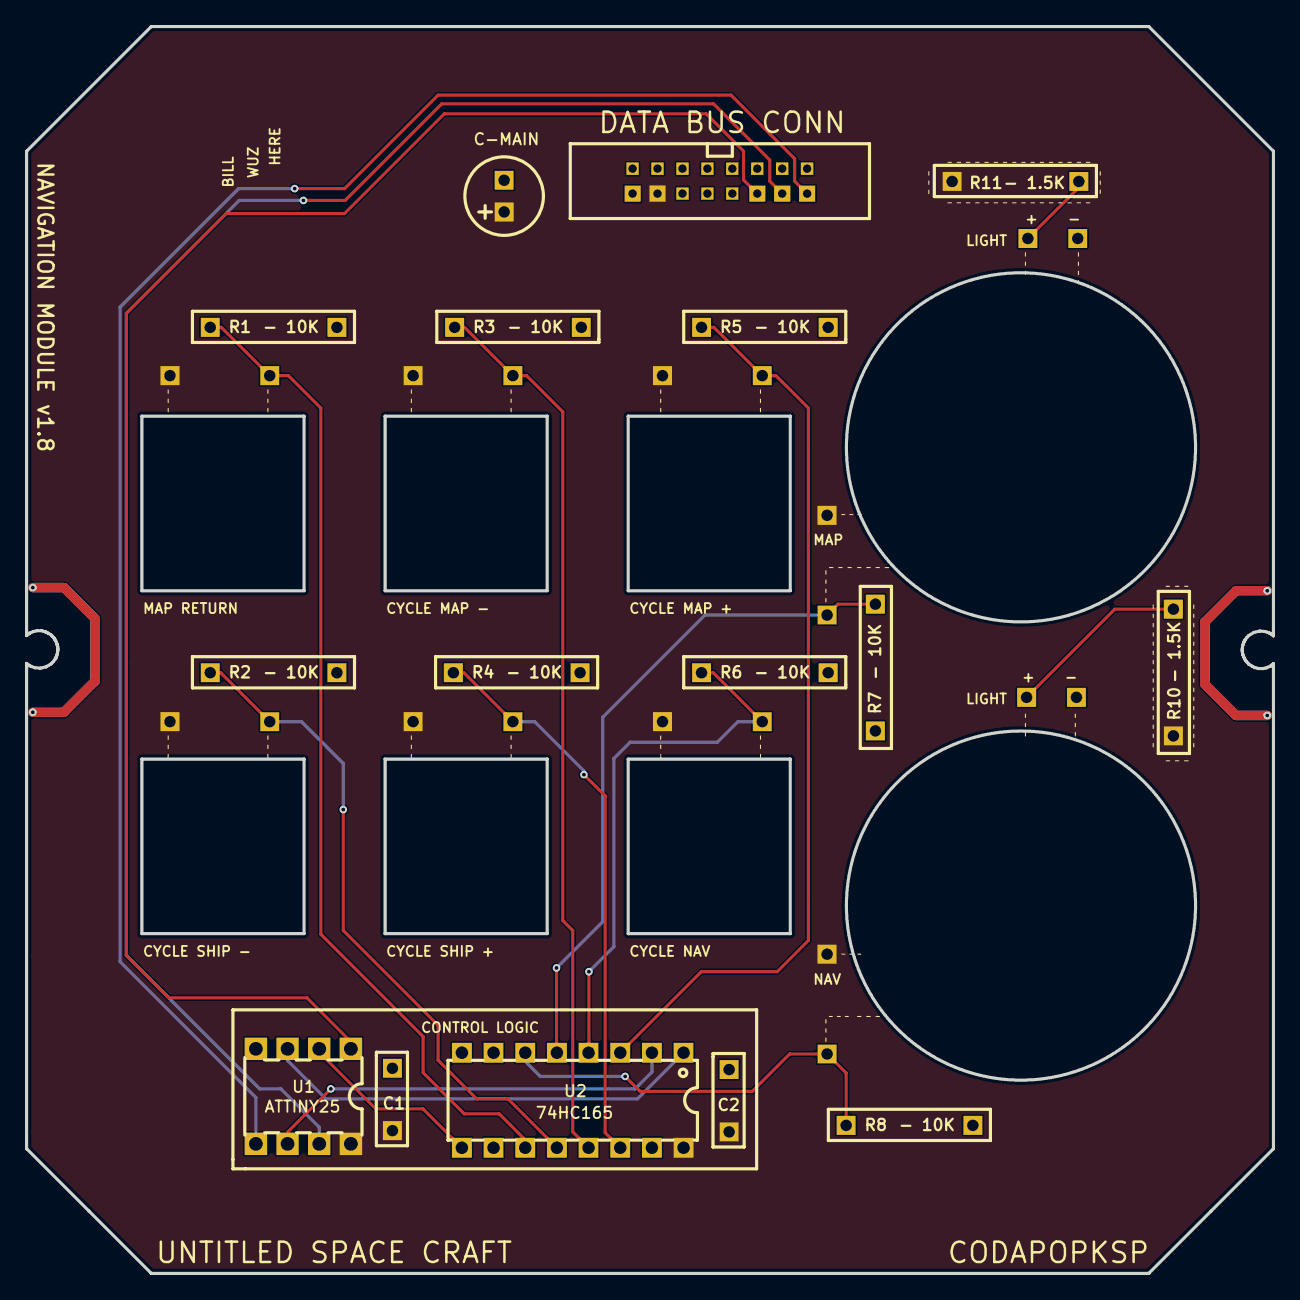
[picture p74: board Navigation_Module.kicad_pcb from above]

Board: 2 copper layers, 100.0 x 100.0 mm, 51 parts (0 on the bottom side), 16 nets.

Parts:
C1, C2: C104; TH_CAP_5mm
C-MAIN: 10uf; CAP-D6.3×F2.5
R1, R2, R3, R4, R5, R6, R7, R8: - 10K; TH_RES_10mm
R10, R11: - 1.5K; TH_RES_10mm
TP_+5V, TP_+5V#2, TP_+5V#3, TP_+5V#4, TP_+5V#5, TP_+5V#6, TP_+5V#7, TP_+5V#8: WirePad
TP_GND: WirePad
TP_GND#2: WirePad
TP_LIGHT1, TP_LIGHT2: WirePad
TP_N1, TP_N2, TP_N3, TP_N4, TP_N5, TP_N6, TP_N7, TP_N8: WirePad
U1: ATtiny25; PDIP-8_L9.3-W6.4-P2.54-LS7.6-BL
U2: 74HC165; DIP-16_L20.0-W6.4-P2.54-LS7.6-BL
WP17, WP18, WP19, WP20, WP21, WP22, WP23, WP24, WP25, WP26, WP27, WP28, WP29, WP30, WP31, WP32: WPAD-1-30AWG; WPAD-1-PTH-30AWG

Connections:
+5V: C1.2, C2.2, C-MAIN.1, R10.1, R11.2, U1.8, U2.16, WP25.1
CLOCK(Y): U1.6, U2.2
DATA(P): U1.2, U2.9
GND: C1.1, C2.1, C-MAIN.2, R1.1, R2.1, R3.1, R4.1, R5.1, R6.1, R7.1, R8.1, U1.4, U2.8, U2.15, WP26.1
LATCH(G): U1.3, U2.1
N1: R1.2, U2.11
N2: R2.2, U2.12
N3: R3.2, U2.13
N4: R4.2, U2.14
N5: R5.2, U2.3
N6: R6.2, U2.4
N7: R7.2, U2.5
N8: R8.2, U2.6
RESET: U1.1, WP21.1
SCL: U1.7, WP20.1
SDA: U1.5, WP19.1

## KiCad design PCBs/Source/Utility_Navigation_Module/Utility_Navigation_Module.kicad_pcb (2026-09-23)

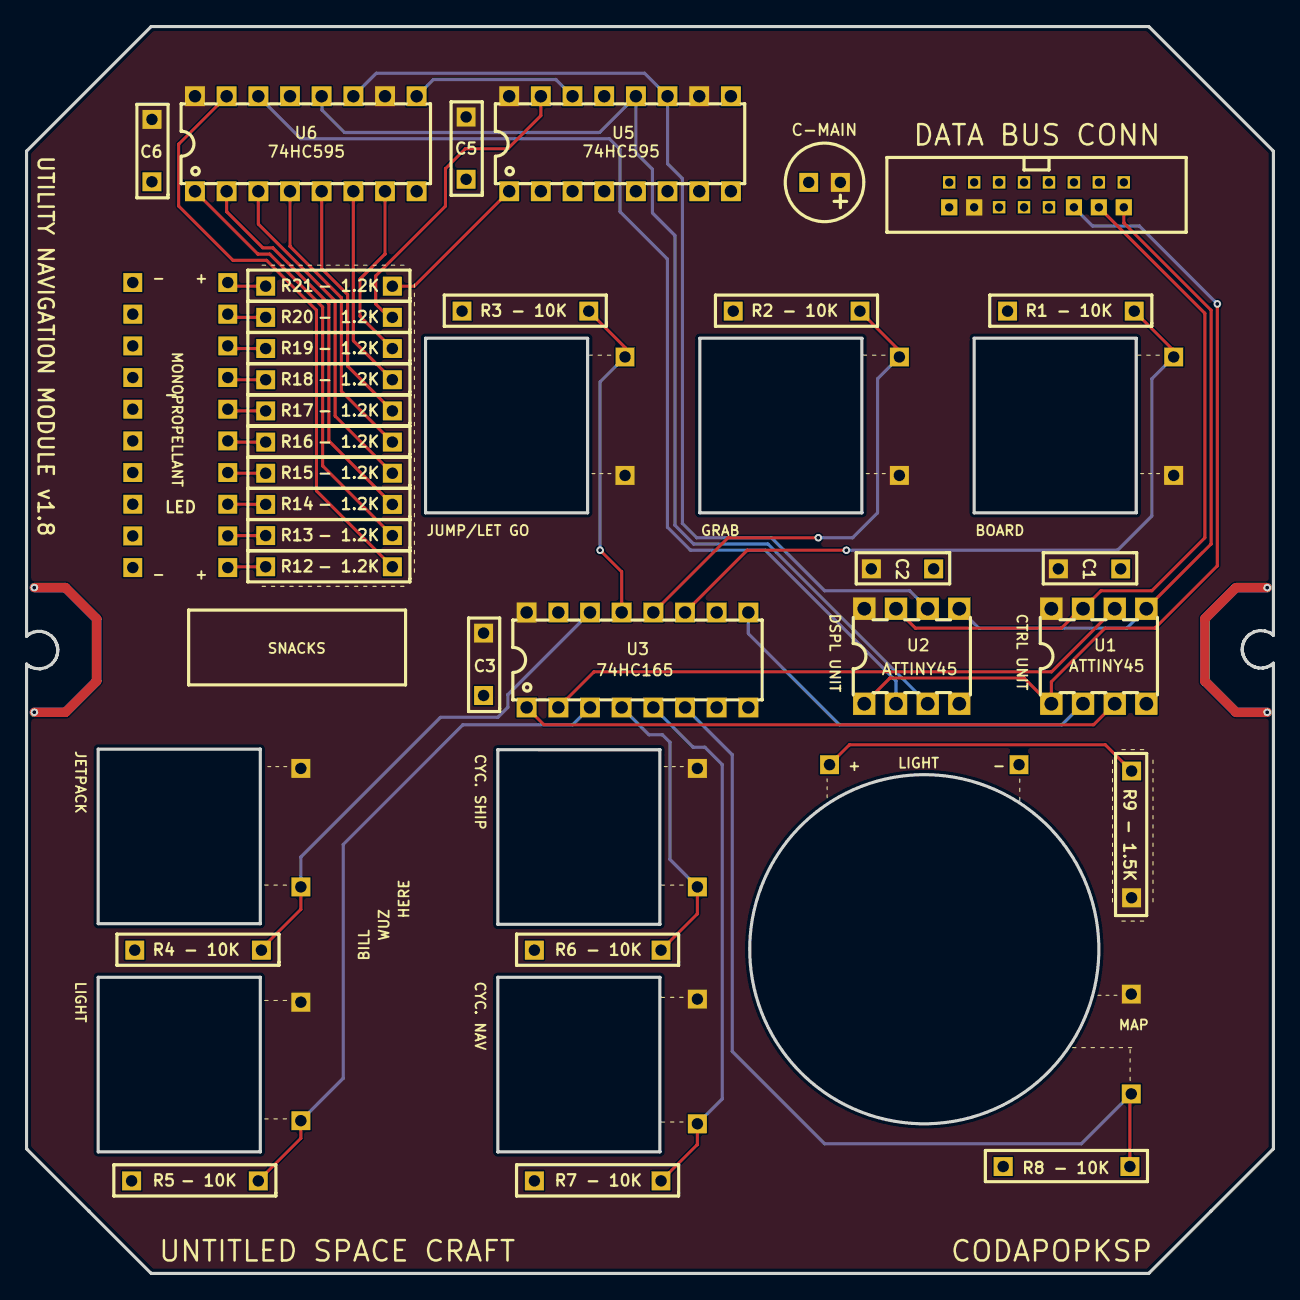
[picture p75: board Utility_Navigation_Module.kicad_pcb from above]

Board: 2 copper layers, 100.0 x 100.0 mm, 65 parts (0 on the bottom side), 40 nets.

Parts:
C1, C2, C3, C5, C6: C104; TH_CAP_5mm
C-MAIN: 10uf; CAP-D6.3×F2.5
LED: _
R1, R2, R3, R4, R5, R6, R7, R8: - 10K; TH_RES_10mm
R9: - 1.5K; TH_RES_10mm
R12, R13, R14, R15, R16, R17, R18, R19, R20, R21: - 1.2K; TH_RES_10mm
TP_+5V, TP_+5V#2, TP_+5V#3, TP_+5V#4, TP_+5V#5, TP_+5V#6, TP_+5V#7, TP_+5V#8: WirePad
TP_EVA1, TP_EVA2, TP_EVA3, TP_EVA4, TP_EVA5: WirePad
TP_GND: WirePad
TP_LIGHT0: WirePad
TP_N1, TP_N2, TP_N3: WirePad
U1, U2: ATtiny45; PDIP-8_L9.3-W6.4-P2.54-LS7.6-BL
U3: 74HC165; DIP-16_L20.0-W6.4-P2.54-LS7.6-BL
U5, U6: 74HC595; DIP-16_L20.0-W6.4-P2.54-LS7.6-BL
WP1, WP2, WP3, WP4, WP5, WP6, WP7, WP8, WP9, WP10, WP11, WP12, WP13, WP14, WP15, WP16: WPAD-1-30AWG; WPAD-1-PTH-30AWG

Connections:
+5V: C1.2, C2.2, C3.2, C5.2, C6.2, C-MAIN.1, R9.2, TP_+5V.8, TP_+5V#4.8, TP_+5V#6.9, TP_+5V#8.15, U1.8, U2.8, U3.16, U5.10, U5.16, U6.10, U6.16, WP7.1
CLOCK(Y): U1.6, U3.2
CLOCK(Y)2: U2.6, U5.11, U6.11
DATA(B)2: U5.14, U6.9
DATA(P): U1.2, U3.9
DATA(P)2: U2.2, U6.14
EVA1: R1.1, TP_EVA1.20, U3.11
EVA2: R2.1, TP_EVA2.18, U3.12
EVA3: R3.1, TP_EVA3.16, U3.13
EVA4: R4.1, TP_EVA4.1, U3.14
EVA5: R5.1, TP_EVA5.1, U3.3
GND: C1.1, C2.1, C3.1, C5.1, C6.1, C-MAIN.2, LED.GND, R1.2, R2.2, R3.2, R4.2, R5.2, R6.2, R7.2, R8.2, U1.4, U2.4, U3.8, U3.15, U5.8, U5.13, U6.8, U6.13, WP8.1
LATCH(G): U1.3, U3.1
LATCH(G)2: U2.3, U5.12, U6.12
LIGHT1: R12.1, U6.15
LIGHT2: R13.1, U6.1
LIGHT3: R14.1, U6.2
LIGHT4: R15.1, U6.3
LIGHT5: R16.1, U6.4
LIGHT6: R17.1, U6.5
LIGHT7: R18.1, U6.6
LIGHT8: R19.1, U6.7
LIGHT9: R20.1, U5.15
LIGHT10: R21.1, U5.1
N1: R6.1, TP_N1.2, U3.4
N2: R7.1, U3.5
N3: R8.1, U3.6
RESET: U1.1, U2.1, WP3.1
SCL: U1.7, U2.7, WP2.1
SDA: U1.5, U2.5, WP1.1
WP41_1: LED.GND, R19.2
WP42_1: LED.GND, R18.2
WP43_1: LED.GND, R17.2
WP44_1: LED.GND, R16.2
WP45_1: LED.GND, R15.2
WP46_1: LED.GND, R14.2
WP47_1: LED.GND, R13.2
WP48_1: LED.GND, R12.2
WP58_1: LED.GND, R20.2
WP60_1: LED.GND, R21.2

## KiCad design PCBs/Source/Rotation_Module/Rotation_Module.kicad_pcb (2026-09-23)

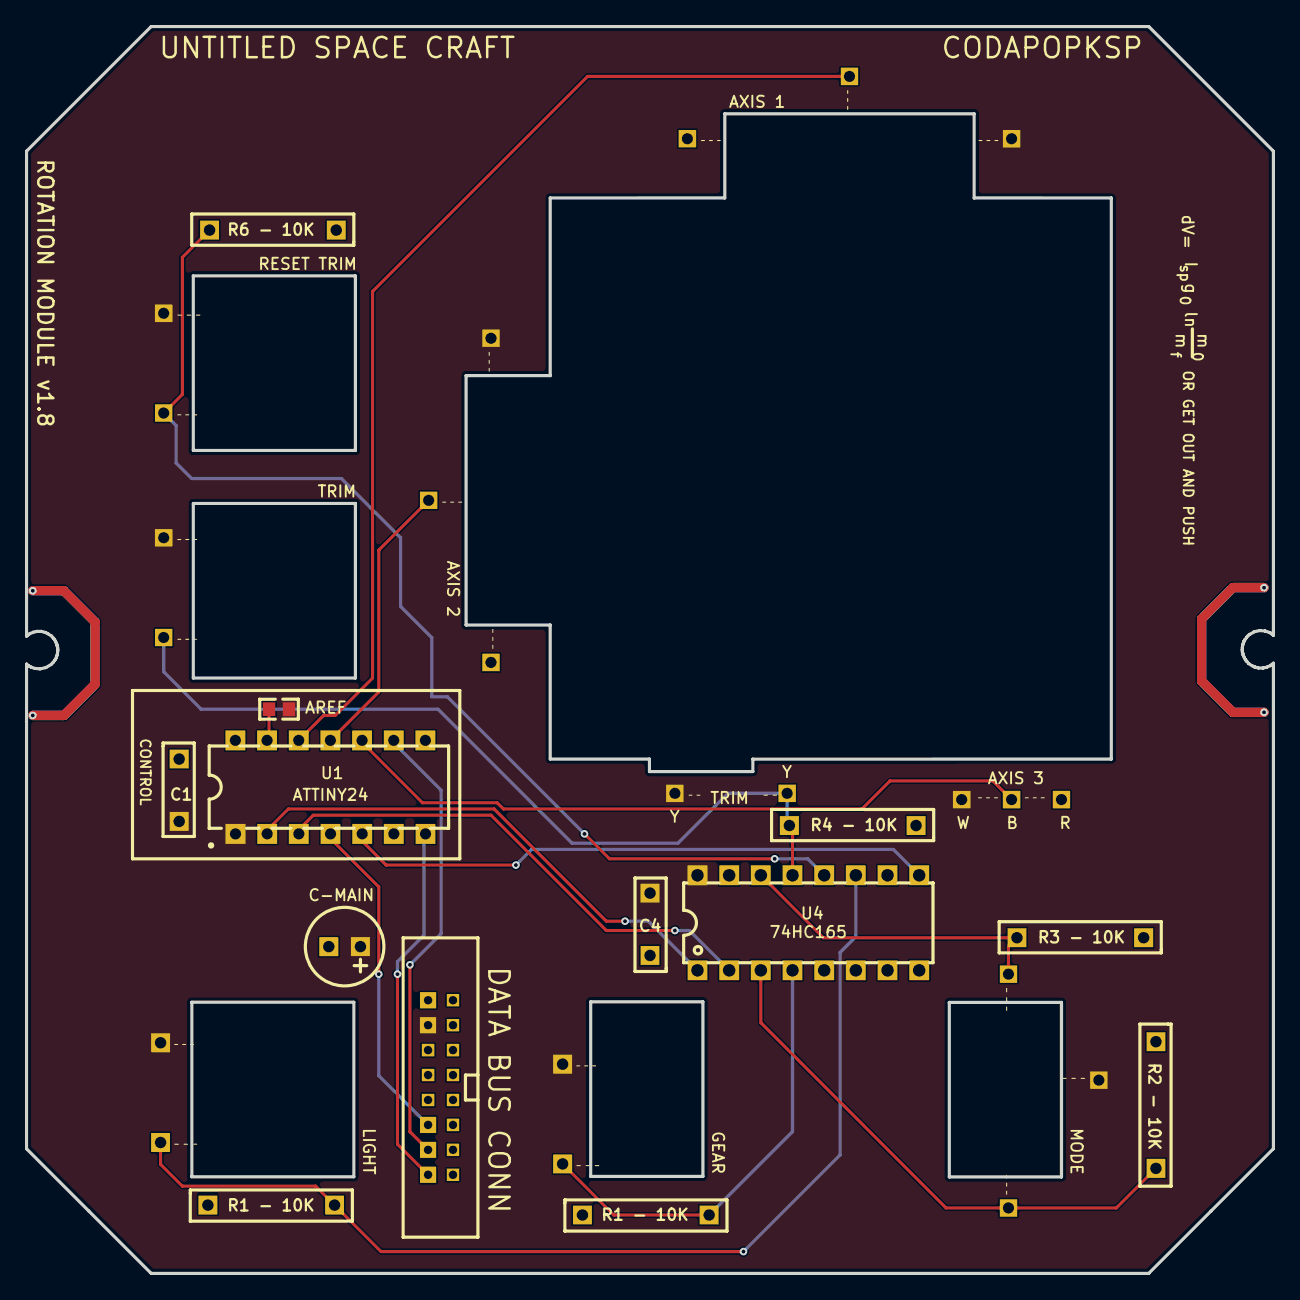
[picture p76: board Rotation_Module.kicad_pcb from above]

Board: 2 copper layers, 100.0 x 100.0 mm, 63 parts (0 on the bottom side), 18 nets.

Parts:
AREF: 10k; R0603
C1, C4: C104; TH_CAP_5mm
C-MAIN: 10uf; CAP-D6.3×F2.5
R1, R1#2, R2, R3, R4, R6: - 10K; TH_RES_10mm
TP_+5V, TP_+5V#2, TP_+5V#3, TP_+5V#4, TP_+5V#5, TP_+5V#6, TP_+5V#7, TP_+5V#8, TP_+5V#9, TP_+5V#10: WirePad
TP_AREF: WirePad
TP_AXIS1, TP_AXIS1#2, TP_AXIS2, TP_AXIS2#2, TP_AXIS3, TP_AXIS3#2: WirePad
TP_CLOCK_Y_: WirePad
TP_CRUISE: WirePad
TP_DATA_P_: WirePad
TP_GEAR: WirePad
TP_GND: WirePad
TP_GND#2, TP_GND#3, TP_GND#4: WirePad
TP_LATCH_G_: WirePad
TP_LIGHTS: WirePad
TP_MODE1, TP_MODE2: WirePad
TP_Pad_gge45412: WirePad
TP_RESET: WirePad
TP_RESETTRIM: WirePad
TP_SCL: WirePad
TP_SDA: WirePad
TP_TRIM: WirePad
TP_TRIM#2: WirePad
U4: 74HC165; DIP-16_L20.0-W6.4-P2.54-LS7.6-BL
WP11, WP24, WP25, WP38, WP39, WP43, WP44, WP45, WP46, WP47, WP48, WP49, WP50, WP51, WP52, WP53: WPAD-1-30AWG; WPAD-1-PTH-30AWG

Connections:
+5V: AREF.2, C1.2, C4.2, C-MAIN.1, TP_+5V.1, TP_+5V#2.1, TP_+5V#3.1, TP_+5V#4.1, TP_+5V#5.1, TP_+5V#6.1, TP_+5V#7.1, TP_+5V#8.1, TP_+5V#9.1, TP_+5V#10.1, U4.16, WP46.1
AREF: AREF.1, TP_AREF.13
AXIS1: TP_AXIS1.12, TP_AXIS1#2.1
AXIS2: TP_AXIS2.11, TP_AXIS2#2.1
AXIS3: TP_AXIS3.10, TP_AXIS3#2.1
CLOCK(Y): TP_CLOCK_Y_.3, U4.2
DATA(P): TP_DATA_P_.5, U4.9
GEAR: R1#2.2, TP_GEAR.1, U4.4
GND: C1.1, C4.1, C-MAIN.2, R1.1, R1#2.1, R2.1, R3.1, R4.1, R6.1, TP_GND.1, TP_GND#2.1, TP_GND#3.14, TP_GND#4.1, U4.5, U4.6, U4.8, U4.15, WP45.1
LATCH(G): TP_LATCH_G_.2, U4.1
LIGHTS: R1.2, TP_LIGHTS.1, U4.11
MODE1: R3.2, TP_MODE1.1, U4.14
MODE2: R2.2, TP_MODE2.1, U4.3
RESET: TP_RESET.4, WP50.1
RESETTRIM: R6.2, TP_RESETTRIM.1, U4.12
SCL: TP_SCL.9, WP51.1
SDA: TP_SDA.7, WP52.1
TRIM: R4.2, TP_TRIM.1, TP_TRIM#2.1, U4.13

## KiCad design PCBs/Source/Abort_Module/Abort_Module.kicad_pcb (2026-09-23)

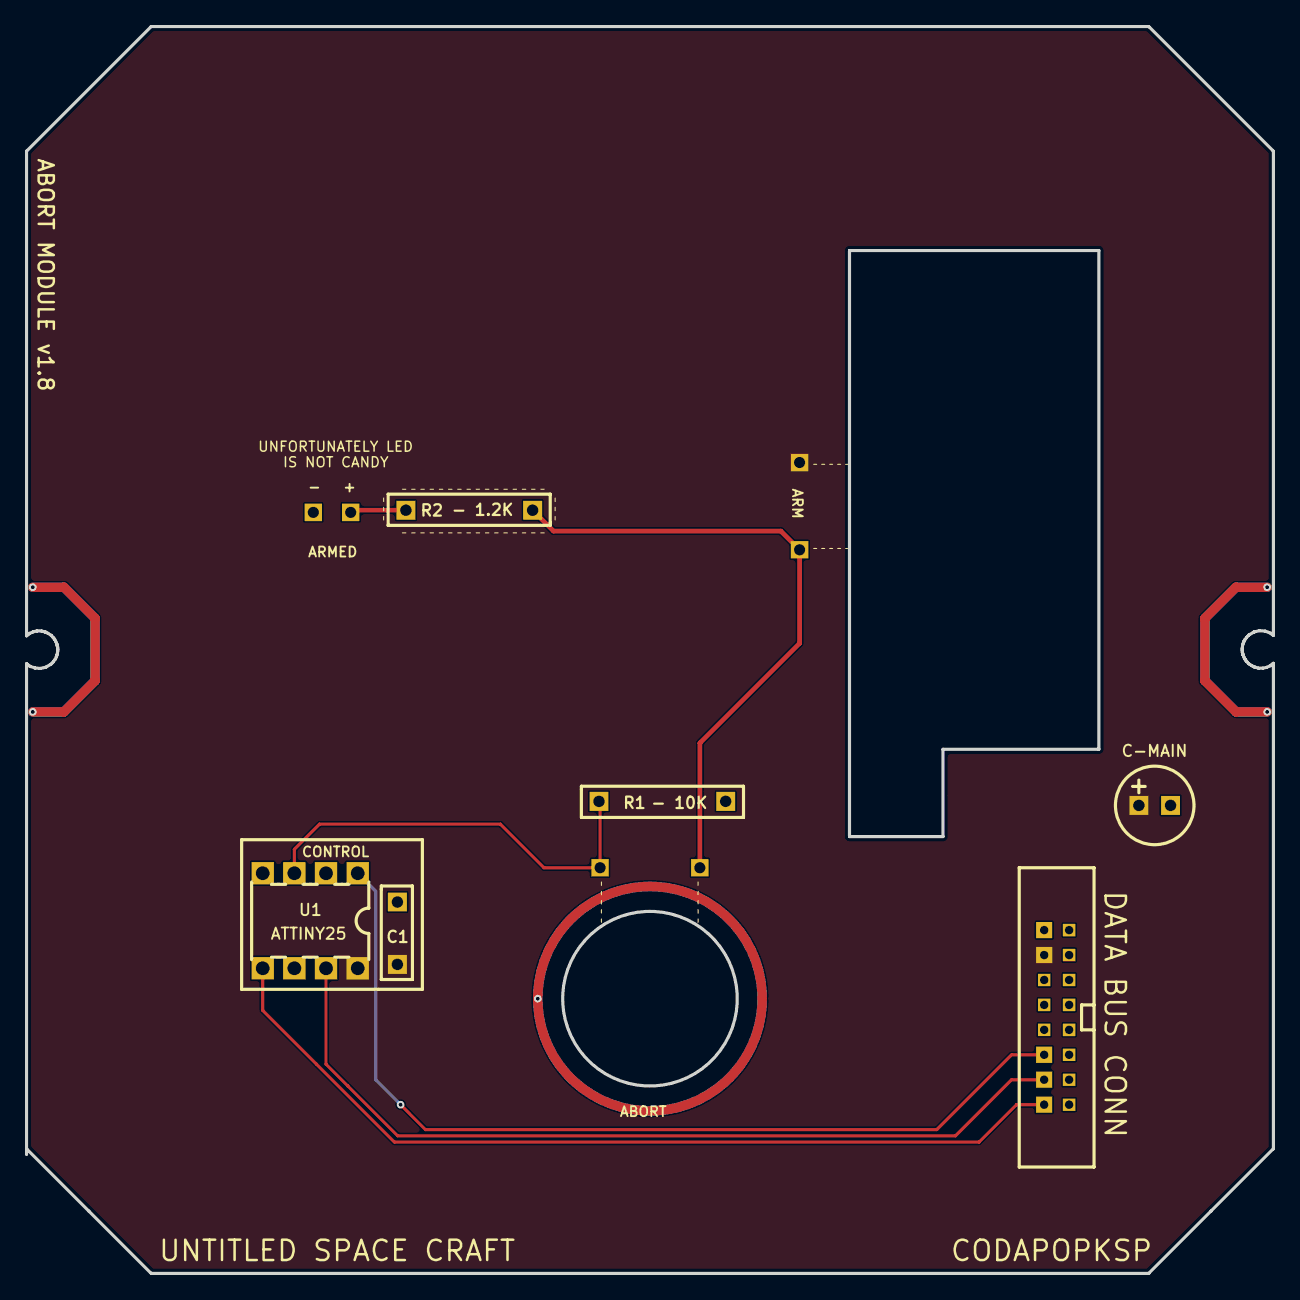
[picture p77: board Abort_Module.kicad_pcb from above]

Board: 2 copper layers, 100.0 x 100.0 mm, 27 parts (0 on the bottom side), 8 nets.

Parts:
C1: C104; TH_CAP_5mm
C-MAIN: 1u; CAP-D6.3×F2.5
R1: - 10K; TH_RES_10mm
R2: - 1.2K; TH_RES_10mm
TP_+5V: WirePad
TP_ARMED: WirePad
TP_GND: WirePad
TP_LIGHT: WirePad
TP_STAGE: WirePad
U1: ATtiny25; PDIP-8_L9.3-W6.4-P2.54-LS7.6-BL
WP84, WP85, WP86, WP87, WP88, WP89, WP90, WP91, WP92, WP93, WP94, WP95, WP96, WP97, WP98, WP99, WP100: WPAD-1-30AWG; WPAD-1-PTH-30AWG

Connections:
+5V: C1.2, C-MAIN.1, TP_+5V.1, U1.8, WP92.1
ARMED: R2.1, TP_ARMED.1, WP100.1
GND: C1.1, C-MAIN.2, R1.2, TP_GND.1, U1.4, WP93.1
LIGHT: R2.2, TP_LIGHT.1
RESET: U1.1, WP88.1
SCL: U1.7, WP87.1
SDA: U1.5, WP86.1
STAGE: R1.1, TP_STAGE.1, U1.3

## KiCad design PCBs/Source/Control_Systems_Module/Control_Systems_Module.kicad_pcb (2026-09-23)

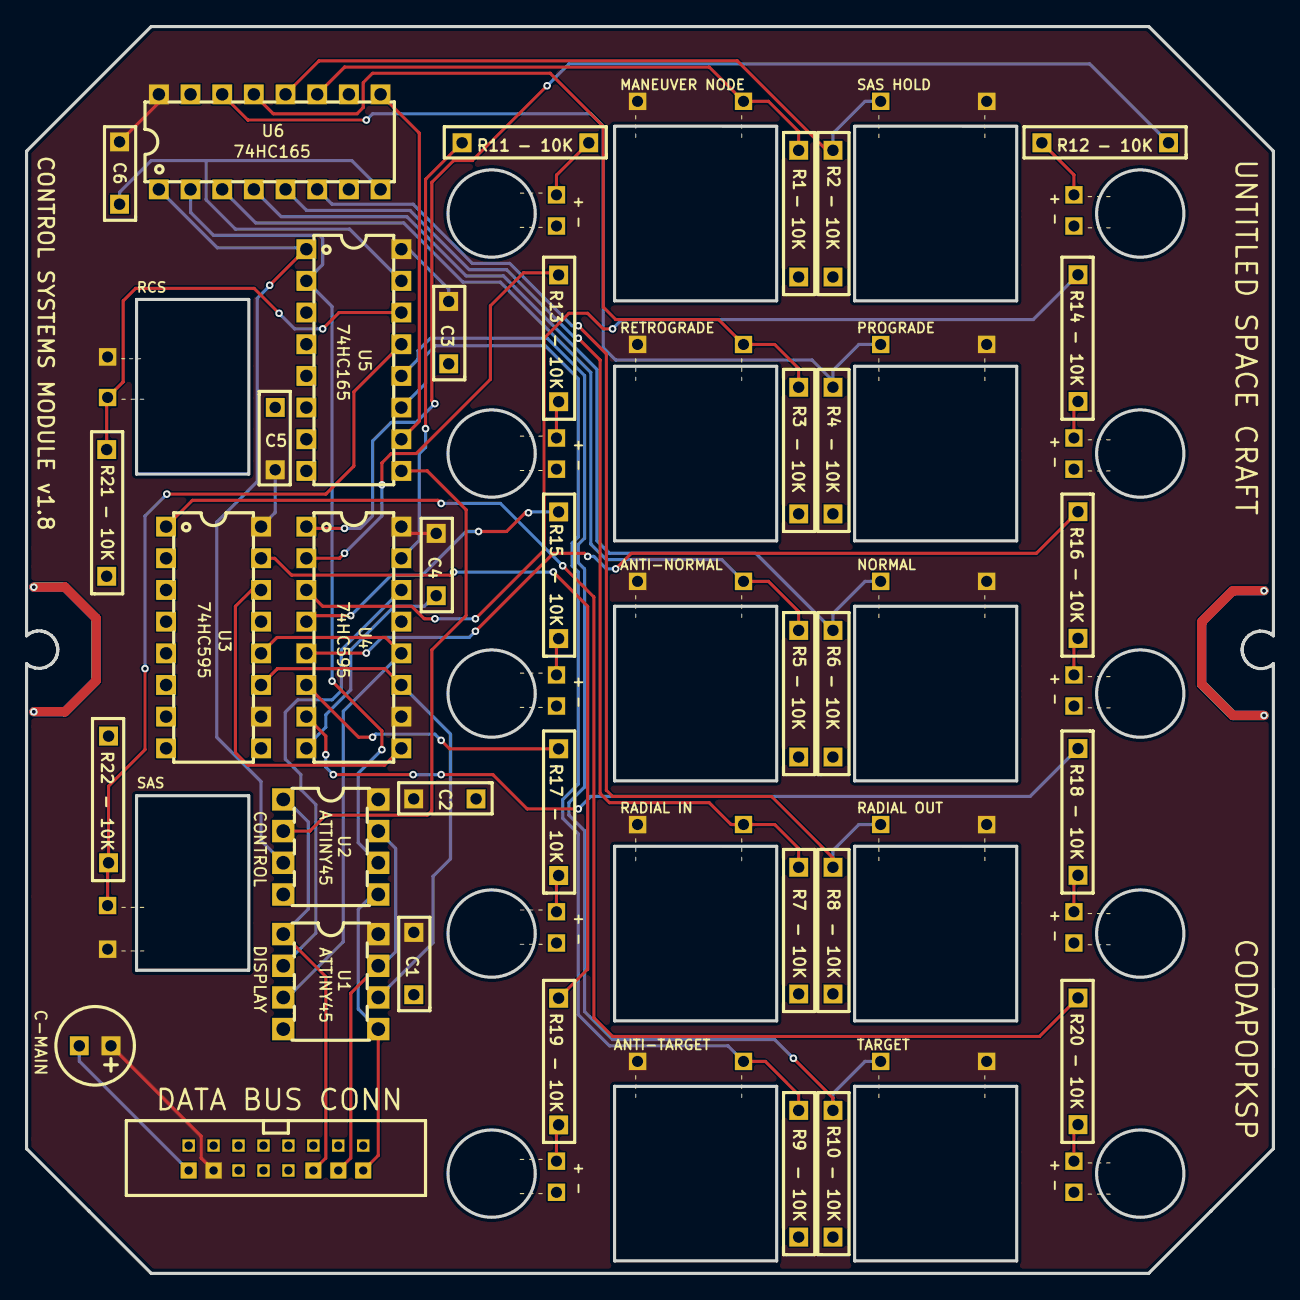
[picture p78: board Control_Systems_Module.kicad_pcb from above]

Board: 2 copper layers, 100.0 x 100.0 mm, 95 parts (0 on the bottom side), 45 nets.

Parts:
C1, C2, C3, C4, C5, C6: C104; TH_CAP_5mm
C-MAIN: 10uf; CAP-D6.3×F2.5
R1, R2, R3, R4, R5, R6, R7, R8, R9, R10, R11, R12, R13, R14, R15, R16, R17, R18, R19, R20, R21, R22: - 10K; TH_RES_10mm
U1, U2: ATtiny45; PDIP-8_L9.3-W6.4-P2.54-LS7.6-BL
U3, U4: 74HC595; DIP-16_L20.0-W6.4-P2.54-LS7.6-BL
U5, U6: 74HC165; DIP-16_L20.0-W6.4-P2.54-LS7.6-BL
WP1, WP2, WP3, WP4, WP5, WP6, WP7, WP8, WP9, WP10, WP11, WP12, WP13, WP14, WP15, WP16, WP41, WP42, WP43, WP44, WP45, WP46, WP47, WP48, WP49, WP50, WP51, WP52, WP53, WP54, WP55, WP56, WP57, WP58, WP59, WP60, WP61, WP62, WP63, WP64, WP65, WP66, WP67, WP68, WP69, WP70, WP71, WP72, WP73, WP74, WP75, WP76, WP77, WP78, WP79, WP80, WP81, WP82, WP83, WP84: WPAD-1-30AWG; WPAD-1-PTH-30AWG

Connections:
+5V: C1.2, C2.2, C3.2, C4.2, C5.2, C6.2, C-MAIN.1, U1.8, U2.8, U3.10, U3.16, U4.10, U4.16, U5.16, U6.16, WP7.1, WP71.1, WP72.1, WP73.1, WP74.1, WP75.1, WP76.1, WP77.1, WP78.1, WP81.1, WP82.1, WP83.1, WP84.1
CLOCK(Y): U2.6, U5.2, U6.2
CLOCK(Y)2: U1.6, U3.11, U4.11
DATA(B): U5.10, U6.9
DATA(B)2: U3.14, U4.9
DATA(P): U2.2, U5.9
DATA(P)2: U1.2, U4.14
GND: C1.1, C2.1, C3.1, C4.1, C5.1, C6.1, C-MAIN.2, R1.1, R2.1, R3.1, R4.1, R5.1, R6.1, R7.1, R8.1, R9.1, R10.1, R21.1, R22.1, U1.4, U2.4, U3.8, U3.13, U4.8, U4.13, U5.3, U5.4, U5.5, U5.6, U5.8, U5.15, U6.8, U6.15, WP8.1, WP49.1, WP50.1, WP51.1, WP52.1, WP53.1, WP54.1, WP55.1, WP56.1, WP57.1, WP59.1
LATCH(G): U2.3, U5.1, U6.1
LATCH(G)2: U1.3, U3.12, U4.12
LIGHT1: R11.2, U4.15
LIGHT2: R12.1, U4.1
LIGHT3: R13.2, U4.2
LIGHT4: R14.1, U4.3
LIGHT5: R15.2, U4.4
LIGHT6: R16.1, U4.5
LIGHT7: R17.2, U4.6
LIGHT8: R18.1, U4.7
LIGHT9: R19.2, U3.15
LIGHT10: R20.1, U3.1
RCS: R21.2, U5.14, WP80.1
RESET: U1.1, U2.1, WP3.1
SAS: R22.2, U5.13, WP79.1
SAS1: R1.2, U6.11, WP61.1
SAS2: R2.2, U6.12, WP62.1
SAS3: R3.2, U6.13, WP63.1
SAS4: R4.2, U6.14, WP64.1
SAS5: R5.2, U6.3, WP65.1
SAS6: R6.2, U6.4, WP66.1
SAS7: R7.2, U6.5, WP67.1
SAS8: R8.2, U6.6, WP68.1
SAS9: R9.2, U5.11, WP69.1
SAS10: R10.2, U5.12, WP70.1
SCL: U1.7, U2.7, WP2.1
SDA: U1.5, U2.5, WP1.1
WP41_1: R18.2, WP41.1
WP42_1: R17.1, WP42.1
WP43_1: R16.2, WP43.1
WP44_1: R15.1, WP44.1
WP45_1: R14.2, WP45.1
WP46_1: R13.1, WP46.1
WP47_1: R12.2, WP47.1
WP48_1: R11.1, WP48.1
WP58_1: R19.1, WP58.1
WP60_1: R20.2, WP60.1

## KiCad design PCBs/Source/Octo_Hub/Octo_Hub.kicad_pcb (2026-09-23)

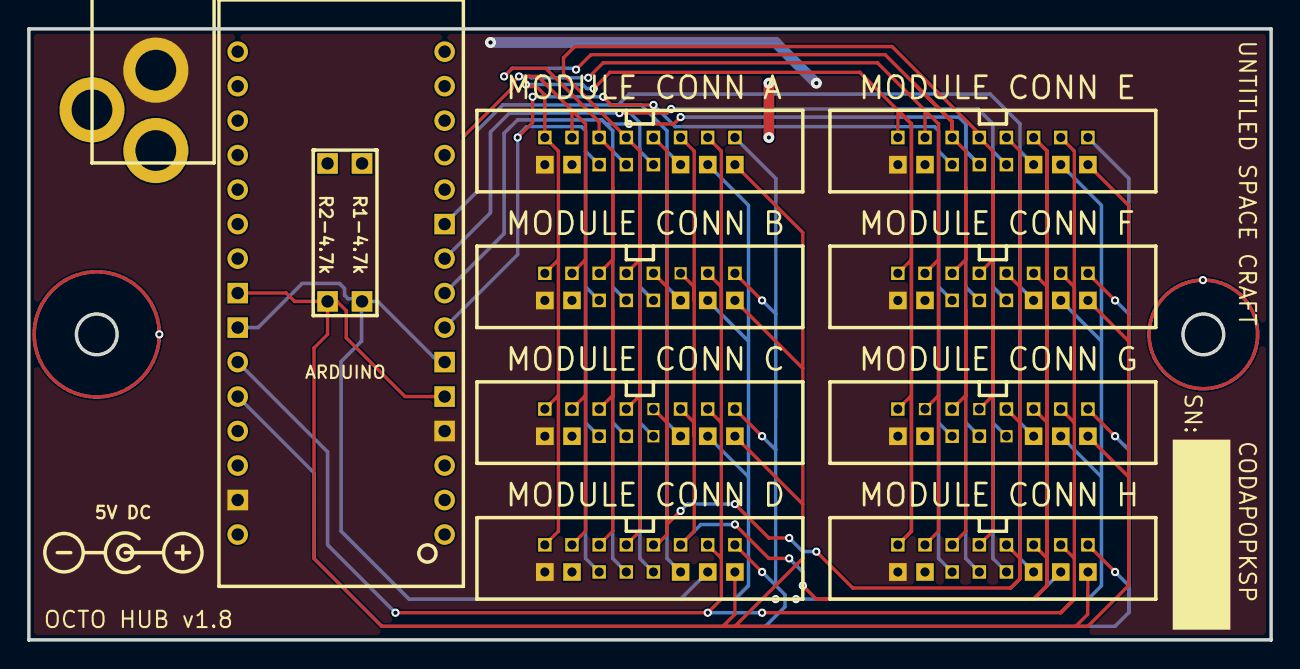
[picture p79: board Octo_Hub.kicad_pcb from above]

Board: 2 copper layers, 91.5 x 45.0 mm, 132 parts (0 on the bottom side), 16 nets.

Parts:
ARDUINO: Arduino_Nano_Header; DIP-30_L43.18-W15.24-ARDUINONANO
NONE: _
NONEAWD: _
U1: PJ-102A
WP17, WP18, WP19, WP20, WP21, WP22, WP23, WP24, WP25, WP26, WP27, WP28, WP29, WP30, WP31, WP32, WP33, WP34, WP35, WP36, WP37, WP38, WP39, WP40, WP41, WP42, WP43, WP44, WP45, WP46, WP47, WP48, WP49, WP50, WP51, WP52, WP53, WP54, WP55, WP56, WP57, WP58, WP59, WP60, WP61, WP62, WP63, WP64, WP65, WP66, WP67, WP68, WP69, WP70, WP71, WP72, WP73, WP74, WP75, WP76, WP77, WP78, WP79, WP80, WP81, WP82, WP83, WP84, WP85, WP86, WP87, WP88, WP89, WP90, WP91, WP92, WP93, WP94, WP95, WP96, WP97, WP98, WP99, WP100, WP101, WP102, WP103, WP104, WP105, WP106, WP107, WP108, WP109, WP110, WP111, WP112, WP113, WP114, WP115, WP116, WP117, WP118, WP119, WP120, WP121, WP122, WP123, WP124, WP125, WP126, WP127, WP128, WP129, WP130, WP131, WP132, WP133, WP134, WP135, WP136, WP137, WP138, WP139, WP140, WP141, WP142, WP143, WP144: WPAD-1-30AWG; WPAD-1-PTH-30AWG

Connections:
+5V: NONE.2, NONE.4, U1.TIP, WP24.1, WP41.1, WP57.1, WP73.1, WP89.1, WP104.1, WP120.1, WP136.1
ANALOG0: WP20.1, WP45.1, WP61.1, WP77.1, WP93.1, WP100.1, WP116.1, WP132.1
ANALOG1: WP19.1, WP46.1, WP62.1, WP78.1, WP94.1, WP99.1, WP115.1, WP131.1
ANALOG2: WP18.1, WP47.1, WP63.1, WP79.1, WP95.1, WP98.1, WP114.1, WP130.1
ANALOG3: WP32.1, WP33.1, WP49.1, WP65.1, WP81.1, WP112.1, WP128.1, WP144.1
ANALOG4: ARDUINO.25, WP31.1, WP34.1, WP50.1, WP66.1, WP82.1, WP111.1, WP127.1, WP143.1
ANALOG5: ARDUINO.26, WP17.1, WP48.1, WP64.1, WP80.1, WP96.1, WP97.1, WP113.1, WP129.1
DIGITAL0: WP22.1, WP43.1, WP59.1, WP75.1, WP91.1, WP102.1, WP118.1, WP134.1
DIGITAL1: WP21.1, WP44.1, WP60.1, WP76.1, WP92.1, WP101.1, WP117.1, WP133.1
DIGITAL2: ARDUINO.7, WP25.1, WP40.1, WP56.1, WP72.1, WP88.1, WP105.1, WP121.1, WP137.1
DIGITAL3: ARDUINO.8, WP26.1, WP39.1, WP55.1, WP71.1, WP87.1, WP106.1, WP122.1, WP138.1
DIGITAL4: ARDUINO.9, WP27.1, WP38.1, WP54.1, WP70.1, WP86.1, WP107.1, WP123.1, WP139.1
GND: ARDUINO.4, ARDUINO.29, U1.RING, WP23.1, WP42.1, WP58.1, WP74.1, WP90.1, WP103.1, WP119.1, WP135.1
RESET: ARDUINO.10, WP28.1, WP37.1, WP53.1, WP69.1, WP85.1, WP108.1, WP124.1, WP140.1
SCL: ARDUINO.6, ARDUINO.24, NONE.5, WP29.1, WP36.1, WP52.1, WP68.1, WP84.1, WP109.1, WP125.1, WP141.1
SDA: ARDUINO.5, ARDUINO.23, NONE.3, WP30.1, WP35.1, WP51.1, WP67.1, WP83.1, WP110.1, WP126.1, WP142.1

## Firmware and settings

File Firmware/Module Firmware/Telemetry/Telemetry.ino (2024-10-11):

#include <Arduino.h>
#include <U8g2lib.h>
#ifdef U8X8_HAVE_HW_SPI
#include <SPI.h>
#endif
#include <Wire.h>

String ap = "0";
String apTime = "0";
String pe = "0";
String peTime = "0";

String input0 = "0";
String input1 = "0";
String input2 = "0";
String input3 = "0";
String input4 = "0";
String input5 = "0";

#define own_address 40
#define alt_vel_button 9
#define mnvr_button 8
#define orbit_button 7
#define fuel_button 6

byte mode = 4;

// End of constructor list
U8G2_ST7920_128X64_1_SW_SPI u8g2(U8G2_R2, /* clock=*/ 11 /* A4 */ , /* data=*/ 13 /* A2 */, /* CS=*/ 10 /* A3 */, /* reset=*/ U8X8_PIN_NONE);

void setup(void) {
  pinMode(alt_vel_button, INPUT);
  pinMode(mnvr_button, INPUT);
  pinMode(orbit_button, INPUT);
  pinMode(fuel_button, INPUT);
  u8g2.begin();
  Wire.begin(own_address);
  Wire.onReceive(onI2CReceive);
  Wire.onRequest(onI2CRequest);
  Serial.begin(9600);
}

void loop(void) {
  u8g2.firstPage();
  do {
    if (input0 == "X") {
      mode = 4;
    }
    if (digitalRead(alt_vel_button)) {
      mode = 1;
    }
    if (digitalRead(mnvr_button)) {
      mode = 2;
    }
    if (digitalRead(orbit_button)) {
      mode = 3;
    }
    if (digitalRead(fuel_button)) {
      mode = 0;
    }
    u8g2.setFont(u8g2_font_6x10_tf);
    if (mode == 0) {
      displayFuel(input0, input1, input2, input3, input4, input5);
    }
    else if (mode == 1) {
      drawApsides(ap, apTime, pe, peTime);
      displayTelemetry(input0, input1, input2, input3, input4, input5);
    }
    else if (mode == 2) {
      drawApsides(ap, apTime, pe, peTime);
      displayMnvrInfo(input0, input1, input2, input3, input5);
    }
    else if (mode == 3) {
      drawApsides(ap, apTime, pe, peTime);
      displayOrbitInfo(input0, input1, input2, input3);
    }
    else if (mode == 4) {
      u8g2.clearDisplay();
    }
  } while ( u8g2.nextPage() );
}

void onI2CRequest() {
  Wire.write(mode);
}

void onI2CReceive(int byteCount) {
  int messType = Wire.read();
  if (messType == 0) {
    readWireData(input0);
    readWireData(input1);
    readWireData(input2);
  } else if (messType == 1) {
    readWireData(input3);
    readWireData(input4);
    readWireData(input5);
  } else {
    readWireData(ap);
    readWireData(pe);
    readWireData(apTime);
    readWireData(peTime);
  }
}

void readWireData(String& input) {
  int packetSize = Wire.read();
  char packets[packetSize+1];
  for (int i = 0; i < packetSize; i++) {
    packets[i] = Wire.read();
  }
  packets[packetSize] = '\0';
  input = packets;
}

void displayOrbitInfo(String sma, String eccent, String inclin, String period) {
  drawOrbitLines();
  drawInfo("SMA", 11, getUnits(sma));
  drawInfo("ECCNT", 27, eccent);
  drawInfo("INCLN", 43, inclin);
  drawInfo("PERIOD", 59, formatSeconds(period));
}

void drawOrbitLines() {
  u8g2.drawHLine(82, 31, 44);
  u8g2.drawVLine(82, 0, 64);
  u8g2.drawVLine(36, 0, 64);
  u8g2.drawHLine(36, 15, 46);
  u8g2.drawHLine(36, 31, 46);
  u8g2.drawHLine(36, 47, 46);
}


void displayMnvrInfo(String dV, String timeToM, String burnTime, String totalMdV, String shipdV) {
  drawMnvrLines();
  drawMnvrNodeInfo(41, 8, "NEXT MNVR");
  drawMnvrNodeInfo(41, 18, getUnits(dV));
  drawMnvrNodeInfo(41, 28, formatSeconds(timeToM));
  drawMnvrNodeInfo(41, 38, burnTime + "s");
  drawInfo("ALL MV", 52, getUnits(totalMdV));
  drawInfo("dV", 63, getUnits(shipdV));
}

void drawMnvrNodeInfo(int x, int y, String value) {
  int width;
  width = u8g2.getStrWidth(value.c_str());
  u8g2.drawStr(x-width/2, y, value.c_str());
}

void drawMnvrLines() {
  u8g2.drawHLine(82, 31, 44);
  u8g2.drawVLine(82, 0, 64);
  u8g2.drawVLine(36, 42, 22);
  u8g2.drawHLine(0, 42, 82);
  u8g2.drawHLine(36, 53, 46);
}

void displayTelemetry(String altSea, String altSurf, String velOrb, String velSurf, String velVert, String shipdV) {
  drawTelemLines();
  drawInfo("A-SEA", 8, getUnits(altSea));
  drawInfo("A-SRF", 19, getUnits(altSurf));
  drawInfo("V-OBT", 30, getUnits(velOrb));
  drawInfo("V-SRF", 41, getUnits(velSurf));
  drawInfo("V-VRT", 52, getUnits(velVert));
  drawInfo("dV", 63, getUnits(shipdV));
}

void drawTelemLines() {
  u8g2.drawHLine(82, 31, 44);
  u8g2.drawVLine(82, 0, 64);
  u8g2.drawVLine(36, 0, 64);
  u8g2.drawHLine(36, 9, 46);
  u8g2.drawHLine(36, 20, 46);
  u8g2.drawHLine(36, 31, 46);
  u8g2.drawHLine(36, 42, 46);
  u8g2.drawHLine(36, 53, 46);
}

void drawInfo(String iName, int vPos, String value) {
  int width;
  width = u8g2.getStrWidth(iName.c_str());
  u8g2.drawStr(17-width/2, vPos, iName.c_str());
  width = u8g2.getStrWidth(value.c_str());
  u8g2.drawStr(80-width, vPos, value.c_str());
}

void drawApsides(String ap_, String apTime_, String pe_, String peTime_) {
  u8g2.drawStr(100, 9, "AP");
  ap_ = getUnits(ap_);
  apTime_ = formatSeconds(apTime_);
  int width = u8g2.getStrWidth(ap_.c_str());
  u8g2.drawStr(126-(width), 19, ap_.c_str());
  width = u8g2.getStrWidth(apTime_.c_str());
  u8g2.drawStr(126-(width), 29, apTime_.c_str());
  
  u8g2.drawStr(100, 41, "PE");
  pe_ = getUnits(pe_);
  peTime_ = formatSeconds(peTime_);
  width = u8g2.getStrWidth(pe_.c_str());
  u8g2.drawStr(126-(width), 51, pe_.c_str());
  width = u8g2.getStrWidth(peTime_.c_str());
  u8g2.drawStr(126-(width), 61, peTime_.c_str());
}

String formatSeconds(String secondsChar) {
  unsigned long seconds = strtoul(secondsChar.c_str(), NULL, 10);
  if (seconds >= 21600) {
    int days = seconds / 21600;
    return String(days) + "d";
  }
  int hours = seconds / 3600;
  int minutes = (seconds % 3600) / 60;
  seconds = seconds % 60;
  String minutesStr = (minutes < 10) ? "0" + String(minutes) : String(minutes);
  String secondsStr = (seconds < 10) ? "0" + String(seconds) : String(seconds);
  return String(hours) + ":" + minutesStr + ":" + secondsStr;
}

String getUnits(String value) {
  int stringLength = value.length();
  if (stringLength > 13) {
    value.remove(stringLength - 12, 12);
    value += " Tm";
  }
  if (stringLength > 10) {
    value.remove(stringLength - 9, 9);
    value += " Gm";
  }
  else if (stringLength > 7) {
    value.remove(stringLength - 6, 6);
    value += " Mm";
  }
  else if (stringLength > 4) {
    value.remove(stringLength - 3, 3);
    value += " km";
  }
  else {
    value = value + " m";
  }
  return value;
}

void displayFuel(String LF, String OX, String SF, String EC, String XE, String MP) {
  u8g2.drawHLine(2, 54, 124);
  drawFuelGauge(16, "LF", LF.toInt());
  drawFuelGauge(37, "OX", OX.toInt());
  drawFuelGauge(58, "SF", SF.toInt());
  drawFuelGauge(79, "EC", EC.toInt());
  drawFuelGauge(100, "XE", XE.toInt());
  drawFuelGauge(121, "MP", MP.toInt());
  u8g2.drawVLine(21, 0, 64);
  u8g2.drawVLine(42, 0, 64);
  u8g2.drawVLine(63, 0, 64);
  u8g2.drawVLine(84, 0, 64);
  u8g2.drawVLine(105, 0, 64);
}

void drawFuelGauge(int vert, String fuelName, int fuel) {
  drawFuelBox(vert-10, fuel);
  u8g2.drawStr(vert-10, 64, fuelName.c_str());
  u8g2.drawHLine(vert, 0, 2);
  u8g2.drawHLine(vert, 12, 2);
  u8g2.drawHLine(vert, 25, 2);
  u8g2.drawHLine(vert, 37, 2);
  u8g2.drawHLine(vert, 51, 2);
}

void drawFuelBox(int pos, int fuel) {
  int difference = 52 - fuel;
  u8g2.drawBox(pos, difference, 10, fuel);
}

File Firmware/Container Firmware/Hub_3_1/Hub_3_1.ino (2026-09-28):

#include <Wire.h>
#include <Keyboard.h>
#include "KerbalSimpit.h"
#include "settings.h"
#include "definitions.h"
#include "actionResults.h"

KerbalSimpit mySimpit(Serial);
unsigned long lastDebounceTime_w = 0;

// Connection-lost detection: if no Simpit message for this long, re-run init().
unsigned long lastSimpitMessageAt = 0;

// Returns true if any button was pressed (emulation mode triggered).
bool checkEmuButton(bool connected, int address, int bytes) {
  if (!connected) return false;
  Wire.requestFrom(address, bytes);
  if (Wire.available() < bytes) {
    while (Wire.available()) Wire.read();
    return false;
  }
  bool anyPressed = false;
  for (int j = 0; j < bytes; j++) {
    if (Wire.read() != 0) anyPressed = true;
  }
  if (anyPressed) {
    keyboardEmulation = true;
    Keyboard.releaseAll();
    return true;
  }
  return false;
}

//|-------------------|
//|       Main        |
//|-------------------|

void setup() {
  // Initialize Modules
  Wire.begin();
  // Connect to Simpit
  Serial.begin(115200);

  // Turn on Keyboard Emulation.
  // Keyboard.begin() prevents the board from enumerating as a keyboard on macOS.
  #if OPERATING_SYSTEM != MAC
    Keyboard.begin();
  #endif
  delay(1500);
  
  // Reset Modules
  digitalWrite(Reset, LOW);
  delay(100);
  digitalWrite(Reset, HIGH);
  delay(1000);

  // Check for Connected Modules
  checkConnections();
  allZero();

  // If any connected module has a button pressed during init -> emulation mode
  while (!mySimpit.init()) {
    if (checkEmuButton(Action_Ctrl_Con, Action_Ctrl_, TWO_BYTES)) break;
    if (checkEmuButton(Action2_Ctrl_Con, Action2_Ctrl_, TWO_BYTES)) break;
    if (checkEmuButton(Action3_Ctrl_Con, Action3_Ctrl_, TWO_BYTES)) break;
    if (checkEmuButton(Ctrl_Sys_Ctrl_Con, Ctrl_Sys_Ctrl_, TWO_BYTES)) break;
    if (checkEmuButton(Navigation_Con, Navigation_, ONE_BYTE)) break;
    if (checkEmuButton(Navigation_Time_Ctrl_Con, Navigation_Time_Ctrl_, ONE_BYTE)) break;
    if (checkEmuButton(Time_Ctrl_Con, Time_Ctrl_, ONE_BYTE)) break;
    if (checkEmuButton(Stage_Con, Stage_, ONE_BYTE)) break;
    if (checkEmuButton(Abort_Con, Abort_, ONE_BYTE)) break;
    if (checkEmuButton(Executive_Actions_Con, Executive_Actions_, ONE_BYTE)) break;
    if (checkEmuButton(EA_Groups_Ctrl_Con, EA_Groups_Ctrl_, ONE_BYTE)) break;
    if (checkEmuButton(EA_Control_Ctrl_Con, EA_Control_Ctrl_, ONE_BYTE)) break;
    if (checkEmuButton(EVA_Ctrl_Con, EVA_Ctrl_, TWO_BYTES)) break;
    if (checkEmuButton(Util_Nav_Ctrl_Con, Util_Nav_Ctrl_, ONE_BYTE)) break;
    if (checkEmuButton(Util_Time_Ctrl_Con, Util_Time_Ctrl_, ONE_BYTE)) break;
    if (checkEmuButton(Camera_Con, Camera_, TWO_BYTES)) break;
    delay(10);
  }
  Keyboard.releaseAll();
  
  if (!keyboardEmulation) {
    if (mySimpit.connectedToKSP2()) {
      KSP2 = true;
      Nav_KSP1_KSP2 = KEY_HOME;
    }
    mySimpit.printToKSP(F("Connected to KSP"), PRINT_TO_SCREEN);
    lastSimpitMessageAt = millis();
    // Register Channels
    registerMessageChannels();
    // Register Telemetry for LCD
    if (LCD_Con) {
      registerTelemetryChannels();
    }
  }

  // Setup Analogs
  if (Rotation_Throttle_Con or Translation_Con or Rotation_Con or Analog_Con or Analog_Throttle_Con) {
    analogSetup();
    Keyboard.releaseAll();
  }
}

void loop() {

  if (!keyboardEmulation) {
    // Get Updates from Simpit
    mySimpit.update();
    // If no message for a while, connection likely lost — re-run init to reconnect
    if (millis() - lastSimpitMessageAt > SIMPIT_CONNECTION_TIMEOUT_MS) {
      Keyboard.releaseAll();
      allZero();
      while (!mySimpit.init()) {delay(10);}
      lastSimpitMessageAt = millis();
      registerMessageChannels();
      if (LCD_Con) registerTelemetryChannels();
    }
  }

  // Module Transmissions and Actions
  if (((millis() - lastDebounceTime_w) > update_time) and (isFlying)) {
    if (Rotation_Throttle_Con or Rotation_Con) {
      readRotation();
    }
    if (Translation_Con) {
      readTranslation();
    }
    if (Throttle_Con) {
      readThrottle();
    }
    if (Analog_Throttle_Con or Analog_Con) {
      readAnalog();
    }
    transmissions();
    actions();
    lastDebounceTime_w = millis();
  }

  if (!keyboardEmulation) {
    // Handle EVA buttons
    if (Translation_Con) {
      if (On_EVA) {
        EVA_Button_LAST = true;
      }
      if (!On_EVA and EVA_Button_LAST) {
        for (int i = 0; i < 11; i++) {
          Keyboard.release(EVA_List_Analog[i]);
        }
        EVA_Button_LAST = false;
      }
    }
    
    // Scene Change
    if (!isFlying) {
      Keyboard.releaseAll();
      allZero();
    }
  }
}

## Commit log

2024-10-11 Add USC project files.
    [I2C Addresses.ods, Wiring Standards.ods]
2024-12-15 Increase module laser cut magnet holes slightly.
2026-06-19 Add schematics
    [Abort_Module.kicad_sch, Action_Groups_Module.kicad_sch, Analog_Module.kicad_sch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]
2026-06-19 Add BoM and Utility Schematics.
    [BoM.ods, I2C Addresses.ods, Utility_Navigation_Module.kicad_sch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]
2026-06-19 Update BoM
    [Abort_Module.kicad_sch, Action_Groups_Module.kicad_sch, Analog_Module.kicad_sch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]
2026-06-20 Update documentation
    [BoM.ods, EVA_Module.kicad_sch, I2C Addresses.ods]
2026-06-22 Update docs
    [BoM.ods]
2026-08-10 Added STL for throttle and guard
    Added STL for throttle and guard from a discord chat with Codapop
    [Throttle Guard.stl, Throttle Lever.stl]
2026-08-10 Changed names of housings
    changed names of module housings
2026-08-19 Update docs. Add STLs.
    [BoM.ods, I2C Addresses.ods, Throttle Guard.stl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]
2026-08-31 Reorganize files
    [Throttle Guard.stl, Throttle Lever.stl]
2026-08-31 Update docs organization
    [BoM.ods, I2C Addresses.ods, Wiring Standards.ods]
2026-09-23 Link PCBs to schematics in KiCAD. Deprecate old EasyEDA PCB files. Update PCB Gerbers to v1.8.
    [Abort_Module-BoardOutLine.gbr, Abort_Module-BottomLayer.gbr, Abort_Module-BottomPasteMaskLayer.gbr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]
